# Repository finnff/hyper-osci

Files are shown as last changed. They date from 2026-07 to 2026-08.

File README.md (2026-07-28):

# HYPEROSCI

**4 battery-powered, WiFi-synchronized oscilloscopes drawing vector graphics in X/Y mode — for live performance.**

Each of the 4 slave units drives one analog oscilloscope with a stereo audio signal (L = X, R = Y). A central controller (Arduino UNO-Q running Debian) renders osci-render-style vectors as 48 kHz audio and streams it over its own WiFi access point. When the network is gone, every slave falls back within ~6 s to the proven standalone mode: its own microphone drives the scope as an audio-reactive Lissajous visualizer. No laptop on stage, no venue WiFi needed.

## Architecture

```
                     phone browser (web UI, http://192.168.50.1:8080)
                                      │
                                      ▼
        ┌─────────────────────────────────────────────┐
        │        Arduino UNO-Q  (Debian, QRB2210)     │
        │  renderer ─▶ streamer ─▶ WiFi AP (2.4 GHz)  │
        │        SSID HYPEROSCI_AP · 192.168.50.1     │
        └───────┬─────────┬──────────┬─────────┬──────┘
        UDP :5000 audio (unicast ×4) · :5001 sync/cmd · :5002 status
                │         │          │         │
                ▼         ▼          ▼         ▼
          ┌─────────┐ ┌─────────┐ ┌─────────┐ ┌─────────┐
          │ slave 1 │ │ slave 2 │ │ slave 3 │ │ slave 4 │   ESP32-C3 SuperMini
          │         │ │         │ │         │ │         │   + PCM5102A I2S DAC
          │ mic ────┤ │ mic ────┤ │ mic ────┤ │ mic ────┤   + MAX4466 mic (fallback)
          └────┬────┘ └────┬────┘ └────┬────┘ └────┬────┘   + LiPo/TP4056, custom THT carrier PCB
           X/Y ▼       X/Y ▼       X/Y ▼       X/Y ▼
          ┌─────────┐ ┌─────────┐ ┌─────────┐ ┌─────────┐
          │ scope 1 │ │ scope 2 │ │ scope 3 │ │ scope 4 │   analog scopes in X/Y mode
          └─────────┘ └─────────┘ └─────────┘ └─────────┘
```

Sync target ±5 ms via 500 ms beacons; the stream deliberately runs ~450 ms ahead of playback (512 ms slave jitter buffer) to ride out the UNO-Q radio's periodic ~300 ms stalls — latency is irrelevant for scope art, only slave-to-slave sync matters; stream loss > 1 s → automatic local-mic fallback.

## Documentation

**[docs/DESIGN.md](docs/DESIGN.md) is the single source of truth.** Where any other doc disagrees, DESIGN.md wins.

| Doc | What it is |
|-----|---|
| [docs/DESIGN.md](docs/DESIGN.md) | Canonical decisions: pin map, modules, modes, power, network (LAW) |
| [docs/PLAN.md](docs/PLAN.md) | 5-week execution plan (Jul 17 → Aug 21), critical path, risks, shopping list |
| [docs/protocol.md](docs/protocol.md) | Normative wire protocol (with [src/esp32-slave/include/protocol.h](src/esp32-slave/include/protocol.h)) |
| [docs/hardware/wiring.md](docs/hardware/wiring.md) | Complete hookup guide + bring-up checklist (breadboard now, PCB later) |
| [docs/hardware/pcb.md](docs/hardware/pcb.md) | Carrier PCB: full BOM, power path, layout notes |
| [docs/hardware/power-budget.md](docs/hardware/power-budget.md) | Current draw, battery life, low-battery policy derivation |
| [docs/firmware/esp32-architecture.md](docs/firmware/esp32-architecture.md) | Slave firmware architecture (tasks, drivers, buffers) |
| [docs/osci-render-feature-port-feasibility.md](docs/osci-render-feature-port-feasibility.md) | What else is worth porting from osci-render (fonts, SVG, effects), measured on the board — and the 6 bugs found while looking, all now fixed (§1) |
| [docs/performance-heat-analysis.md](docs/performance-heat-analysis.md) | Why the slave runs hot and why streaming dropped (2026-07-18), with the prioritized fix plan |
| [docs/hardware/pcb-review-findings.md](docs/hardware/pcb-review-findings.md) | 2026-07-26 adversarial design review of the carrier's §4 power path (findings + verdicts) |
| [docs/research/](docs/research/) | Historical planning docs — superseded where they conflict with DESIGN.md |

Research index: [v3.md](docs/research/v3.md) (feasibility) · [v3.1-requirements.md](docs/research/v3.1-requirements.md) (confirmed requirements) · [v3.2-dual-dac.md](docs/research/v3.2-dual-dac.md) (DAC selection) · [UNO-Q_controller.md](docs/research/UNO-Q_controller.md) (controller architecture — note: its whole software stack is illustrative and was NOT built as described: no FastAPI/WebSocket/hostapd, and its 5 GHz AP config is wrong — see DESIGN.md §2 and src/unoq-controller/README.md for what exists) · [esp32-c3-vs-s3.md](docs/research/esp32-c3-vs-s3.md) · [arduino-uno-r4-option.md](docs/research/arduino-uno-r4-option.md) · [README-original.md](docs/research/README-original.md)

## Hardware summary

Per slave (modules socketed on a custom ~70 × 50 mm through-hole carrier PCB — see [docs/hardware/pcb.md](docs/hardware/pcb.md)):

| Module | Role |
|---|---|
| ESP32-C3 SuperMini | MCU, WiFi, I2S master |
| GY-PCM5102A | 24-bit stereo I2S DAC → scope X/Y via 2× RCA pads (X = L, Y = R), ground-centered DC-coupled |
| MAX4466 | electret mic (on a ~10 cm pigtail) for fallback/hybrid mode |
| TP4056 (USB-C, with protection) + EEMB LP103454 LiPo 3.7 V 2000 mAh | power (~13 h NETWORK / ~30 h LOCAL) |

Scope output is 2× RCA flying-lead pads (X = DAC L, Y = DAC R, series R fitted as 0 Ω links — the DAC module already carries ~470 Ω of its own) driving reused ~50 cm RCA cables into each scope's existing BNC→RCA adapter — no BNC/TRS on our board. Enclosure: 3D-printed case (4× M3 mounts), LiPo mounted off-PCB.

Controls per unit: power switch, mode button (NETWORK / LOCAL / HYBRID), filter-cutoff pot, 2 status LEDs. Controller: 1× Arduino UNO-Q (4 GB, Debian). Pin map and all constants: [src/esp32-slave/include/config.h](src/esp32-slave/include/config.h) — **canonical, do not improvise**.

## Status (2026-07-28)

- [x] Research + feasibility (docs/research/)
- [x] Design locked ([docs/DESIGN.md](docs/DESIGN.md))
- [x] Hardware modules owned/ordered (SuperMinis, DACs, mics, chargers, UNO-Q — arrived, Debian 13 trixie aarch64)
- [x] Slave firmware (`src/esp32-slave/`): full audio/network/mode stack — AsyncUDP audio RX, 512 ms jitter buffer + concealment, local mic/pattern renderers, console; unit #1 on breadboard streams end-to-end
- [x] UNO-Q controller app **deployed** (`hyperosci-controller` systemd service): streamer + web UI + patterns/Hershey-font text (accents composed from the face's own strokes)/effects/presets — [src/unoq-controller/README.md](src/unoq-controller/README.md). osci-render was built for aarch64 but deliberately **not** integrated (no headless entry point — [docs/text-rendering-findings.md](docs/text-rendering-findings.md))
- [x] Six controller bugs found by the feature-port study fixed and deployed 2026-07-22, including the one that had the daemon beaconing out of the USB tether instead of the AP — slave 121 now receives audio ([docs/…feasibility.md §1](docs/osci-render-feature-port-feasibility.md))
- [x] Boots unattended 2026-07-22: `hyperosci-ap` now autoconnects (it never did — that, not the controller, was the real "no slaves discovered yet…"), the USB tether holds a fixed `10.42.0.5` alongside DHCP, and the dashboard names the AP-down case instead of showing an empty list. Cold boot to streaming: 18 s ([src/unoq-controller/STATUS.md](src/unoq-controller/STATUS.md))
- [x] Survives a power cut with no laptop 2026-07-22: the live pattern persists to `~/hype_state.json` and is restored before the first audio block, presets keep one generation of undo, and a root `hyperosci-netwatch` timer re-ups the AP (and bounces it on the documented ath10k wedge). Regression checks in [src/unoq-controller/tests/](src/unoq-controller/tests/) — run them **on the board**
- [x] Carrier PCB designed & **ordered 2026-07-28** — JLCPCB, qty 10, DHL Express (DDP), $45.42 landed, arriving **Aug 5–7** (order gate was ~Aug 1; met three days early — see [docs/PLAN.md](docs/PLAN.md)). ⏳ Production is paused until the production file is confirmed by email. **Routed and gate-clean as of 2026-07-28** — the pre-fab DFM pass moved copper and killed router seed 11; a 16-variant re-sweep found exactly one clean result (**seed 33**, now the default) and the board is 1343 segments / 48 GND vias / 0 unconnected / 0 DRC violations, with the width tables regenerated from the routed copper. **Nothing gates the plot any more:** SW1 was the last item and it closed 2026-07-28 off the SS12D00 drawing — 2.5 mm pitch (neither value the footprint was drawn for, and 0.05 mm off the centre of the slot's window), body 8.5 × 3.7 mm on the pin centreline, no layout change. **The fab package is plotted and committed** to [`hw/carrier/fab/`](hw/carrier/fab/); `tools/plot_fab.py` regenerates it and refuses to write the zip unless the board still passes. Detail: [`hw/carrier/layout-notes.md`](hw/carrier/layout-notes.md)
- [ ] 4-slave sync demo (slaves 2–4 not yet on breadboards; 3 built slaves need reflashing for the lost-packets counter)
- [ ] Assembly + venue rehearsal (show 2026-08-21)

## Repository layout

```
docs/                 all documentation (DESIGN.md = canon)
  research/           original v3 planning docs (historical)
  hardware/           wiring, power budget, PCB
  firmware/           firmware architecture
  protocol.md         normative wire protocol
  PLAN.md             5-week execution plan
src/esp32-slave/      PlatformIO project — slave firmware
src/unoq-controller/  UNO-Q controller app (streamer + renderer + web UI, deployed)
hw/carrier/           KiCad carrier PCB — generated end-to-end by tools/*.py
```

The repo root also carries two gitignored third-party binaries: `arduino-flasher-cli` (UNO-Q Debian flasher) and `osci-render-premium-linux.zip` (x86-64 only — does not run on the aarch64 UNO-Q; kept for desktop reference. The controller renders natively instead, see [docs/text-rendering-findings.md](docs/text-rendering-findings.md)).

## Quickstart

Slave firmware build/flash instructions: **[src/esp32-slave/README.md](src/esp32-slave/README.md)** (PlatformIO + pioarduino platform, USB-C CDC console).

One rule worth repeating from DESIGN.md §9: **during breadboard bring-up, never plug in USB-C while the battery power switch is ON** — SuperMini clones tie VBUS to the 5 V pin (meter-confirmed 2026-07-18) and would back-feed the battery. Flash with the switch OFF. The carrier PCB's load-sharing power path is *intended* to remove this rule, but design review (2026-07-26) found the SuperMini-side detection unreliable against a sagging laptop port — so treat the rule as permanent until `docs/hardware/pcb.md` §4.4 passes on an assembled board.

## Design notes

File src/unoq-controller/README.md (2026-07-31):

# unoq-controller — HYPEROSCI controller app

**Status: implemented and running in production on the UNO-Q** as the systemd
service `hyperosci-controller` (deployed at `/home/arduino/hype_controller.py`).
Board access, build notes and the change log live in [STATUS.md](STATUS.md).

## What exists today

One file does everything: [`tools/hype_controller.py`](tools/hype_controller.py)
(pure Python 3 stdlib — no FastAPI, no numpy, no external deps). It is:

1. **Streamer** — implements [docs/protocol.md](../../docs/protocol.md) /
   [protocol.h](../esp32-slave/include/protocol.h): 988-byte `HYPE_AUDIO`
   packets (240 stereo frames, 48 kHz/16-bit, L=X R=Y) every 5 ms, UDP
   **unicast** to every discovered NETWORK/HYBRID slave on port 5000, deadline
   timestamps run `LEAD_US = 450 ms` ahead (rides the UNO-Q ath10k AP's
   ~300 ms radio stalls against the slave's 512 ms jitter buffer);
   `HYPE_SYNC` multicast beacon every 500 ms and `HYPE_CMD` JSON on 5001;
   1 Hz `HYPE_STATUS` listener + slave discovery on 5002 (accepts ≥ 55-byte
   payloads; parses `local_pattern` and `lost_packets` when present).
2. **Renderer** — `PatternGen`: circle / lissajous / rose, plus **text** in
   Hershey single-stroke vector fonts (6 faces from the `hershey-fonts-data`
   package, multi-line with per-line centering, amplitude-pulse and spin LFOs,
   X/Y mirror for scope deflection polarity). A `.jhf` file holds printable
   ASCII and nothing else, so accented letters are **composed**: NFD-decompose,
   draw the base glyph from the face, add the combining mark from `_MARKS` in
   the face's own units (14 marks — acute through ogonek); anything with no
   base at all folds to ASCII (`ß`→`ss`, curly quotes, dashes). `é` is a real
   `e` under a real acute, not a `?`. Text is prebuilt into a
   2000-point equal-arc-length table (constant beam speed — osci-render's
   algorithm, see
   [docs/text-rendering-findings.md](../../docs/text-rendering-findings.md));
   the 5 ms hot loop only walks the table. osci-render itself was evaluated
   and **not** integrated (no headless entry point — same doc).
3. **Web UI** — single embedded page (stdlib `http.server`, port 8080,
   no external assets so it works on the AP without internet):
   <http://192.168.50.1:8080> (on `HYPEROSCI_AP`) or <http://10.42.0.5:8080>
   (USB tether). Pattern/text/effect controls with live canvas preview,
   stream on/off, per-slave draw mode (stream/hybrid/mic/local patterns),
   identify/gain/reboot, per-second health rates (rx/drop/lost/under).
   When no slave is listed the panel distinguishes the two causes: if
   `/api/state`'s `net.egress` is false, nothing holds `192.168.50.1`, so the
   AP is down and no slave *can* appear — it says so in red rather than
   "no slaves discovered yet…". See [STATUS.md](STATUS.md).
4. **Persistence** — the live pattern is saved to `~/hype_state.json` (3 s
   debounced, on its own thread, atomic replace) and restored before the text
   table is built, so a reboot comes back drawing what was on the scopes
   rather than a default circle. It is validated by the same `clean_preset()`
   as a preset, so a corrupt file degrades to defaults instead of stopping
   the daemon. `stream_on` is deliberately not persisted — a rig that boots
   silent is worse than one that boots drawing.
5. **Presets** — up to 20 named snapshots of the whole streamed-pattern panel
   (artist names for stage changeovers), persisted at
   `~/hype_presets.json` across restarts. Every field is optional on load and
   filled from `PRESET_DEFAULTS`, so adding a field to a later build cannot
   drop a preset written by an earlier one; values are clamped and the font
   whitelisted in `clean_preset()`, on both the file and the load path.
   `op=save` overwrites a same-named preset in place, so the page offers both
   **`⟳ update "<name>"`** (rewrite the preset you last applied — the button
   names its target so there is no doubt what gets replaced) and
   **`+ save as…`** (a new name). Which preset is "current" is a client-side
   notion kept in `localStorage`; the controller has no session, and a phone
   that locked its screen still comes back able to update the right one.
6. **Interval timers** — up to 8 rules of the form *"show preset **IDENT** on
   slaves 1+2 for 20 s every 5 minutes"*, persisted at `~/hype_timers.json`.
   A rule fires on its own thread (`timer_loop`, same reasoning as
   `persist_loop`: a font rebuild on the stream thread is an audible gap on
   every scope): the preset goes on air, the targeted slaves are switched to
   STREAM, and when the hold expires both the pattern and each target's
   previous draw setting are put back. Targets are slave **ids**, not ips, so
   a rule survives a DHCP lease.

   Three things worth knowing:
   - **There is one streamed pattern for the whole rig.** Targeting slaves
     1+2 switches *those* to STREAM; a slave already on STREAM/HYBRID sees
     the same figure for the duration. Nothing forces a non-target off the
     stream — that would be a bigger intervention than the rule asked for.
   - **Touching the pattern panel ends a hold early**, keeping what the
     operator just set. Reverting them fifteen seconds later is worse than
     the rule missing a cycle.
   - **A hold is never persisted** as the live pattern, and a fire is
     refused for `HOLD_COOLDOWN_US` after a release — a slave's mode is only
     known from its 1 Hz STATUS beacon, so firing inside that window would
     record the forced mode as the "previous" one and strand it on STREAM.

HTTP API: `GET /api/state`, `GET /api/textpreview`; `POST /api/pattern`,
`POST /api/cmd` (per-slave HYPE_CMD), `POST /api/preset` (op=save|load|delete),
`POST /api/timer` (op=save|delete|toggle|fire).

`deploy/hyperosci-netwatch` (+ `.service`/`.timer`) is a separate root-owned
watchdog that every 30 s re-activates `hyperosci-ap` if nothing holds
192.168.50.1, and bounces it if no slave has *received a packet* for three
consecutive checks. It is not part of this process on purpose — the stream
loop must never fork. See [STATUS.md](STATUS.md) for why "every slave is on
its mic" alone is not a safe trigger.

`tools/hype_sender.py` is the original minimal streamer, kept only as a
protocol reference — never run both (they fight over port 5002).

## Deviations from the original plan (kept deliberately)

- **AP** is a NetworkManager connection `hyperosci-ap` (SSID `HYPEROSCI_AP`,
  2.4 GHz **channel 11**, autoconnect on with unlimited retries, controller at
  **192.168.50.1/24**) — not hostapd+dnsmasq and not 192.168.4.1 (10.42.x and
  .4.x collided with the USB tether; see STATUS.md). Channel was 6 until
  2026-07-22; re-pick it at the venue, STATUS.md has the one-liner.
- **Single-file app**, not the `hyperosci/{streamer,renderer,web}` package
  layout once sketched here — at this size the one file is easier to deploy
  (scp + restart) and to keep in lockstep with the firmware.
- The "laptop streamer stand-in" phase was skipped — the UNO-Q arrived in
  time and bring-up happened directly on it. Any Linux laptop can still run
  `hype_controller.py` unchanged as the show-day fallback controller.

## Design notes (still canonical)

- `protocol.h` is the canonical wire format; the Python side mirrors it with
  `struct` pack strings and must round-trip byte-exact. All fields
  little-endian. Never redefine constants — mirror them.
- Timestamps are the controller's monotonic clock in µs
  (`time.monotonic_ns() // 1000`); `HYPE_AUDIO.timestamp_us` is the playback
  deadline of the packet's first frame.
- Transmission is paced from the audio clock with deadline catch-up bursts,
  not `sleep()` drift; pacing drift > 20 ms re-anchors the epoch once,
  cleanly.
- The embedded web page (`PAGE`) is a **plain** triple-quoted Python string:
  a `\n` typed into its JavaScript becomes a real newline in the served
  source (this broke the dashboard once). Write `\\n` and syntax-check with
  `node --check` on the extracted `<script>` after editing.

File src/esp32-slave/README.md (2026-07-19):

# HYPEROSCI slave firmware (ESP32-C3 SuperMini)

Firmware for one slave unit: receives X/Y audio from the controller over WiFi
and drives a PCM5102A DAC into an oscilloscope in XY mode, with autonomous
mic-based fallback (the old proven Lissajous behavior).

Canonical references: [docs/DESIGN.md](../../docs/DESIGN.md) (decisions),
[docs/protocol.md](../../docs/protocol.md) (wire protocol),
[docs/hardware/wiring.md](../../docs/hardware/wiring.md) (hookup).

## Build & flash

Uses PlatformIO with the [pioarduino](https://github.com/pioarduino/platform-espressif32)
platform (Arduino core 3.x on ESP-IDF 5.x — required for the `i2s_std` and
`adc_continuous` drivers).

```sh
pio run                    # build
pio run -t upload          # flash over USB-C (power switch OFF — see wiring.md!)
pio device monitor         # 115200 baud, USB CDC
```

## Module map

| File | Role |
|---|---|
| `include/config.h` | **canonical** pins/constants (mirrors DESIGN.md §4) |
| `include/protocol.h` | **canonical** wire format (shared with controller) |
| `src/main.cpp` | task setup and glue |
| `src/audio_out.*` | I2S master TX → PCM5102A (48 kHz/16-bit stereo, no MCLK) |
| `src/mic_in.*` | `adc_continuous` DMA: mic 24 kHz + vbat + pot; DC blocker |
| `src/renderer_local.*` | fallback renderer: X=mic, Y=Butterworth LPF (pot 20–300 Hz); circle/Lissajous/ramp/square test patterns (ramp = DC test, square = filter-ringing test) |
| `src/jitter_buffer.h` | SPSC frame ring with master-clock deadline tracking |
| `src/timesync.*` | SYNC-beacon offset tracking (median of 8) |
| `src/net_rx.*` | WiFi STA, UDP audio/ctrl RX, deadline policy, status TX |
| `src/mode_manager.*` | LOCAL/NETWORK/HYBRID state machine + auto-fallback, NVS settings, JSON commands |
| `src/ui.*` | buttons, LED patterns, battery policy, serial console |

## Task layout (single core)

| Task | Prio | Period | Job |
|---|---|---|-----|
| `audio` | 10 | 5 ms (paced by I2S DMA) | pull block from active source → I2S |
| `net_rx` | 5 | 1 ms poll | WiFi mgmt, UDP RX → jitter buffer, 1 Hz status |
| Arduino `loop` | 1 | 10 ms | buttons, LEDs, battery, console |

## Serial console (USB-C, 115200)

`help` · `stat` · `mode <local|net|hybrid>` · `pat` (cycle test pattern) ·
`gain <0-100>` · `wifi <on|off>` · `id <0-255>` · `reboot`

## Status / TODO

- [x] Compiling skeleton with all modules and the full mode state machine
- [x] Packet-loss concealment (deadline-continuity buffer: ≤20 ms holes
      hold-filled; hold → ramp-to-center → 1 s mic fallback ladder)
- [ ] Bench bring-up: I2S output on a real scope (circle, then `pat` → ramp for
      the DC go/no-go test, square for filter ringing)
- [ ] Bench bring-up: mic path + pot filter (compare with old sigma-delta unit)
- [x] Network test against the UNO-Q controller (the laptop stand-in phase was
      skipped — the UNO-Q arrived in time and streams end-to-end since 2026-07-18)
- [ ] Clock-drift compensation (single-frame slip/insert per protocol.md §5.3)
      — v1 corrects in whole 5 ms blocks at the window edge; fine for the ±5 ms
      spec, revisit if scopes drift apart visibly over long sets
- [ ] Offset slewing in timesync (protocol.md §4.2 RECOMMENDED; v1 = direct median)
- [ ] WiFi credentials via console/NVS (currently compile-time defaults)

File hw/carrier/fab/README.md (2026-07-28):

# Fab package — HYPEROSCI carrier v1.1

Generated 2026-07-28 from `carrier.kicad_pcb` at commit `c1c3b11` (router seed 33),
working tree clean. **Upload `hyperosci-carrier-v1.1-gerbers.zip`.**

> **Re-plotted 2026-07-28 for the back-silk artwork.** The first set was plotted at
> `ddcbc13`, one commit before the `48` mark and `ponkiePCBv1` wordmark were added to
> B.Silkscreen, so its `carrier-B_Silkscreen.gbo` had **zero region fills** — the artwork
> was simply not in it. Nothing warned about this: the board was correct, every gate
> passed, and `plot_fab.py`'s own checks are copper/drill geometry, which did not change.
> **Any edit to a plotted layer silently invalidates this directory; re-run `plot_fab.py`.**
>
> Two things that make a diff of this directory confusing, both benign:
>
> - **The copper is unchanged and that was verified, not assumed.** Aperture draws are
>   identical (F.Cu 1952 = 1952, B.Cu 1168 = 1168), and the zone fills in the board file
>   are identical between the two commits to 1e-6 mm² (F.Cu 1720.834491, B.Cu 1943.652053)
>   with the same outline counts.
> - **Gerbers are not byte-reproducible across KiCad builds.** The first set came off
>   `10.0.5-1.fc44`, this one off `10.0.5-10.0.5~ubuntu24.04.1`. The two emit pour region
>   vertices with ~3 nm differences (e.g. `18804538` vs `18804535`) and one outline drops
>   3 collinear points, 382 → 379. That is rounding, not geometry. Do not read a large
>   `git diff` on `carrier-F_Cu.gtl` as copper having moved — compare aperture draws and
>   fill areas, not bytes.

Regenerate with `/usr/bin/python3 tools/plot_fab.py` from `hw/carrier/` — do not hand-edit
the gerbers. That script re-runs DRC, plots, asserts every mechanical item on the
`pcb.md` §8.4 checklist, and writes the zip only if all of them hold.

## Order parameters (from `docs/hardware/pcb.md` §8.3)

| | |
|---|---|
| Layers | 2 |
| Size | 70 × 50 mm |
| Qty | 5 |
| Material | FR-4 TG135+ |
| Thickness | 1.6 mm |
| Outer copper | 1 oz |
| Surface finish | HASL, lead-free |
| Mask / silk | green / white |
| Castellations, impedance control, stencil | none |
| Order number | "specify location" — placed on the **back**, under the TP4056 module (`TP4056` legend on B.Silkscreen marks the spot) |

## Zip contents

| File | Layer |
|---|---|
| `carrier-F_Cu.gtl` | Copper, L1, Top |
| `carrier-B_Cu.gbl` | Copper, L2, Bottom |
| `carrier-F_Mask.gts` | Soldermask, Top |
| `carrier-B_Mask.gbs` | Soldermask, Bottom |
| `carrier-F_Silkscreen.gto` | Legend, Top |
| `carrier-B_Silkscreen.gbo` | Legend, Bottom |
| `carrier-Edge_Cuts.gm1` | Profile (board outline) |
| `carrier.drl` | Excellon drill, PTH+NPTH merged |
| `carrier-job.gbrjob` | Gerber job file (layer stackup hint) |

No paste layers — no stencil is ordered, and the only real SMD part is Q1 (SOT-23 on
hand-solder pads). Protel extensions, RS-274X (X2 off, netlist attributes off) so the
same zip loads identically at JLCPCB and PCBWay.

## Verification run at plot time

| Check | Result |
|---|---|
| `kicad-cli pcb drc` | 0 violations, 0 unconnected |
| Edge.Cuts | 4 lines, single closed rect, exactly 70.000 × 50.000 mm |
| Copper extents | 0.500 … 69.500 / −49.500 … −0.500 (0.5 mm to the profile) |
| F.Cu flashes | 222 = 126 pads + 96 vias |
| B.Cu flashes | 212 = 116 THT pads + 96 vias |
| F/B.Mask openings | 124 / 116 regions vs 126 / 116 pads (2 merged on top) |
| Drill total | 212 plated, 0 unplated; T1 ⌀0.400 × 96 = the via count |
| **SW1 slots** (`pcb.md` §7) | **T4 = 0.900, `G00X47.08→G01X47.98` and `G00X51.98→G01X52.88` — 0.90 mm travel each, aspect 2.0** |

## Back-silk artwork — checked separately, because no gate covers it

The `48` mark plots as **4 filled G36 regions**, and every silk check this project has is
about *stroke* width. A filled polygon has none, so the DFM question — is any ink narrower
than JLC's 0.15 mm floor — was answered by rasterising the plotted gerber at 5 µm and
opening it morphologically:

| Opening disk | ⇒ min feature width | Ink kept | Features left |
|---|---|---|---|
| 0.075 mm | 0.150 mm ← JLC floor | 99.90 % | 4 of 4 |
| 0.125 mm | 0.250 mm | 99.77 % | 4 of 4 |

Nothing drops out well past the floor, and the ~0.1 % shortfall is corner rounding. A raw
skeleton measurement looks much worse — 1.4 % of ridge points under 0.15 mm, bottoming out
at 0.010 mm — and is **the wrong test**: skeletons run into every convex corner, where
width goes to zero by construction. Use the opening result.

The rest of the layer: the wordmark is stroked text at **0.1875 mm**, and the two
pre-existing legends are unchanged at **0.15 mm**. Both clear the floor.

**The `%ADD10C,0.000000*%` aperture is not a zero-width pen.** It appears only on this
layer and only ever selected *inside* G36 regions, where the Gerber spec says the current
aperture is unused; zero draws and zero flashes reference it. It is normal KiCad output for
polygon fills. Do not "fix" it.

**No silk over exposed copper:** none of the 116 B.Mask openings intersect the artwork's
bounding box, nearest 0.48 mm. The placement search that chose the spot looked at pad-clear
area on B.Cu; this confirms the result against the mask, which is the layer that matters.

## Known and accepted

**Via-in-pad on 5 SMD pads:** `Q1.1`, `Q1.2`, `TP2.1`, `TP3.1`, `TP4.1`. ⌀0.8 vias on a
0.4 mm drill, centred in 1.9 × 0.8 mm pads. The three testpoints are intentional (that
via *is* how the pad reaches its net). Q1's two are a router artifact — present in every
routed revision since `4c362ff`, so this is standing behaviour, not a seed-33 regression
(HEAD has one fewer than `e6943b5`, which also had `D2.2`). Consequence is hand-soldering
only: solder will wick to the back through a 0.4 mm hole, so feed a little extra and
expect a bead on B.Cu. Not a fab constraint and not worth risking the seed-33 route.

The §8.4 checklist item as written — "no vias inside RCA/JST pads" — passes: no
through-hole pad on the board has a via inside it.

## SW1 — closed 2026-07-28

The last gate, and it closed off the SS12D00 mechanical drawing rather than the part or
the paper doll. Nothing in the layout moved, so these gerbers are unaffected.

| | Part | Board | Margin |
|---|---|---|---|
| Pin pitch | **2.5 mm** | slot window 2.00–2.90 from the centre pin | lands 0.05 mm off slot centre |
| Pin section | 0.5 × 0.3 mm | slots 1.80 × 0.90, centre hole ⌀0.9 | 0.30 mm a side across the slot |
| Body | 8.5 × 3.7 mm, pins on the centreline | silk 9.0 × 4.0, courtyard 10.0 × 5.0 | 0.25 mm a side in X, 0.15 in Y |
| Clearance | — | TP4056 body 2.51 mm N · J8 courtyard 0.96 mm E · board edge 1.75 mm S | nothing overhangs |
| Actuator | 1.5 mm sq, 2 mm travel | sweeps X 48.23–51.73 | 3.46 mm of nail room to J8 |
| Function | middle terminal = common | pad 2 = VLOAD, pad 1 = VSW, pad 3 netless | correct |

The pitch is the interesting one: 2.5 mm is **neither** of the two values the footprint was
drawn around, and it still lands in the most comfortable part of the window. That is the
slot paying for itself.

The 6 mm handle never entered the fit — nothing sits above the switch, so handle length is
an enclosure question.

## ✅ ORDERED — JLCPCB, 2026-07-28

Three days inside the Aug 1 gate. **Qty 10**, DHL Express **(DDP)**, Confirm Production File
**on**. Landed **$45.42**.

### As ordered, and where it deviates from §8.3

| | §8.3 says | Ordered | Why |
|---|---|---|---|
| Qty | 5 | **10** | €4.39 either way; 5 more spare bare boards for nothing |
| Surface finish | HASL lead-free | **HASL with lead** | every joint on this board is hand-soldered, leaded wets better at a lower iron temperature, and nothing here is sold or RoHS-bound. §8.3 stated lead-free with no rationale anywhere in the doc |
| Mask | green | **black** | aesthetic — the `48` on white silk. Costs nothing; the price is that black hides traces if `B−`/GND ever needs probing |
| Order number | "specify location" | **Remove Mark** | JLC's current UI offers only Remove Mark or a 2D barcode. "Specify location" is no longer orderable, and removing beats letting CAM place it |

Everything else matched: 2 layers, 70 × 50, FR-4 TG135, 1.6 mm, 1 oz, white silk, single PCB,
flying-probe fully tested, tented vias, ±0.2 mm outline, no castellations / impedance control /
stencil, no assembly.

**Every capability option was left at its cheapest tier, and that is correct** — the board is
nowhere near a limit: min trace 0.30 mm and clearance 0.25 mm against JLC's 0.127 mm floor,
smallest drill 0.40 mm (the vias) against 0.30 mm, 0.20 mm annular ring against 0.13, copper
to edge 0.50 mm against 0.20. Do not pay for High Precision PCB on this design.

**Via Covering: Tented** matches the board file (`tenting front yes / back yes`), which is why
the mask gerbers carry 124/116 apertures against 126/116 pads. Epoxy fill was considered and
rejected: it would stop the via-in-pad wicking below, but that is already accepted and the fee
is not.

### PCB Remark submitted (JLC caps this field at 200 characters)

```
SW1 pads 1&3 are 1.80x0.90mm plated slots. Route as slots if possible. If not, substitute plated 0.90mm round holes at slot centres X47.53/X52.43 Y-46.40 - acceptable, do not hold the order.
```

The fallback is deliberate and safe, and the arithmetic is worth keeping. The real SS12D00 is
2.5 mm pitch against a footprint drawn at 2.45, so each outer pin sits **0.05 mm outboard** of
its slot centre. With the pin's 0.5 × 0.3 mm section, the worst corner is **0.335 mm** from the
slot centre, so the minimum round hole that still fits is ⌀0.671. **⌀0.90 clears it by
0.115 mm radially**, leaves a 0.50/0.80 mm annular ring in the 2.5 × 1.9 pad, and is the
*same T4 tool already drilling SW1's centre hole* — so the substitution costs CAM nothing.
It even improves hole-to-hole spacing, 1.10 mm → 1.55 mm.

The position was pinned to the **slot centre (2.45 pitch)**, not the part's true 2.50: asking
CAM to shift a hole 0.05 mm invites a misread, and the margin above already absorbs it.

⚠️ **If they do substitute, SW1 assembly changes** — the pins land in fixed holes instead of a
0.90 mm sliding window. Seat the switch before soldering, not after.

### Shipping — why DDP, and why it cost what it did

The **EU customs reform took effect 2026-07-01**, four weeks before this order. Every EU-bound
shipment is now formally declared regardless of value, and B2C orders under €150 carry a flat
**€3.00 temporary customs duty per line item**. The decisive detail is JLC's own: their IOSS
collects import VAT but *"cannot manage the 'temporary customs duty'"* on **non-DDP** channels
— so any non-DDP option means a doorstep invoice **plus the carrier's disbursement fee**, which
is per-shipment and unrelated to value. On a $6 board that fee alone can exceed the goods.

DHL Express (DDP) carried **no premium** over plain DHL Express, and was the fastest tier.

| | Cost | Arrives | Slack to Aug 14 | Customs |
|---|---|---|---|---|
| **DHL Express (DDP)** ← taken | €18.23 | Aug 5–7 | +7 d | **prepaid** |
| DHL Express | €18.23 | Aug 5–7 | +7 d | €3 + fee at door |
| UPS Express Saver | €21.24 | Aug 6–10 | +4 d | €3 + fee at door |
| FedEx Express | €21.57 | Aug 10–12 | +2 d | €3 + fee at door |
| EuroPacket | €6.59 | Aug 7–13 | +1 d | €3 + fee at door |
| Global Standard Direct | €1.32 | Aug 19–25 | **−11 d** | misses entirely |

EuroPacket was the only genuine saving (~$20) and was declined: one day of worst-case margin,
on a non-DDP postal channel, under a regime four weeks old. **§8.1's old advice to take FedEx
was wrong** — FedEx was the most expensive express option *and* the slowest of the three.

### Landed cost — the numbers reconcile, and the lesson is the ratio

```
goods (10 boards + confirm-production-file fee)   $  6.04
freight                                           $ 28.02
temporary customs duty                            $  3.47
                                                  --------
VAT base                                          $ 37.53  x 21% NL = $7.88  (billed $7.89) ✓
                                                  --------
grand total                                       $ 45.42                                   ✓
```

JLC's checkout displays this as "Shipping Estimate $31.49, Includes: … $7.89", which reads like
a double charge. It is not — the VAT reconciles to the cent only if the estimate is freight +
duty and VAT sits on top. **87 % of the order is shipment overhead.** Marginal boards are
nearly free (10 boards is 0.24 kg against a ~0.5 kg minimum billable), so if a future run wants
spares, buy them on the *same* shipment.

⚠️ **Unresolved, and worth watching on the next order:** the shipping table quoted DHL DDP at
**€18.23**, checkout billed **$28.02** freight. No plausible EUR/USD rate explains a $7.24 gap
(it implies 1.54). Either a DDP surcharge folded into the line, or a table discount that did
not carry into checkout.

## Still open

1. **Confirm the production file** — paid for (€0.91), so **production is paused until it is
   approved**, by email to the registered address. JLC's article states no auto-proceed and no
   expiry: the schedule below assumes a same-day response. The package has three folders —
   `yg` (what we uploaded), `ok` (what they will actually build), `info` — so it is directly
   diffable. Check `ok` for, in order of likelihood:
   1. **the drill** — do X47.53 and X52.43 (Y−46.40) still carry `M15`/`M16` routed slots, or
      did they become plain hits? Both acceptable; you need to know which, per the ⚠️ above.
   2. **no order number anywhere** — we asked for Remove Mark.
   3. **B.Silkscreen** — `48` and `ponkiePCBv1` present and unclipped. CAM sometimes trims silk
      near mask openings; nearest is 0.48 mm so it should survive, and this is the one layer
      with no automated gate.
   4. **Edge.Cuts** — still one closed 70 × 50 rect.

   `tools/plot_fab.py`'s gates can be re-asserted against JLC's `ok` gerbers instead of ours,
   which turns this from eyeballing a render into an actual check.

2. **Second viewer load** (`gerbv` or tracespace). Partly discharged already: JLC's own
   uploader detected the outline as 50 × 70 mm, showed drills present, and rendered `48` /
   `ponkiePCBv1` reading correctly on the back — so **not mirrored**. What a second viewer
   still adds is copper/mask alignment.

3. **On arrival, assembly not ordering:** whether the switch carries a locating lug. The
   drawing has no bottom view and dimensions no post, so paper cannot settle it;
   `SW_Slide_SPDT_DualPitch` has the three signal holes only, so clip any lug.

### Expected schedule

| | |
|---|---|
| Ordered | Tue Jul 28 |
| Production file confirmed | ~Wed Jul 29 ← **gated on you** |
| Build complete (3 days) | ~Mon Aug 3 |
| **Arrives (DHL 2–4 business days)** | **Aug 5–7** |
| Deadline | Fri Aug 14 — **7 days slack** |

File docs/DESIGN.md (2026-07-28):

# HYPEROSCI — Canonical Design Decisions

**Date:** 2026-07-17
**Status:** LOCKED for slave v1 hardware/firmware. Changes to this file require updating every doc/code file that references it.
**Deadline context:** ~5 weeks (target: PCBs ordered, assembled, and firmware running by ~2026-08-21).

This file is the single source of truth. The research history lives in [docs/research/](research/). Where this file contradicts a research doc, **this file wins**.

---

## 1. System snapshot

4 battery-powered slave units, each driving one oscilloscope in X/Y mode. Each slave = **ESP32-C3 SuperMini + PCM5102A I2S DAC module + MAX4466 mic**, on a custom through-hole carrier PCB. A central controller (Arduino UNO-Q) generates osci-render X/Y audio and streams it over its own WiFi AP. Every slave falls back to standalone mic→scope visualization when the network is absent.

The UNO-Q controller has **arrived** (Debian 13 "trixie", aarch64) and doubles as the on-stage 2.4 GHz WiFi AP — **no laptop on stage**. Any "laptop streamer" stand-in language elsewhere refers to a Python test-streamer running on the UNO-Q itself, standing in for full osci-render integration.

```
UNO-Q (WiFi AP, 2.4 GHz) ──UDP──▶ 4× [ESP32-C3 ──I2S──▶ PCM5102A ──▶ scope X/Y]
                                        ▲
                                   MAX4466 mic (fallback + hybrid mix)
```

## 2. Corrections to earlier research docs (important)

1. **The AP must run on 2.4 GHz, not 5 GHz.** ESP32-C3 (and S3) are 2.4 GHz-only. The hostapd config in `research/UNO-Q_controller.md` (`hw_mode=a`, channel 36) will not work with the slaves. Use `hw_mode=g`, channel 1/6/11, and do a channel scan at the venue.
2. **Default transport is 4× UDP unicast, not multicast.** WiFi multicast is transmitted at the lowest basic rate with no retries and is often throttled/dropped by APs; unicast gets MCS rates + link-layer retries. With only 4 slaves at ~1.6 Mbps each, unicast is trivially affordable (~6.5 Mbps total). Slaves are transport-agnostic: they bind the audio port and also join the multicast group, so the controller can use either.
3. **Modem power-save must be OFF on slaves while streaming** (`WiFi.setSleep(false)`), otherwise DTIM buffering adds 100+ ms of jitter. This is the main reason network mode draws ~100 mA.

## 3. Per-slave bill of materials (modules)

| # | Module | Role | ~Price | Notes |
|---|---|---|---|---|
| 1 | ESP32-C3 SuperMini | MCU, WiFi, I2S master | €3 | already owned ×4 |
| 2 | GY-PCM5102A (purple module) | 24-bit stereo DAC → scope X/Y | €2 | already ordered ×4 |
| 3 | MAX4466 electret mic module | fallback/hybrid audio input | €1.50 | already owned ×4 |
| 4 | TP4056 charger module (**USB-C variant**, blue PCB 17×27 mm, **with** DW01+FS8205 protection) | LiPo charging + protection | €0.50 | 1 A default charge kept (RPROG swap to 0.5 A optional); **mandate 5 V / 2 A wall chargers** so 1 A (~0.5C, full ~2.5–3 h) is safe |
| 5 | LiPo 3.7 V, **~2000 mAh** — reference part EEMB LP103454 (34×56×11 mm, ~40 g, pre-fitted JST); **sourced from Amazon as of 2026-07-27** | power | — | mounted off-board (loose in the enclosure, velcro/pocket); 1000 mAh is a smaller-cell reference only. A substituted cell must bring a **JST-PH 2.00 mm** lead, and its **polarity must be metered before first plug-in** — `B−` is not GND (pcb.md §1/§3.1) |
| 6 | Carrier PCB (this project) | ties it all together | ~€1–2/board | v1.1 laid out; THT except Q1 (SOT-23) + D2 (SMA) |

Carrier-board discrete parts (full BOM in [hardware/pcb.md](hardware/pcb.md)): slide power switch (**SS12D00**, 6 mm handle — the 0.3 A make/break rating is accepted at 4 V, §5), mode button (6×6 mm tactile), 10 kΩ potentiometer (filter-cutoff; **RV097NS** 9 mm PCB-mount, B10K, 5-pin **mono with switch**, right-angle, metal shaft turned directly — no knob; the switch is unused, both ends on GND), 2× 3 mm LED + resistors, battery divider (2× 100 kΩ + 100 nF), 10 kΩ pull-up for GPIO2, bulk electrolytic (≥220 µF) on the battery rail, **2× RCA flying-lead output pad-pairs** (signal + ground; X = PCM5102A L, Y = PCM5102A R) driving the reused ~50 cm RCA cables — series R10/R11 feed the pads, **fitted as 0 Ω wire links** (the DAC module carries its own ~470 Ω output filter, so 100 Ω adds nothing measurable; [hardware/pcb.md](hardware/pcb.md) §3.2 / §10 Q2, closed 2026-07-28), female pin-header sockets for the SuperMini/DAC/TP4056 modules, and a **3-pin pigtail header (VCC / GND / OUT)** for the MAX4466 (on a ~10 cm cable, not a flat on-board footprint).

## 4. Canonical pin map (ESP32-C3 SuperMini)

Mirrors `src/esp32-slave/include/config.h`. **This table is law** — do not use different pins anywhere.

| GPIO | Function | Direction | Notes |
|---|---|---|---|
| 0 | `MIC_ADC` — MAX4466 OUT | in (ADC1_CH0) | mic biased at VCC/2 (same pin as the old proven unit) |
| 1 | `VBAT_ADC` — battery divider | in (ADC1_CH1) | 100k/100k ÷2, 100 nF to GND across bottom R |
| 2 | **unused** | — | strapping pin (must be high at reset) — leave NC, fit 10 kΩ pull-up to 3V3 on carrier |
| 3 | `POT_ADC` — 10 kΩ pot wiper | in (ADC1_CH3) | performance knob: local Y-filter cutoff 20–300 Hz (carried over from the old unit, same pin) |
| 4 | `I2S_BCK` → PCM5102A BCK | out | |
| 5 | `I2S_LRCK` → PCM5102A LCK | out | |
| 6 | `I2S_DOUT` → PCM5102A DIN | out | |
| 7 | `BTN_MODE` | in, pull-up | momentary to GND |
| 8 | onboard blue LED | out | **active-low**, strapping pin, heartbeat only |
| 9 | onboard BOOT button | in | strapping; readable after boot as secondary button |
| 10 | `LED_NET` (green) | out | see LED semantics §7 |
| 20 | `LED_MODE` (amber) | out | (UART0 RX repurposed — console is USB-C CDC) |
| 21 | UART0 TX | out | debug header, reserved (log output if USB CDC unavailable) |

Design rules applied: **no signals on strapping pins** (2, 8, 9); all three ADC1 inputs (mic, vbat, pot) on GPIO0/1/3; PCM5102A XSMT is not MCU-controlled in v1 (module bridge 3 soldered high — the DAC idles at 0 V for digital zero, so power-on pop is a non-issue for a scope).

**Continuity with the proven unit** (`~/Arduino/esp32c3SIGMADELTA`): mic stays on GPIO0, pot stays on GPIO3, and the local-mode Y filter reuses its exact 2-pole Butterworth (Q = 0.7071) with pot-mapped cutoff. What changes: output moves from 8-bit sigma-delta on GPIO1 to the PCM5102A (both X and Y now MCU-driven), and sampling moves from 20 kHz blocking `analogRead` to 24 kHz DMA.

## 5. PCM5102A module configuration (GY-PCM5102, purple)

Back-side solder bridges (must be soldered — modules often ship open):

| Bridge | Pin | Set to | Meaning |
|---|-----|---|---|
| 1 | FLT | **L** | normal latency filter (try H = low-latency later; may reduce ringing on sharp vector edges) |
| 2 | DEMP | **L** | de-emphasis off |
| 3 | XSMT | **H** | un-muted. (MCU mute control was considered and rejected for v1 — every candidate pin is taken; the DAC's 0 V idle makes it unnecessary for a scope.) |
| 4 | FMT | **L** | I2S format |

Front: **SCK pin tied to GND** → DAC generates its internal clock via PLL from BCK (no MCLK needed from ESP32).

Key electrical facts (⚠️ VERIFY items covered in verification checklist §12):
- Output is **ground-centered, DC-coupled** (internal charge pump makes a negative rail). Full-scale ≈ 2.1 V RMS ≈ ±3 V peak — ideal for scope X/Y, no offset knobs needed.
- BCK ratio of 32× fs (16-bit stereo) is supported by the PLL.
- Module VIN feeds an onboard XC6206 3.3 V LDO; feeding VIN from the SuperMini's 3V3 rail works (dropout at ~20 mA is small), giving the DAC ~3.25 V at healthy battery. Caveat: below ~3.3–3.4 V battery the double-LDO cascade puts the DAC under its recommended minimums (CPVDD/DVDD 3.1 V, AVDD 3.0 V) — visuals may lose amplitude near end-of-charge; verify during the battery-rundown test.

## 6. Audio & signal parameters

| Parameter | Value | Rationale |
|---|---|---|
| Output sample rate | **48 000 Hz**, 16-bit stereo (L=X, R=Y) | fixed for v1, everywhere |
| Mic ADC | `adc_continuous`, 3 channels (mic + vbat + pot) at **24 kHz each** (72 kHz total, C3 DMA limit is ~83 kHz) | mic upsampled ×2 (linear interp) to 48 kHz; vbat/pot decimated in software |
| Local fallback pattern | X = DC-blocked mic, Y = 2-pole Butterworth LPF of mic, cutoff = pot (20–300 Hz) | exact filter from the proven old unit |
| I2S block size | 240 frames (5 ms) | matches network packet size |
| Jitter buffer | 24576-frame ring (**512 ms** capacity), start gate 60 ms; steady depth = controller lead (450 ms) | sized to ride the UNO-Q ath10k AP's ~300 ms radio stalls; latency is irrelevant for scope art — only slave-to-slave sync matters (updated 2026-07-18 from the original 8192/~170 ms/60 ms once the stalls were measured) |
| Sync accuracy target | ±5 ms (per v3.1 requirement) | beacon-based offset, no RTT compensation needed in v1 |

## 7. Modes, LEDs, buttons (UX spec)

**Modes:** `LOCAL` (mic only), `NETWORK` (stream only, auto-falls-back to local if stream lost >1 s), `HYBRID` (stream + mic mixed 50 %). Boot default: NETWORK with auto-fallback (i.e. power-on with no controller ⇒ behaves like the old mic units within ~6 s: 5 s WiFi timeout + 1 s stream timeout).

> **Open (not blocking anything):** HYBRID mixes each slave's *own* mic (`HYBRID_MIC_GAIN` 50 %,
> saturating add — see [firmware/esp32-architecture.md](firmware/esp32-architecture.md)). The
> alternative — one mic into the UNO-Q, mixed centrally into all four streams — is a possible v2.
> Per-slave local mixing is canon until Finn says otherwise.

**LED semantics:**

| LED | Pattern | Meaning |
|-----|---|---|
| NET (green) | off | WiFi radio off / not configured |
| | 1 Hz blink | connecting / connected but no stream |
| | solid | receiving audio stream |
| | 5 Hz blink | connected, stream lost (fallback active) |
| MODE (amber) | off | NETWORK mode |
| | solid | LOCAL mode |
| | 1 Hz blink | HYBRID mode |
| onboard blue | 1 s heartbeat (50 ms flash) | firmware alive |
| | 3 fast blinks / 2 s | battery low (< 3.45 V) |

**Buttons:**

| Action | Effect |
|---|---|
| MODE short press | cycle NETWORK → LOCAL → HYBRID |
| MODE long press (≥2 s) | toggle WiFi radio (battery save / force standalone) |
| MODE held at power-on | boot straight into LOCAL, WiFi off |
| BOOT short press (after boot) | cycle local test pattern (mic → circle → Lissajous → ramp → square; ramp = §12 DC test, square = §12 ringing test) |

**Pot (10 kΩ, GPIO3):** in LOCAL/HYBRID modes sets the Y-channel low-pass cutoff (20–300 Hz), exactly like the old unit. Ignored in pure NETWORK mode (reserved for a future streamed-effect parameter).

## 8. Network & protocol summary

Normative spec: [docs/protocol.md](protocol.md) + `src/esp32-slave/include/protocol.h`.

| Item | Value |
|---|---|
| AP | SSID `HYPEROSCI_AP` / WPA2 `hyperosci2026`, **2.4 GHz** ch 6, controller at **192.168.50.1/24** (NetworkManager conn `hyperosci-ap`; 10.42.x/192.168.4.x collided with the USB tether) |
| Audio | UDP port **5000** (unicast to each slave; multicast 239.0.0.1 also joined) |
| Control + sync | UDP port **5001** (SYNC beacon every 500 ms from controller; JSON commands unicast) |
| Status | UDP port **5002** (each slave → controller, 1 Hz binary status) |
| Packet | 20-byte `HYPE` header + type-specific payload; audio = 240 stereo frames (988 B) |
| Clock | controller monotonic µs; slaves track offset from SYNC beacons (smoothed), packets carry playback deadline timestamps |
| Slave identity | derived from MAC (last octet), overridable via serial console |

## 9. Power architecture

```
LiPo ──▶ TP4056 module (charge via its own USB; DW01 protection) ──▶ OUT+
     OUT+ ──▶ power slide switch ──▶ SuperMini 5V pin ──▶ onboard LDO ──▶ 3V3 rail
     3V3 rail ──▶ PCM5102A VIN, MAX4466 VCC, LEDs, pull-ups
     LiPo+ ──▶ 100k/100k divider ──▶ GPIO1 (always connected, 21 µA)
```

**Breadboard/bring-up rule:** never have the power switch ON while the SuperMini USB-C is plugged in (most SuperMini clones tie VBUS straight to the 5 V pin — meter-confirmed on ours — so USB would back-feed the battery). Flash/debug on USB with switch OFF.

**On the carrier PCB the rule is *conditionally* retired, not deleted.** The load-sharing path is a P-FET + Schottky, but the two OR terms are not symmetric: the charger's VBUS is a real diode into the gate, while the SuperMini's VBUS **cannot** be — it *is* the load node, so a diode there self-biases the gate. That term is a voltage threshold on the load node instead (pcb.md §4.1). Design review (2026-07-26) found that threshold cannot reliably distinguish a sagging USB port from a charged cell, so **the rule stands unless the block is populated and passes the amended bench test**; a JP1-bridged board keeps it permanently. See [hardware/pcb.md](hardware/pcb.md) §4.

**Budget (estimates, to be measured in week 1):** the **selected cell is 2000 mAh** (EEMB LP103454) — plan around **~13 h NETWORK / ~30 h LOCAL**, comfortably clearing the ~10 h runtime target. The 1000 mAh column is retained as a smaller-cell reference only.

| Mode | Current @3.7 V | 1000 mAh (ref) | **2000 mAh (selected)** |
|---|---|---|---|
| NETWORK (WiFi RX, sleep off) | ~120–135 mA | ~6.5 h | **~13 h** |
| LOCAL (WiFi off) | ~50–60 mA | ~15 h | **~29–30 h** |
| Low-battery policy (firmware) | warn < 3.45 V, WiFi off < 3.30 V, deep sleep < 3.05 V | protects LiPo above DW01's 2.4 V cutoff | |

Details/derivation: [hardware/power-budget.md](hardware/power-budget.md).

## 10. Firmware stack

- **PlatformIO + pioarduino platform (Arduino core 3.x / ESP-IDF 5.x)**, board `esp32-c3-devkitm-1`, USB CDC console.
- **Why not Zephyr / pure ESP-IDF:** Zephyr's ESP32-C3 port lacks mature I2S-TX and continuous-DMA-ADC drivers and its WiFi path (Espressif HAL blobs) is far less field-proven — unacceptable risk on a ~5-week deadline. Pure ESP-IDF would be equally solid but adds boilerplate; since all hot-path code here already calls IDF drivers directly, migrating later is cheap. PlatformIO (not Arduino IDE) for pinned versions and reproducible builds.
- Native IDF drivers used directly where the Arduino wrapper is inadequate: `i2s_std` (TX master, 48 kHz/16-bit/stereo, no MCLK) and `adc_continuous` (mic+vbat DMA). The Arduino `analogContinuous` wrapper *averages* conversions and is unusable for audio — do not use it.
- FreeRTOS layout (single core): high-prio audio task (pulls 240-frame blocks from active source, pushes to I2S DMA — the blocking I2S write paces the loop), network task (UDP RX → jitter buffer, status TX), Arduino `loop()` for UI/console at 100 Hz.
- Source: `src/esp32-slave/` — see [firmware/esp32-architecture.md](firmware/esp32-architecture.md).

## 11. Mechanical / size

Target carrier PCB: **70 × 50 mm**, 2-layer, through-hole **except Q1 (SOT-23) and D2 (SMA)**, both on enlarged hand-solder pads. Modules are socketed on female headers — **except the TP4056**, whose pads are not on a 2.54 grid and take **six** machined single pins: four on the output row, plus two 21.65 mm away at the USB-C-end corner pads, without which the jack sits on a cantilever (pcb.md §2/§5). Module footprints (✅ measured 2026-07-18, pin positions from photogrammetry 2026-07-26):

| Module | Approx. size | Mounting |
|---|---|---|
| ESP32-C3 SuperMini | 22.5 × 18 mm | 2× 1×8 header, 2.54 mm |
| GY-PCM5102A | **32.0 × 17.4 mm** (photogrammetry 2026-07-26; calipers said ~31.8 × 17) | 1×6 I2S header (SCK BCK DIN LCK GND VIN) on a short edge + **1×9 analog/config header** on the long edge (⊥); analog out on **LROUT / ROUT / AGND** (X = LROUT, Y = ROUT) |
| MAX4466 | ~20 × 13 mm | on a ~10 cm 3-pin pigtail (VCC GND OUT), exits the enclosure aimed at the PA so its gain trimpot stays screwdriver-reachable — not flat on the carrier |
| TP4056 (USB-C variant) | blue PCB **26.9 × 17.3 mm** measured, **25.2 mm** once the two depanelization nubs are filed off (USB-C jack overhangs **1.4 mm**) | 4 pads (B+/B−/OUT+/OUT−) at 0 / 3.526 / 10.960 / 14.066 mm, **plus the two `IN+`/`IN−` corner pads 21.65 mm away as a second mount row** — **six machined single pins, not a 2.54 header**; **USB-C** charge-port cutout on the board edge |

**Scope connection (resolved):** no BNC or TRS on the carrier. The board exposes **2× RCA flying-lead solder pad-pairs** (signal + ground): X = PCM5102A L, Y = PCM5102A R, each fed through its series R10/R11 position — **fitted as a 0 Ω link**, not 100 Ω ([hardware/pcb.md](hardware/pcb.md) §3.2 / §10 Q2, closed 2026-07-28). Signal chain: board RCA pad → reused ~50 cm RCA cable (RCA male, salvaged from the old sigma-delta units) → BNC→RCA adapter already fitted on each scope → scope CH. This frees ~25 mm of board edge and ~€2/board vs the old BNC plan.

**Enclosure:** 3D-printed case; the carrier keeps its 4× M3 mounting holes and its JST-PH battery socket. The 2000 mAh LiPo (34 × 56 × 11 mm) rides **off-board**, loose in the enclosure (velcro/pocket), since it is large relative to the 70 × 50 mm carrier.

**Panel controls:** power = **SS12D00 slide switch, 6 mm handle** (ordered 2026-07-27). Its 0.3 A
rating is a make/break figure at 50 VDC and is accepted at the ~4 V this switch interrupts —
the earlier "1 A-rated part required, for the ~0.35 A WiFi TX peak" call compared a peak
current against an arc-energy rating; see [hardware/pcb.md](hardware/pcb.md) §5. Filter-cutoff pot = **RV097NS** 9 mm PCB-mount (B10K, **5-pin mono *with switch*, right-angle**, body 27.3 × 9.5 × 11.3 mm); its **metal shaft is turned directly — no knob**, so the enclosure needs only a shaft hole (resolved 2026-07-18). The pot's **mounting surface sits on the board's south edge** and its M7×0.75 bushing + 15 mm shaft protrude through the enclosure wall — the panel nut is structural, since a bare shaft turned by hand puts torque into a part with no bracket lugs (geometry corrected 2026-07-27, [hardware/pcb.md](hardware/pcb.md) §5).

## 12. Verification checklist

*(Status 2026-07-26: the mechanical items are closed — see `hardware/measurements.md`. What is left is bench-electrical and moves to the assembled carrier; per `hardware/pcb.md` §8.2 none of it gates the fab order, which the board survives either way thanks to JP1.)*

- [ ] PCM5102A output truly passes DC on the actual purple modules (drive a slow ramp, watch scope) — datasheet says ground-centered/DC-capable. *Measured 2026-07-18:* the module carries a ~470 Ω "471" output filter but is ground-centered (no DC-blocking cap) — confirm the ramp passes DC. **R10/R11 is no longer part of this test:** it was settled as 0 Ω links on 2026-07-28 ([hardware/pcb.md](hardware/pcb.md) §10 Q2), and the ramp could not have decided it anyway — 100 Ω against the module's own 470 Ω shifts amplitude by 0.01 % and phase at 10 kHz by ≲0.07°, identically on both channels.
- [ ] PCM5102A PLL locks at 32× fs BCK (16-bit stereo, SCK grounded) — verify tone output.
- [ ] Filter ringing: sharp X/Y steps (square Lissajous) — compare FLT=L vs FLT=H visually on a scope.
- [ ] SuperMini onboard LDO type & dropout (probe 3V3 during WiFi TX burst at VBAT=3.5 V; check brownout).
- [ ] `adc_continuous` stable at 72 kHz total across 3 channels on C3/Arduino core 3.x.
- [ ] Measured currents per mode vs §9 table.
- [ ] DAC output amplitude/offset during battery rundown to 3.05 V (double-LDO undervoltage check, §5 caveat).
- [x] Measure all four module outlines/pin positions before PCB layout — **done 2026-07-18 (calipers) and superseded 2026-07-26 by photogrammetry** (`hw/pin_locs` → `measured.py`); the two numbers calipers guessed at were both wrong and both were wrong in the v1.0 board.
- [ ] WiFi robustness: 4 unicast streams from hostapd AP, RSSI at 10 m, packet-loss stats from slave status packets.

## 13. Repository layout

```
docs/            all documentation (this file = canon)
  research/      original v3 planning docs (historical, superseded where conflicting)
  hardware/      wiring, power, PCB
  firmware/      firmware architecture
  protocol.md    normative wire protocol
  PLAN.md        ~5-week execution plan
src/esp32-slave/     PlatformIO project (slave firmware)
src/unoq-controller/ UNO-Q controller app (deployed — see its README.md)
hw/carrier/          KiCad carrier PCB, generated by tools/*.py (see layout-notes.md)
```

Open questions used to live in a root `FURTHER_CLARIFICATION_NEEDED.md`; every PCB- and
order-blocking one closed by 2026-07-18, so the file was folded into the specs it fed —
hardware questions into [hardware/pcb.md](hardware/pcb.md) §10, and the HYBRID mic-mix
question into §7's mode table above.

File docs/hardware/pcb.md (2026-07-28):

# HYPEROSCI Carrier PCB — v1.1 Specification

> ## ✅ 2026-07-28 — routed and gate-clean on **seed 33**.
>
> The pre-fab DFM pass (silk stroke 0.12 → **0.15 mm**, SW1's plated slots re-cut
> to JLC's 2× aspect, silk legends kept off the module bodies) moved copper, which
> killed router seed 11. A 16-variant re-sweep found **exactly one clean result**
> — `halo-off`, **seed 33** — now `route.py`'s default. The board is
> **1343 segments, 48 GND vias, 0 unconnected, 0 DRC violations at every
> severity**, ground pour whole with zero repair. §6.4's width table and §4.4's
> drop figures have been **regenerated from the routed board** and are as-built.
>
> **✅ No gates remain — the gerbers are plotted, verified and committed** to
> `hw/carrier/fab/` (`tools/plot_fab.py` regenerates them and refuses to write
> the zip unless the board still passes). SW1, the last one, closed 2026-07-28
> from the SS12D00 datasheet without the part in hand and without a layout
> change: 2.5 mm pitch inside the slot's 2.00–2.90 window, 8.5 × 3.7 body on the
> pin centreline inside the 9.0 × 4.0 silk. See §7 and `layout-notes.md` →
> VERIFY item 2.
>
> ## 🚀 2026-07-28 — **ORDERED at JLCPCB**, three days inside the Aug 1 gate.
>
> Qty **10**, DHL Express **(DDP)**, Confirm Production File **on**, landed
> **$45.42**. Arrival **Aug 5–7** against the Aug 14 deadline — 7 days slack.
> Full order record, the four §8.3 deviations, the SW1 slot remark and the
> customs arithmetic: **[`hw/carrier/fab/README.md`](../../hw/carrier/fab/README.md)**.
>
> ⏳ **One thing is now gated on a human, and production is stopped until it
> happens:** the production file must be confirmed by email before JLC starts
> building. There is no auto-proceed and no expiry.

**Status:** layout v1.1 complete, routed and gate-clean (2026-07-28, seed 33) — see
[`hw/carrier/layout-notes.md`](../../hw/carrier/layout-notes.md). This document is the spec
of record for the fab order and the BOM. Pin map / constants mirror
[`docs/DESIGN.md`](../DESIGN.md) §4 and
[`src/esp32-slave/include/config.h`](../../src/esp32-slave/include/config.h) — those are law.
The board is **generated, not drawn**: `hw/carrier/tools/design.py` is the netlist source of
truth and the scripts build the schematic, footprints, board and routing from it (§9).
Anything genuinely undecided is listed in §10 (open questions) or carried as a
DNP (do-not-populate) footprint so the decision moves to assembly time, not layout time.

> **Review status (2026-07-26).** The load-sharing power path (§4) has been through an
> adversarial design review — [`pcb-review-findings.md`](pcb-review-findings.md). Two of its
> conclusions are load-bearing and are folded into the text below: **§4.3 state 4 does not
> work as originally written**, and the **JP1 fallback recipe was unsafe** because it left D2
> fitted. The §4 block is therefore an *experiment*, not the plan of record — see §4.5.

---

## 1. Concept

- **Board:** ~70 × 50 mm, 2-layer FR-4, 1.6 mm, 1 oz copper. ⚠️ **As actually ordered
  2026-07-28 the finish is HASL *with lead* and the mask is *black***, not the lead-free/green
  this line specified — both deliberate, see §8.3.
- **Assembly:** hand-soldered by Finn. All through-hole **except** Q1 (SOT-23) and D2 (SMA) in
  the power path — both are trivially hand-solderable on enlarged hand-solder pads. THT
  alternates for both are specified in the BOM (§5) with shared/dual footprints.
- **Modules are socketed** on female 2.54 mm header sockets, never soldered down:

| Module | Socket | Notes |
|---|---|---|
| ESP32-C3 SuperMini | 2× 1×8 female (J1A/J1B) | antenna end at the west edge. The antenna is **flush** with the module's own board edge (0 mm overhang, measured) — what protects it is the copper keep-out inboard of that edge, §6.1 rule 3 |
| GY-PCM5102A (purple) | 1×6 female (J2) + 1×9 female (J3) | I2S end (short edge) + 9-pin analog/config end on the long edge (⊥ to J2). Module measures **32.0 × 17.4 mm** (photogrammetry) — see §7/measurements.md |
| MAX4466 mic | 1×3 header (J4) | off-board on a ~10 cm pigtail (`VCC/GND/OUT`); aimed at the PA |
| TP4056 USB-C (blue, **26.9 × 17.3 mm** *with* the two west-edge depanelization nubs; **25.2 mm body** once they are filed off — §5) | **6× machined single-pin sockets**: the output row (J5 = `OUT−`/`B−` @ 3.526 mm, J6 = `B+`/`OUT+` @ 3.106 mm) **plus a mount row at the USB-C end** 21.65 mm away (J9 = `IN+`, J10 = `IN−`/NC) — four in one line left the jack on a 21.65 mm cantilever, §5 | USB-C end at board edge; the jack overhangs the module's own east edge by **1.4 mm**, which lands it ~0.5 mm proud of the carrier edge (§6.1 rule 4 — an enclosure constraint). **Not a stock 1×2 socket** — the pads are not on a 2.54 grid, see §2 |

- Passive parts may be placed **under the socketed modules**. The gated figure is
  **8.3 mm**: that is the SuperMini's own bottom-side component height (measured), and it is
  what a 2.54 mm socket pair must clear, so `audit_board.py` refuses any part taller than
  8.3 mm inside a module's measured body outline. As built, nothing is. This is how
  everything fits in 70 × 50 mm.
- **Battery (off-board):** EEMB **LP103454** LiPo 3.7 V **2000 mAh**, 34 × 56 × 11 mm, ~40 g,
  with a pre-fitted JST-PH lead (no crimping). It does **not** sit on the PCB — it is mounted
  loose (velcro/pocket) in the 3D-printed enclosure, since 56 × 34 mm is large next to the
  70 × 50 mm carrier. The carrier only carries the JST-PH socket (J8). The ~10 h runtime target
  is met comfortably (≈13 h NETWORK, ≈30 h LOCAL).
  **Sourcing changed 2026-07-27: cells come from Amazon**, not the EEMB part, to keep the LiPo
  off the slow-freight critical path. Two things the substitution puts on you, because a
  generic cell guarantees neither: **(a)** it must terminate in a **JST-PH 2.00 mm** plug — PH,
  XH and mini-Tamiya all ship on Amazon LiPos; **(b) meter the polarity before the first
  plug-in** (layout-notes VERIFY 5). Cell-lead polarity is not standardised, J8's silk assumes
  the EEMB convention, and on this board `B−` is deliberately **not** GND (§3.1), so a reversed
  cell drives the pack backwards through the FS8205 rather than simply failing to run. Keep the
  capacity near 2000 mAh — every runtime and threshold figure in
  [power-budget.md](power-budget.md) is written against it.
- **Enclosure:** 3D-printed case; the carrier keeps its 4× M3 mounting holes (§6).
- 4 identical boards will be built (a 5th possible later); order **5 PCBs** (§8) — the fab
  minimum quantity is 5 anyway, which yields one spare bare board.

---

## 2. Connectors & sockets — pin-by-pin

Reference designators used throughout this doc and to be used in KiCad:

| Ref | Part | Function |
|---|---|---|
| J1A, J1B | 1×8 female header, 2.54 mm | SuperMini socket rows. **KiCad refs are `JA1`/`JB1`** (a KiCad reference must end in a digit); the silk keeps the doc names. Row spacing ✅ **measured 15.240 mm** (photogrammetry, worst pin 0.100 mm). `JB1` = the GPIO5-side row and it is the **north** one — see §6.1 rule 3. |
| J2 | 1×6 female header | PCM5102A I2S end: `SCK BCK DIN LCK GND VIN` ✅ order confirmed against the module silk 2026-07-18 |
| J3 | 1×9 female header | PCM5102A analog/config end (long edge). Silk (jack→digital): `LROUT AGND ROUT AGND A3V3 FMT XSMT DEMP FLT`. Carrier nets only the analog pins: **LROUT (=X), ROUT (=Y), AGND**; FLT/DEMP/XSMT/FMT are set by the module's own H1L–H4L back-side bridges (DESIGN §5), so they are **NC** on the carrier — the rest of the 1×9 is mechanical support. |
| J4 | 1×3 header (pigtail landing) | MAX4466 on a ~10 cm 3-wire pigtail: `VCC GND OUT` ✅ confirmed on the back silk 2026-07-18. Mic exits the enclosure, aimed at the PA. |
| J5 | 1×2 pad pair, **3.526 mm** pitch | TP4056 north pair: `OUT− B−`. ⚠️ **Not a stock socket and not a 2.54 grid** — the module's four pads measure 0 / 3.526 / 10.960 / 14.066 mm down its short edge (photogrammetry, 2026-07-26), so the grouping is `(OUT−,B−)` + `(B+,OUT+)`, *not* the battery-end/output-end split this table used to claim. Generated footprint `HYPEROSCI:TP4056_Pads_OUTminus_Bminus`. |
| J6 | 1×2 pad pair, **3.106 mm** pitch | TP4056 south pair: `B+ OUT+`, 10.960 mm south of J5.1. Generated footprint `HYPEROSCI:TP4056_Pads_Bplus_OUTplus`. Fit four machined single sockets, or solder wires and give up removability. |
| J6b | 1 machined single-pin socket | TP4056 `IN+` (VBUS_CHG sense — see §4; 1.0 mm drill). **KiCad ref is `J9`.** No longer a wire pad: it is half of the **USB-C-end mount row** (§5), 21.65 mm east of the J5/J6 column, on the module's `+`-marked corner pad. |
| — | 1 machined single-pin socket | **`J10`** — the other USB-C-end corner pad (`IN−`). **On no net, deliberately**: its job is mechanical, and `IN− ≡ OUT−` is asserted in this table but has never been measured on this module. Bonding it to GND on a wrong assumption shorts across the DW01/FS8205. See [measurements.md §The second mount row](measurements.md). |
| J7 | 1×2 male header | Debug: `GPIO21 (UART0 TX)`, `GND` |
| J8 | JST-PH 2-pin, side entry (S2B-PH-K-S) | LiPo battery in (EEMB LP103454 2000 mAh, mounted off-board — cell not on the PCB outline). **Polarity silk mandatory.** |
| X, Y | 2× RCA flying-lead solder pad-pair (signal + AGND) | Scope X (=DAC L), Scope Y (=DAC R). Finn solders the reused ~50 cm RCA cables here — no connector part on the board. Silk `X` / `Y`. |
| SW1 | SPDT slide switch — **SS12D00, 6 mm handle** (ordered 2026-07-27) | Power switch (in VSW→VLOAD path, §4). Its 0.3 A rating is a *make/break* figure at 50 VDC; this switch breaks 4 V, so the ≈0.35 A WiFi peak is accepted — see the §5 row |
| SW2 | 6×6 mm THT tactile | MODE button → GPIO7 |
| RV1 | **RV097NS** 9 mm 10 kΩ linear pot (B10K), **5-pin mono *with switch*, right-angle**, body 27.3 × 9.5 × 11.3 mm. **Metal shaft turned directly — no knob.** Pads 4/5 are the SPST, not bracket lugs (the part has none) — both parked on GND, see §5. The **mounting surface sits on the board's south edge**; the M7×0.75 bushing and 15 mm shaft hang off it. | Filter-cutoff → GPIO3 |

**SuperMini socket pin functions** (net names; physical position per module silk —
✅ confirmed 2026-07-18 against the owned TENSTAR ROBOT modules, `5V G 3.3 4 3 2 1 0` /
`5 6 7 8 9 10 20 21`. Re-check if a future batch is a different clone revision):

| J1A (5V-side row, **south**) | Net | J1B (GPIO5-side row, **north**) | Net |
|---|---|---|---|
| 5V | VLOAD | GPIO5 | I2S_LRCK |
| GND | GND | GPIO6 | I2S_DOUT |
| 3V3 | 3V3 | GPIO7 | BTN_MODE |
| GPIO4 | I2S_BCK | GPIO8 | *NC (onboard LED)* |
| GPIO3 | POT_WIPER | GPIO9 | *NC (onboard BOOT)* |
| GPIO2 | GPIO2_PU (10 k to 3V3 only) | GPIO10 | LED_NET_A |
| GPIO1 | VBAT_SENSE | GPIO20 | LED_MODE_A |
| GPIO0 | MIC_OUT | GPIO21 | DBG_TX |

---

## 3. Complete net list (schematic description)

Every net on the board. Pin numbers match `config.h` exactly.

### 3.1 Power nets

| Net | Connects |
|---|---|
| **BAT+** | J8.1 (JST +) → **J6.1** `B+`. Also top of battery divider R1. On this USB-C TP4056 module, `B+` and `OUT+` are the same copper (protection is low-side) — ✅ measured 0 Ω 2026-07-18. |
| **BAT−** | J8.2 (JST −) → **J5.2** `B−` **only**. ⚠️ **B− must NOT join GND** — the DW01/FS8205 protection switches the low side between B− and OUT−. Shorting them defeats protection (✅ measured open 2026-07-18). Silk warning next to J5. |
| **GND** | **J5.1** `OUT−` = system ground: SuperMini GND, J2 GND, J2 SCK (see below), C1−, C2, C3, C5, R2, R6, R8, U1 anode, SW2 pin B, RV1 CCW end **and both ends of RV1's integrated SPST (pads 4/5 — see §5)**, LED cathodes, mounting-hole pads (fenced, see §6). ⚠️ **`J10` (TP4056 `IN−`) is deliberately NOT on this list** — this row used to end "TP4056 `IN−` (same node module-internally)", which contradicts §2, `design.py` (`J10 = {"1": None}`) and the board itself. `IN− ≡ OUT−` has never been measured on this module, and wiring it to GND on that assumption shorts across the DW01/FS8205. Because the protection FET is in the **cell-negative** leg, every carrier load — including the R1/R2 divider — returns through it and is genuinely cut at the DW01's 2.4 V trip. |
| **VBAT_OUT** | J6.2 `OUT+` → Q1 **drain** + **JP1 pin 1** (the §4.4 escape hatch). |
| **VSW** | Q1 **source** + D2 cathode + sense divider top (R7) + **R12** + **Q2 emitter** + **JP1 pin 2** + SW1 pin 1 + testpoint TP2. Note this node is **upstream of SW1**: it is live off the cell through Q1 whenever a battery is connected, whatever position the switch is in (§4.3 state 6). |
| **VLOAD** | SW1 pin 2 → SuperMini `5V` pin, C1 (220 µF) +, C2 (100 nF), **D3 anode (DNP)**. |
| **3V3** | SuperMini `3V3` pin → J2 `VIN` (PCM5102A), J4 `VCC` (mic, with C4 100 nF at the socket), R3 (GPIO2 pull-up), RV1 CW end, C5 (100 nF near J2). Per DESIGN §5 the DAC's VIN runs from 3V3 (double-LDO cascade is fine). |
| **VBUS_CHG** | J6b (TP4056 `IN+`) → D1 anode, D2 anode, testpoint TP1. |
| **GATE** | Q1 gate + R6 (100 k → GND) + D1 cathode + D3 cathode (DNP) + Q2 collector + TP3. |
| **AGND** | Analog ground island: J3 `AGND` (the two AGND pins of the 1×9), the X and Y RCA ground pads, C4 GND side, J4 `GND` (mic). Joined to GND at **one neck** near the J2 GND pin (§6.3). Electrically the same net as GND — draw as GND in the schematic, enforce the single-neck join in layout. |

### 3.2 Signal nets

| Net | GPIO (config.h) | Connects |
|---|---|---|
| **MIC_OUT** | GPIO0 (`PIN_MIC_ADC`) | J4 `OUT` → GPIO0 directly (mic self-biased ~VCC/2, same as old unit) |
| **VBAT_SENSE** | GPIO1 (`PIN_VBAT_ADC`) | R1 (100 k from BAT+) / R2 (100 k to GND) midpoint; C3 100 nF across R2 |
| **GPIO2_PU** | GPIO2 (strapping) | R3 10 k → 3V3. **Nothing else.** Must be high at reset. |
| **POT_WIPER** | GPIO3 (`PIN_POT_ADC`) | RV1 wiper. RV1 pin 1 (CCW) → GND, pin 3 (CW) → 3V3, so clockwise = higher cutoff |
| **I2S_BCK** | GPIO4 (`PIN_I2S_BCK`) | → J2 `BCK` |
| **I2S_LRCK** | GPIO5 (`PIN_I2S_LRCK`) | → J2 `LCK` |
| **I2S_DOUT** | GPIO6 (`PIN_I2S_DOUT`) | → J2 `DIN` |
| **BTN_MODE** | GPIO7 (`PIN_BTN_MODE`) | SW2 → GND. No external pull-up or cap; internal pull-up + 30 ms firmware debounce per config.h |
| **LED_NET_A** | GPIO10 (`PIN_LED_NET`) | GPIO10 → R4 2.2 k → D4 green 3 mm anode; cathode → GND (active high) |
| **LED_MODE_A** | GPIO20 (`PIN_LED_MODE`) | GPIO20 → R5 2.2 k → D5 amber 3 mm anode; cathode → GND (active high) |
| **DBG_TX** | GPIO21 | → J7.1 (J7.2 = GND). Log-only header, no RX (GPIO20 is repurposed as LED) |
| **DAC_L / SCOPE_X** | — | J3 `LROUT` → R10 **0 Ω link** → X RCA signal pad |
| **DAC_R / SCOPE_Y** | — | J3 `ROUT` → R11 **0 Ω link** → Y RCA signal pad |
| **J2 `SCK`** | — | **Tie to GND on the carrier.** This implements DESIGN §5's "SCK tied to GND" (DAC generates its clock via PLL from BCK) without a solder mod on each module. |

The R10/R11 footprints exist to protect the DAC from shorted/hot-plugged scope cables and to
isolate it from cable capacitance — a job a 100 Ω series part would do, at an attenuation into
a 1 MΩ scope input of 0.01 %, i.e. invisible. **They are fitted as 0 Ω links**, for the reason
below.
**Measured 2026-07-18:** the purple module already carries an output reconstruction filter
(~470 Ω "471" series parts + caps) between the DAC and the `LROUT`/`ROUT` pins, and the
output is **ground-centered** (no DC-blocking cap in the path). With ~470 Ω already in
series, keep the R10/R11 footprints but **fit 0 Ω wire links** — §10 Q2, closed 2026-07-28.
The Phase-4 bench ramp cannot decide this: 100 Ω against the module's 470 Ω moves the phase
at 10 kHz by ≲0.07° and the amplitude by 0.01 %, identically on both channels, so there is
nothing to see. Populate 100 Ω only if a future cable turns out to need the isolation.

GPIO8 and GPIO9 socket positions are **not connected** on the carrier (onboard LED / BOOT
button, both strapping pins — DESIGN §4).

Testpoints (plated pads, 1.5 mm): TP1 = VBUS_CHG, TP2 = VSW, TP3 = GATE, TP4 = 3V3,
TP5 = VBAT_SENSE.

---

## 4. Load-sharing power path

**Purpose (DESIGN §9):** kill the bring-up rule "never have the switch ON while any USB is
plugged". Requirements: (a) battery → load with near-zero drop; (b) when *either* USB is
present, the battery is disconnected from the load so TP4056 charges it cleanly (proper
CC/CV + termination) and USB can never back-feed the cell; (c) load runs from USB meanwhile.

### 4.1 The one hard constraint discovered during design

DESIGN §9 originally sketched "P-FET + Schottky, both VBUS sources diode-ORed into the gate"
(that file now carries the corrected description). The
TP4056's VBUS is directly accessible (`IN+` pad). **The SuperMini's VBUS is not**: on these
clone modules USB VBUS is tied straight to the `5V` pin (**meter-confirmed 2026-07-18**,
measurements.md — VBUS↔5V continuous) — i.e.
the SuperMini's "VBUS" *is the load node*. A plain OR-diode from the load node to the gate
self-biases the gate to (VLOAD − Vf) in battery mode, holding Vgs at ≈ −0.2…−0.5 V forever,
so the FET never fully turns on and you eat the body-diode drop (~0.7 V) — which browns out
the SuperMini below ~3.6 V battery. **So the "SuperMini VBUS" OR term must be implemented as
a voltage threshold on the load node instead of a diode.** Logic: `VLOAD > 4.5 V` can only
mean a USB source is present (battery tops out at 4.2 V; USB min is 4.75 V). The circuit
below keeps the DESIGN §9 architecture (both VBUS sources drive the gate) with the second
term implemented as a TL431 comparator. A DNP diode footprint (D3) is kept for breadboard
experiments.

> **⚠️ That logic does not survive review, and §4.3 state 4 is where it fails.** Two things
> are wrong with "`VLOAD > 4.5 V` can only mean USB":
>
> 1. **The band is far narrower than it looks.** USB 2.0 permits **4.40 V at the device end**,
>    and a laptop port through a thin cable routinely reads 4.4–4.6 V at the SuperMini
>    connector. The usable window is therefore roughly 4.24 V (a full cell at the charger's
>    CV max) to ~4.5 V — about **200–300 mV**, most of which is eaten by the reference
>    tolerance, the divider tolerance and the REF bias current (§4.2).
> 2. **Worse, the threshold is often unreachable.** You enter state 4 *from battery mode*,
>    where Q1 is already on. The cell then clamps VSW to roughly `V_OCV + I·R_path` with
>    `R_path ≈ 0.2–0.3 Ω` (Q1 + FS8205 + JST/leads + cell IR). Lifting that node to the
>    4.46 V low corner from a 3.7–4.0 V cell needs **≈1.5–3.8 A** through the cell branch —
>    beyond a 0.5 A legacy port at any state of charge, and beyond a 1.5 A BC.1.2
>    port below roughly a 4.0 V cell. (A 3 A Type-C port on a nearly-full cell *can* reach
>    it — the failure is worst exactly when the cell is emptiest.) So the "Q1 on" state is
>    largely self-reinforcing: closer to a latch than a trip point, and a stiff 5 V bench
>    supply does not reveal it.
>
> The consequence is that **no choice of divider values fixes state 4** — the defect is in
> sensing an absolute threshold on the load node, not in the numbers. Sensing the *drop
> across Q1* instead (an ideal-diode controller such as the LTC4412) has no threshold to
> mis-set and cannot fail this way; that is the v1.2 answer. See §4.5 for what to actually
> do for the show.

### 4.2 Circuit

The block is drawn, wire by wire, in the generated schematic — see the **"LOAD-SHARING
POWER PATH"** block of
[`hw/carrier/carrier-schematic.svg`](../../hw/carrier/carrier-schematic.svg)
(printable A3: [`carrier-schematic.pdf`](../../hw/carrier/carrier-schematic.pdf)). It
replaced the ASCII art that used to live here after two successive revisions of that art
drew the Q2 corner wrong; the schematic is generated from `design.py` and netlist-gated,
so it cannot make that class of error. The Q2 corner in words, matching `design.py`
exactly:

| Node | Connects to |
|---|---|
| Q2 emitter | VSW |
| Q2 base | R9 (to the TL431 cathode) **and** R12 |
| Q2 collector | GATE |
| R12 | base ↔ emitter, i.e. **across** the base–emitter junction, holding Q2 off until the TL431 sinks current through R9 |

So R12 is a base–emitter hold-off resistor in *parallel* with the junction, **not** in series
with anything. An earlier ASCII revision of this section drew it in series between the R9
node and the emitter, which is a different and nonsensical circuit; a later attempt to fix
it in ASCII instead implied base, emitter and collector were shorted. The table above,
`design.py` and the generated schematic agree; the ASCII attempts are gone.

Netlist form:

| Part | Value | Connections |
|---|---|---|
| Q1 | DMG3415U (P-ch, −20 V, −4 A, Vgs(th) −0.3…−1.0 V, Rds(on) 42 mΩ @ −4.5 V) | D = VBAT_OUT, S = VSW, G = GATE |
| R6 | 100 k | GATE → GND (default: FET on) |
| D1 | **BAT85** Schottky (DO-35) | VBUS_CHG → GATE (charger-USB OR term). D1 carries only R6's ~45 µA, so its Vf (≤ 0.24 V) sits *below* D2's — see §4.3 state 2/3 for why that matters |
| D2 | SS34 (or THT 1N5817/1N5822, dual footprint) | VBUS_CHG → VSW (feeds load while charging). **Not fitted when JP1 is bridged** (§4.4) |
| R7/R8 | **8.2 k / 10 k, 1 %** | VSW divider → U1 REF. Trip = `Vref·(1+R7/R8) + I_ref·R7` = 2.495 × 1.82 + 2 µA × 8.2 k ≈ **4.56 V typ**, window **4.46–4.66 V** at 25 °C with a TL431A. See the divider table below |
| U1 | **TL431A** (±1 %, TO-92) | REF = divider, A = GND, K = via R9 to Q2 base. ⚠️ **check the TO-92 lead order of the part you buy** — see §5 |
| R9 | **1 k** | Q2 base → U1 cathode (~2 mA cathode current when tripped, clear of onsemi's 1 mA `I_KA(min)` maximum — TI specs its A grade at 0.6–0.7 mA, so the old 2.2 k's ~0.93 mA was marginal rather than universally out of spec. The consequence of going under is a soft, ill-defined trip, not a dead circuit.) |
| R12 | 100 k | Q2 base–emitter (holds Q2 off) |
| Q2 | BC557 (PNP, TO-92) | E = VSW, C = GATE. When on, pulls GATE to VSW ⇒ Vgs ≈ 0 ⇒ Q1 off |
| D3 | BAT85 — **DNP** | VLOAD → GATE. Experimental "naive OR" term; see §4.1 why it's not fitted |
| SW1 | slide switch | VSW → VLOAD. Downstream of FET/Schottky on purpose (see states) |
| C1/C2 | 220 µF electro + 100 nF | on VLOAD (bulk for WiFi TX bursts, per DESIGN §3) |

**The divider is a populate-time choice, not a fab-time one.** R7/R8/U1 are through-hole
parts fitted at assembly, so the board does not commit you to any row of this table. What the
original 82 k/100 k gets wrong is that `V_trip = Vref·(1+R7/R8)` **omits the TL431's REF input
bias current** flowing in R7, which at 82 k adds 164 mV typ / 328 mV max. Every trip number
published before 2026-07-26 was low by that much.

| Option | U1 | R7 / R8 | Trip typ | 25 °C window | Standby (VSW divider) | Shelf life¹ |
|---|---|---|---|---|---|---|
| as built v1.0 | TL431 (±2.2 %) | 82 k / 100 k | 4.70 V | 4.40–5.01 V | 23 µA | ~4.2 yr |
| **fitted default** | **TL431A (±1 %)** | **8.2 k / 10 k** | **4.56 V** | **4.46–4.66 V** | **231 µA** | **~10 months** |
| middle | TL431A | 18 k / 22 k | 4.57 V | 4.45–4.70 V | 105 µA | ~1.7 yr |
| best electrically | TLV431A (Vref 1.24 V) | 100 k / 38.3 k | 4.49 V | 4.37–4.64 V | 30 µA | ~3.7 yr |

¹ Drain-only, 2000 mAh, everything else in §4.3 state 6 included. The cell's own
self-discharge (order 1.5–3 %/month, ≈40–80 µA equivalent) is comparable to or larger than the
board in every row except the 8.2 k/10 k one, so treat these as "the board stops being the
limiting factor below ~50 µA", not as literal shelf life.

The **TLV431A** row is the electrically correct answer — its REF bias current is ≤0.5 µA
instead of 4 µA, so it buys the accuracy at *no* standby cost, and its TO-92 (LP) pinout is
pin-for-pin identical to the TL431's. It is not the default only because TI's A-grade TO-92
parts are NRND/obsolete (onsemi `TLV431ALPRAG` is the live source) and this is a 6-day order
window. If you can source it, fit it — R7/R8 change with it, and note Vref is 1.24 V, so the
divider ratio is completely different.

None of these fix §4.3 state 4 (see the box in §4.1). They fix the *accuracy* of a threshold
that is looking at the wrong node.

### 4.3 Operation state-by-state

| # | State | What happens |
|---|---|---|
| 1 | **Battery only, SW1 ON** | VBUS_CHG = 0 ⇒ D1 inert. VSW bootstraps through Q1's body diode, TL431 sees < 4.2 V ⇒ off ⇒ GATE = 0 V via R6 ⇒ Vgs = −VBAT (−3.0…−4.2 V) ⇒ Q1 fully on. Drop at 125 mA ≈ **5 mV**. Load runs from battery. |
| 2 | **Charging (TP4056 USB in), SW1 ON** | **D1 is what holds Q1 off here** — VSW ≈ 4.68 V (5.0 − D2's drop at ~150 mA) sits right on the trip, so the TL431 may or may not fire; do not rely on it. With D1 a **Schottky**, Vgs = Vf(D2) − Vf(D1) ≈ 0.32 − 0.24 = **+0.08 V** ⇒ hard off. Battery then sees only the charger: clean CC/CV, correct termination. Load runs from VBUS_CHG through D2 → SuperMini LDO; unit fully operational while charging. Use a **5 V / 2 A** wall charger (mandatory): charge current (1 A default Rprog) + load (~150 mA) share one port; 2000 mAh at 1 A ≈ 0.5C ⇒ full charge ~2.5–3 h. Reprogramming Rprog to 2.4 k (500 mA) is **optional** (fiddly 0402/0603 rework) — the 2 A charger makes the 1 A default safe. |
| 3 | **Charging, SW1 OFF** | Same as #2 but load disconnected — unit off, battery charges clean. This is the **worst case for the D1 term**: with the load gone, D2 carries only the sense divider (~230 µA at 8.2 k/10 k, plus ~2 mA once the TL431 fires), so its Vf falls to ~0.15–0.25 V. With a silicon D1 that leaves Vgs ≈ −0.15…−0.25 V — *below* the DMG3415U's −0.3 V minimum threshold, so Q1 is nominally off, but only by 50–150 mV of a parameter that drifts ~2 mV/°C in the TP4056's 1–1.4 W heat plume. That is sub-threshold, not hard-off, and it leaks. The Schottky D1 is what turns this into ≈ 0 V with margin. TL431 burns ~2 mA from the charger (irrelevant). |
| 4 | **Flashing (SuperMini USB in), SW1 ON, battery in** | ⚠️ **This state does not work as designed — see the box in §4.1.** The intent was: VBUS drives VLOAD → SW1 → VSW ⇒ TL431 trips ⇒ Q1 off. In reality you arrive here from battery mode with Q1 *already on*, and the cell clamps VSW; reaching the trip would need 2–4 A. A laptop port loaded to 4.4–4.6 V leaves **Vgs ≈ −4.5 V, Q1 fully enhanced at 42 mΩ**, and the port back-feeds the cell at whatever its limiter allows (0.5 A legacy / 1.5 A BC1.2 / up to 3 A Type-C) with **no CC/CV and no termination**. D1 cannot help — its anode (VBUS_CHG) is at 0 V with the charger unplugged. The only backstop is the DW01's ~4.3 V overcharge cut, tens of minutes away at mid SoC. There is no visible symptom. **Until §4.4 says otherwise, keep the manual rule: switch OFF before plugging the SuperMini's USB.** |
| 5 | **Flashing, SW1 OFF** | SuperMini + 3V3 loads (DAC, mic) powered from its USB; VLOAD isolated from VSW by the open switch; battery idles behind Q1. **This one genuinely is safe** — it is the state the manual rule tells you to flash in. |
| 6 | **SW1 OFF, no USB (storage)** | **SW1 does not disconnect the sense divider.** SW1 cuts VLOAD only; R7/R8 hang on VSW, which the cell reaches through Q1 (on, and through its body diode even if it were off). What the switch *does* remove is C1/C2 and the whole 3V3 rail including RV1's 330 µA — which is why it is worth having. Standby at 4.2 V = R7+R8 (**231 µA** at 8.2 k/10 k, was 23 µA) + R1/R2 divider (21 µA) + DW01 (~3 µA) + TP4056 standby (~2.5 µA) + D2 reverse leakage (a *typical*, not a datasheet limit: ~5 µA at 25 °C, climbing steeply to tens of µA by 50–60 °C; the SS34's specified maximum is far higher) ≈ **262 µA at 4.2 V ⇒ roughly 10.5 months** on the 2000 mAh cell (the §4.2 table's standby column uses the same 4.2 V basis throughout). **Note this is the standby of a fully-populated block** — on the §4.5 plan-A board, with R7/R8 omitted, it drops back to ~30 µA. The old "~5 years" figure was wrong twice over: it omitted the REF bias current *and* it is unreachable at **any** divider value, because the cell's own self-discharge alone is 40–80 µA equivalent. Recharge on a calendar; do not rely on the DW01 cutoff, which is a fire fuse, not a storage strategy. |
| 7 | **Race: plugging charger while SW1 OFF** | For the µs–ms before TL431 trips, Q1 is still on and D2 could push a current blip into the cell. D1 yanks the gate high in nanoseconds, closing the race. This is why D1 stays fitted — and per states 2/3 it is the *primary* isolation while charging, not merely a race-closer. |

Margins (with DMG3415U Vgs(th) min −0.3 V per [Diodes datasheet](https://www.diodes.com/datasheet/download/DMG3415U.pdf)).
**Both margin claims printed here before 2026-07-26 were void** — they used the
bias-free trip of 4.54 V. Corrected, for the fitted 8.2 k/10 k + TL431A:

- **Battery side (the one that must hold):** trip window low corner **4.46 V at 25 °C** vs a
  full cell at the charger's CV max **4.242 V** ⇒ **≈0.22 V**. Over temperature the low
  corner falls to ~4.41 V ⇒ ~0.17 V — still safe, but note that means the fitted values only
  satisfy the "never below ~4.45 V" rule in §4.4 item 5 *at 25 °C*. Safe: no false trip in battery mode, and
  WiFi-burst ripple on VSW is downward, i.e. away from the threshold. On the old 82 k/100 k
  the low corner was 4.40 V — still safe, so this was never the failing end.
- **Load side (the one that does not hold):** the window's high corner is 4.66 V at 25 °C
  (4.73 V over temperature) against a *connector* voltage that is legally as low as 4.40 V.
  There is **no guaranteed margin**, and per §4.1 the threshold is usually unreachable in
  state 4 anyway. Do not quote a load-side margin figure.
- **States 2/3 rest on D1, not on the comparator** — VSW sits within tens of mV of the trip
  while charging. That is why D1 is a Schottky: it makes Vgs ≈ 0…+0.1 V in both charging
  states instead of −0.10…−0.22 V against a −0.3 V minimum threshold. The two mechanisms were
  described as "deliberately overlapping"; in practice, in states 2 and 3, there is only one.

**Hot-enclosure note (found 2026-07-26, not yet bench-checked).** D2's reverse leakage in
storage returns through `D2 → VBUS_CHG → D1 → GATE → R6`, so it develops `I·R6` on the gate:
harmless 0.5 V at 5 µA, but at the tens of µA a 50–60 °C enclosure produces, GATE climbs
toward 2–3 V and Vgs enters the −0.3…−1.0 V threshold band. Q1 then un-enhances and the load
falls onto its body diode (~0.4–0.6 V at 125 mA), eating LDO headroom. It is self-limiting
and recovers when it cools, but it means the gate node's leakage headroom is only ~30 µA
(30 µA × R6 = 3 V on GATE ⇒ Vgs ≈ −1 V, the worst-case threshold limit). If
this shows up on the bench, the fixes are a lower-leakage D2 (SS14 in the same SMA footprint)
and/or a smaller R6 — both value-only.

### 4.4 ⚠️ VERIFY — bench-test the block on the assembled carrier

**This moved.** It was written as a breadboard evening gating the PCB order. It cannot run
there: the current bench rig has no battery and no TP4056 in circuit, and Q1 is SOT-23 —
unbreadboardable without an adapter. It is also not an order gate, because the board carries
both topologies (JP1). So: **order on schedule, run this on an assembled carrier** in the
Aug 11–16 window, where TP1 (VBUS_CHG) / TP2 (VSW) / TP3 (GATE) exist for exactly this and
every module lifts out of its socket. Until it passes unambiguously, ship on §4.5's plan A.

1. State 1: measure the drop **across Q1 alone** (TP2 vs the cell +) at 150 mA — expect
   < 20 mV. Do *not* measure cell→5V-pin and apply that number: the copper from Q1's source to
   the 5V pin adds a measured **≈50 mΩ** (30.7 mΩ VSW + 19.5 mΩ VLOAD, §6.4), i.e. **~7.5 mV
   at 150 mA** on top. If you see ~0.7 V across Q1, the FET is not turning on — check the gate.
   *(This adder read "152 mΩ / ~23 mV" until 2026-07-28. That figure was two re-routes stale
   and would have had you hunting a 23 mV drop that is not there — which, on a 20 mV
   acceptance threshold, is larger than the thing being measured. Re-run
   `tools/measure_copper.py` and update this number after **every** re-route.)*
2. State 2: scope the cell current while charging with load running — must show clean CC/CV,
   LED on TP4056 must reach "charged" (termination works only if load is truly disconnected).
3. **State 4 — the one that matters, and the one the old procedure would have passed.**
   Cell current with the SuperMini USB plugged and SW1 ON. Three amendments, all load-bearing:
   - **Source:** not a stiff 5.0 V bench supply. Feed it from a supply deliberately sagged to
     **4.4 / 4.5 / 4.6 V** (bench supply + ~0.5 Ω series), *and* at 4.75 and 5.0 V. The
     failure is specific to a real laptop port through a thin cable.
   - **Instrument:** a **milliohm-class shunt**, not a DMM in current mode. A DMM's 0.1–0.25 Ω
     burden roughly doubles the path resistance, which lets the circuit trip and read µA —
     the meter makes it pass. Remove the meter and the fault returns.
   - **Criterion:** **≤ 1 mA**, not "≤ µA" — a sub-threshold trickle through Q1 is normal and
     the old criterion would send you chasing a phantom. Repeat across cell SoC 3.6–4.0 V.
4. State 7: plug/unplug charger 20× with SW1 in both positions; watch cell current for blips.
5. Sweep a bench supply 4.2→5.0 V on VLOAD and log the trip point. **Expect ≈4.56 V** with the
   fitted 8.2 k/10 k + TL431A (≈4.7 V if you built the old 82 k/100 k) — a correct measurement
   at 4.7 V is not a build error. *Do not retune R7 downward:* the old advice here (75 k →
   "4.37 V", 77 k → "4.42 V") was doubly wrong — those values actually trip at ~4.52 / 4.57 V,
   and a low corner near 4.24 V collides with a full cell, giving battery-mode relaxation
   oscillation. Never set the low corner below ~4.45 V.
6. Optionally fit D3 (BAT85) and confirm the §4.1 failure yourself (battery-mode drop jumps
   to ~0.7 V) — then remove it.
7. Record the trip point and the state-4 current in `measurements.md`. There is currently no
   power-path row in that file at all, which is why every number in §4.3 is paper.

**Escape hatch (already on the board):** bridge the 2.54 mm solder-jumper **JP1
(VBAT_OUT → VSW)** and leave **Q1, U1, Q2, D1 and D2** unfitted — *and take R7/R8 off too*.
Those five are the safety-critical ones (they carry current or can inject into the cell), but
R7/R8 sit across VSW, which JP1 ties straight to the battery: leaving them fitted burns
**231 µA** off the cell for a divider whose comparator is not even populated, which is the
entire shelf-life budget §4.2 argues about. R6/R9/R12 do nothing with Q1/Q2/U1 absent — fit
them or not. You are then back to the
proven plain-switch topology plus the old "switch OFF while USB plugged" rule.

> **⚠️ D2 must come off — this is not optional hygiene.** With JP1 bridged and D2 still
> fitted, plugging the charger gives `VBUS_CHG → D2 → VSW → JP1 → VBAT_OUT = OUT+ = B+`, i.e.
> the raw USB input lands on the cell at ~4.6 V with the TP4056's CC/CV loop bypassed
> entirely — an initial demand of several amps, limited only by the adapter. The TP4056 sees
> an IR-inflated B+ and lights "charged" while D2 keeps feeding. The only stop is the DW01
> hiccupping between 4.10 and 4.30 V for as long as the charger is plugged in. And because
> the injection point is **upstream of SW1**, switching the unit off does not protect it. D2
> is a default-fit BOM part, so this is the state you get unless you act.

**Access cost, so it is not a surprise:** JP1 and Q1 sit under the socketed TP4056, while
**D1 and D2 sit under the PCM5102A**. Executing the fallback means lifting *both* modules.
Decide fit-or-DNP for the power path **before** the TP4056 is wired down — if J5/J6 end up
soldered rather than socketed, JP1 becomes a desoldering job.

### 4.5 What to actually build for the show

The review's conclusion, and the default this document now takes:

- **Plan A — JP1 + the manual rule.** Bridge JP1 and omit the power-path parts. **The
  load-bearing five are Q1, Q2, U1, D1 and D2** — those carry current or can inject into the
  cell. **R7/R8 must come off too**, not for safety but because JP1 ties them across the
  battery: 231 µA for a divider with no comparator behind it, which is the whole shelf-life
  budget §4.2 argues about. R6, R9 and R12 do nothing with Q1/Q2/U1 absent — fit them or
  don't. Just never leave **D2** in. Keep "switch OFF before plugging any USB" as permanent
  operating procedure. This is the topology that has been running on the breadboard for
  weeks. The hazard needs a human to plug USB with the switch ON; charging is a
  between-shows activity and flashing is bench-only, so show-time exposure is near zero.
  Add a silk-legend habit: *switch off, then plug in.*
- **Plan B — populate the block** only if the amended §4.4 passes unambiguously on an
  assembled carrier. Its headline benefit (run while charging) is not show-critical:
  ~13 h of NETWORK runtime against a ≤5 h show means mid-show charging never happens.
- **v1.2 — do it properly.** Replace the whole block with an ideal-diode controller that
  senses the drop across Q1 rather than an absolute voltage on the load node
  (**LTC4412**, SOT-23-6, hand-solderable), or move to a charger with a real power path
  (BQ24074 / MCP73871 breakout). Either deletes §4.1's hard constraint instead of working
  around it.

The PCB is identical under all three — that is what JP1 buys.

---

## 5. On-board BOM (per board, modules excluded)

Quantities are per board; build 4 (a 5th possible later), order parts for ~6 (spares). Example parts are LCSC-searchable MPNs;
⚠️ VERIFY exact LCSC stock codes at order time (codes drift) — search by the MPN given.

> **📦 ORDERED 2026-07-27 — this BOM is closed for a §4.5 plan-A build.**
>
> **Bought:** SW1 slide switches (**SS12D00, 6 mm handle** — see the SW1 row for the accepted
> 0.3 A deviation) · 2.54 mm female header assortment · **DMG3415U-7 ×10** (Q1) · TO-92
> PNP/NPN assortment (Q2 substitutes) · **JST-PH 2.00 mm** connector kit · **RV097NS-B10K ×5**
> (5-pin mono *with switch*, right-angle) · M3 heat-set inserts + screws.
>
> **From stock (drawer-checked 2026-07-27):** machined round-pin sockets (J5/J6/J9/J10 — **6**
> per board since 2026-07-28, not 4) · 6×6 mm
> tactile (SW2) · 3 mm LEDs (D4/D5) · 220 µF 10 V ×10 (C1) · 100 nF "104" (C2–C5) · all
> resistor values · male header strip + pigtail wire (J7, mic pigtails). 5 V/2 A wall charger
> confirmed on hand (mandatory per §4.3 state 2).
>
> **Deliberately not bought — the plan-B power-path parts: U1, D1, D2, D3, R7, R8, R9.**
> Per §4.5 the board ships with JP1 bridged, so these have no function; **D2 in particular must
> never be fitted on a JP1 board** (§4.4). Q1 and a PNP for Q2 *were* bought anyway, as cheap
> insurance if §4.4 later passes on an assembled carrier — populating the block then needs
> only the TL431A, two BAT85, an SS34 and three resistors.
>
> **Two near-misses worth remembering.** A **JST XH-2.54** kit was ordered first and swapped:
> XH is 2.5 mm and mates neither J8 (`S2B-PH-K`, 2.00 mm) nor the cell's pre-fitted lead. And
> the header assortment carries no 1×9 or 1×3 — **cut J3 from a 10-pin and J4 from a 4-pin**,
> accepting the destroyed position.

| Ref | Qty | Part | Example MPN / LCSC search | Package | Notes |
|---|---|---|---|---|---|
| Q1 | 1 | P-FET −20 V | **DMG3415U-7** (Diodes) | SOT-23 (SMD) | hand-solder pads; THT fallback: none good at low Vgs — keep SOT-23 |
| Q2 | 1 | PNP BJT | **BC557B** | TO-92 | any small PNP works |
| U1 | 1 | Shunt ref | **TL431A** (±1 %, TO-92) — the **grade** sets the trip window, the **brand** sets the TO-92 lead order (see the boxed note below; check both). Better if you can source it: **TLV431A** (onsemi `TLV431ALPRAG`) with R7/R8 → 100 k/38.3 k | TO-92 | comparator duty only |
| D1 | 1 | **Schottky** | **BAT85S** (DO-35) — or BAT54 if you prefer SOT-23 | DO-35 | gate OR. **Not** a 1N4148: the silicon drop is on the wrong side of D2's and leaves Q1 only partly off while charging (§4.3 states 2/3) |
| D2 | 1 | Schottky 3 A | **SS34** (LCSC C8678 ⚠️ VERIFY) or THT **1N5817**/**1N5822** | SMA / DO-41 | dual THT+SMA footprint. ⚠️ **Omit entirely if JP1 is bridged** (§4.4) |
| D3 | (1) | Schottky small | **BAT85** | DO-35 | **DNP** — experiment only (§4.1) |
| D4 | 1 | LED 3 mm green | e.g. Hongli 3 mm green | THT | NET status |
| D5 | 1 | LED 3 mm amber/yellow | e.g. Hongli 3 mm yellow | THT | MODE status |
| R1, R2 | 2 | 100 k 1 % | generic 1/4 W metal film | axial | battery divider (`VBAT_DIVIDER 2.0`) |
| R3 | 1 | 10 k | generic 1/4 W | axial | GPIO2 strap pull-up |
| R4, R5 | 2 | 2.2 k | generic 1/4 W | axial | LED series (per config.h "~2.2k") |
| R6, R12 | 2 | 100 k | generic 1/4 W | axial | gate pull-down / PNP B-E |
| R7 | 1 | **8.2 k 1 %** | metal film | axial | sense divider top — see the §4.2 divider table before committing |
| R8 | 1 | **10 k 1 %** | metal film | axial | sense divider bottom |
| R9 | 1 | **1 k** | generic | axial | TL431 cathode drive (2.2 k left the part below its 1 mA `I_KA(min)`) |
| R10, R11 | 2 | **0 Ω wire link** (100 Ω optional) | offcut of component lead, or a 0 Ω axial | axial | DAC → RCA-pad series. §10 Q2, closed 2026-07-28: the module already has ~470 Ω of its own, so 100 Ω more is 0.01 % of amplitude and ≲0.07° of phase — *equally on both channels*. Fit the link: it lies flat, and R10 stands at the DAC's corner where the standing-axial height is itself unverified |
| C1 | 1 | 220 µF ≥ 10 V electrolytic, **low ESR (≤ 0.5 Ω @ 100 kHz)** | e.g. Rubycon ZLH / Panasonic FR 220 µF 16 V — a 105 °C low-impedance part, not a general-purpose can | radial 6.3 mm | VLOAD bulk. **ESR is the spec that matters here, not the value** — at a 50 µs burst it sets the dip almost entirely, and 1000 µF of high-ESR is worse than 220 µF of low. See power-budget §4.3. |
| C2, C4, C5 | 3 | 100 nF X7R | generic | 2.54 mm radial | decoupling |
| C3 | 1 | 100 nF X7R | generic | 2.54 mm radial | across R2 (ADC filter) |
| SW1 | 1 | SPDT slide | **SS12D00, 6 mm handle — ✅ ordered 2026-07-27** (alternative: SK12D07-class, 1 A) | THT | power. ⚠️ **Accepted deviation** — this doc previously said the 1 A part was *required* because the SS12D00's 0.3 A is below the ≈0.35 A WiFi TX peak. That compares a peak current against a **make/break rating specified at 50 VDC**, and arc energy scales with the voltage being interrupted: at the ~4 V this switch actually breaks there is no arc to speak of, and 0.35 A through the contacts is a thermal non-event. Revisit only if contact resistance climbs in service. **6 mm handle** chosen so the actuator clears the enclosure wall — no length had ever been specified |
| SW2 | 1 | Tactile 6×6 mm | **TS-1102** / Omron B3F-1000 style | THT 6×6, 4-pin | MODE |
| RV1 | 1 | 10 k linear pot, 9 mm (B10K) | **RV097NS-B10K, "5-pin mono *with switch*", right-angle** (metal shaft, body 27.3 × 9.5 × 11.3 mm) | RV097NS THT (5-pin, ⌀1.0 holes) | shaft turned directly — **no knob** (enclosure needs only a shaft hole). ⚠️ **Do not substitute the 3-pin or the vertical variant** — see the box below |
| X, Y | — | RCA output landings (signal + AGND solder pads) | no connector part — reuse the ~50 cm RCA cables from the old sigma-delta units | 2× pad-pair | Finn solders the RCA cable leads directly; scope side uses a BNC→RCA adapter |
| J8 | 1 | JST-PH 2-pin side entry | **S2B-PH-K-S** (JST) | THT | battery socket; cell = EEMB LP103454 2000 mAh (off-board, pre-fitted JST-PH lead) |
| J1A/J1B | 2 | Female header 1×8 | generic 2.54 female | THT | SuperMini |
| J2 | 1 | Female header 1×6 | generic | THT | DAC I2S |
| J3 | 1 | Female header 1×9 | generic | THT | DAC analog/config end (only LROUT/ROUT/AGND netted; rest mechanical/NC) |
| J4 | 1 | Female header 1×3 | generic | THT | mic pigtail (`VCC GND OUT`) |
| J5, J6, **J9, J10** | **6** | **Machined single-pin socket** (turned-pin, e.g. a Mill-Max 0305 series single, or singles broken off a machined DIP socket) | — | THT | TP4056, **and it is six now, not four**. **A stock 1×2 female header cannot mate** — the module's pads are at 3.526 / 3.106 mm, not 2.54 (§2). J9/J10 are the USB-C-end mount row 21.65 mm away — see the assembly box below for why four in one line is not enough. Alternative: solder wires and give up removability |
| J7 | 1 | Male header 1×2 | generic | THT | debug TX |
| JP1 | 1 | 0 Ω / solder jumper | — | 2.54 mm | power-path escape hatch (open by default). ⚠️ **If bridged, D2 must be omitted** — and Q1/U1/Q2/D1 with it (§4.4) |
| TP1–TP5 | 5 | testpoint pad | — | 1.5 mm pad | no part |
| — | 4 | M3 screw + standoff | — | — | mounting (§6) |

Order **fixed-size** female headers (1×8, 1×6, 1×9, 1×3) — female strips do not snap cleanly;
each cut destroys one position. **The TP4056 is the exception:** its four pads are at
0 / 3.526 / 10.960 / 14.066 mm (photogrammetry 2026-07-26 — the old "close to 2.54 grid"
guess is answered, and the answer is no), so fit **individual machined pins**, not a
2.54 mm strip, which cannot span them.

> **⚠️ TO-92 orientation — check before you solder U1 and Q2.** `design.py` assigns
> **pad 1 = REF, pad 2 = ANODE, pad 3 = CATHODE** for U1, which is the *onsemi* numbering.
> **TI numbers the same TO-92 package the other way round** (pin 1 = K, pin 2 = A,
> pin 3 = REF), and since the **anode is the centre lead in both**, a TI-branded TL431 drops
> into the footprint perfectly while sitting backwards. The footprint is an inline 3-pad
> strip, so the silk outline will not save you. Q2 (BC557) carries the same class of trap —
> C-B-E and E-B-C both exist in TO-92 across vendors. Read the lead order off the datasheet
> of the part you actually bought and confirm **REF lands on the pad wired to VSW_SENSE**
> (ohm it out against R7/R8 before powering up). This applies equally to the TLV431A option.

> **⚠️ RV1 — buy the right one of the three RV097NS variants.** Sellers list "RV097NS"
> against at least three different parts, and only one fits this board:
>
> | variant | pins | row 2 | fits? |
> |---|---|---|---|
> | **5-pin mono *with switch*, right-angle** | 5 | SPST, ⌀1.0 holes **5.0 mm apart, 6.25 mm behind** the pot row | ✅ **this one** |
> | 5-pin vertical, with bracket lugs | 3 + 2 lugs | oval lug slots ~9.5 mm apart, ~7 mm behind | ❌ shaft points up; lug slots miss |
> | 3-pin (no switch, no lugs) | 3 | — | ⚠️ pot works, two holes stay empty, and the part loses its only rear anchoring |
>
> The board expects the first. Its **mounting surface is 5.0 mm in front of the pot row and
> lands exactly on the board's south edge**, so the M7×0.75 bushing and the 15 mm ⌀6 shaft
> hang off the edge and through the enclosure wall. Identify it by the cross-section:
> **9.5 mm wide × ~11.35 mm tall** (calipers 2026-07-18 read 9.5 × 11.3).
>
> **Pads 4/5 are the switch and both go to GND.** That is deliberate, not a leftover: there
> is no safe spare GPIO to give it (GPIO0 is `MIC_OUT`; GPIO8/9 are strapping pins that must
> be high at reset, and a switch that makes at full-CCW would hold one low and block boot;
> GPIO21 is the console UART TX, an output). Parking both ends in the GND pour also gives
> the part its only rear mechanical anchoring — these two 0.8 mm pins plus the panel nut are
> all that resist the torque of a bare shaft turned by hand, because **this variant has no
> bracket lugs**. Closing the switch shorts GND to GND and nothing happens.
>
> *Corrected 2026-07-27. Before that the footprint drew row 2 as two oval bracket-lug slots
> 9.5 mm apart and 7.0 mm back — every row-2 pad 2.25 mm out in X and 0.75 mm in Y, and the
> mounting surface 3.8 mm out. The part would not have gone into the board.*

`IN+` no longer connects via a wire — **J6b (`J9`) is a socketed pin** through the module's
`+` corner pad (2026-07-28; it had to move 0.65 mm west to land on it, see below). That
matters for current, not tidiness: in §4.3 state 2 the **entire board load** runs
charger → D2 → VSW through this connection — ~150 mA average, ~350 mA on WiFi TX bursts, plus
a ~4 A/<100 µs inrush blip into C1 at plug-in. A 0.64 mm pin in a turned-pin socket carries
that with room to spare, and it removes the one hand-soldered wire from the power path. (On a
**§4.5 plan-A board** the net is idle anyway: with D1/D2 omitted, `VBUS_CHG` reaches only TP1.
Note that TP1 is then **live at 5 V whenever the charger is plugged in** — it always was going
to be, via the wire; it is just no longer optional.)

> **📐 TP4056 assembly — two steps that are not obvious, both out of the caliper sessions
> ([measurements.md §Nubs](measurements.md) 2026-07-27, §The second mount row 2026-07-28).**
>
> **1. File the two nubs off first.** The module's west edge is not straight: two
> depanelization tabs protrude ~1.6 mm at the OUT− and OUT+ corners. They are bare
> soldermask — no copper, no silk, no trace — so filing them flush to the main west edge is
> safe, and it is what makes the body match the modelled outline (west edge x ≈ 43.9, within
> 0.15 mm). Left on, the SW nub reaches x ≈ 42.2 and the gap to **RV1's body**
> (`x 32.05…41.55, y 37.0…50.0`) drops from 2.4 mm to ~0.7 mm — between a PCB corner ~4 mm up
> and an 11.3 mm-tall pot. Not a collision; just not worth living with for 30 s of work.
>
> **2. Pins into the module first, then onto the carrier.** Push the machined pins into the
> TP4056's holes, *then* lower that assembly into J5/J6/J9/J10 and solder the carrier side.
> The module's holes are **~1.5 mm, not the 2.0 mm** assumed (calipers 1.43; the
> photogrammetry's "2.0 nominal" was pulled up by one bad pick), and calipers read the pad
> span ~0.25 mm shorter than the 14.066 mm the copper is built to — well inside the ~0.45 mm
> radial slack per hole, but only if the *module* sets the pin positions. Solder the pins to
> the board first and you are fighting rigid pins into holes at a span you did not choose.
>
> Step 1 changes nothing on the board. Step 2 covers **six** pins, not four — see the next
> box for where the other two came from.

> **🔩 SIX pins, not four — the USB-C end is mounted too (2026-07-28, and this one moved
> copper).** J5/J6 are all in **one column at one end** of the module, and the USB-C jack is
> **21.65 mm** away at the other. A row of pins resists rotation about its own axis only by
> bending — order of magnitude, a **5 N off-axis nudge on the plug tilts the module ~25°** —
> and that is the one connector on this build that gets handled every charge cycle, at 10–20 N
> of insertion force each time.
>
> The module already had the fix on it: **two ~2.8 mm bare-copper pads on 1.68 mm plated
> holes** at the USB-C-end corners, in line with OUT+ (`+` silk, next to `R8`) and OUT−. The
> carrier already had a pad on one of them — J6b/`J9`, drawn as a wire pad for the IN+ sense
> tap. So: **J9 became a socket and moved 0.65 mm west** onto the real hole position, and
> **`J10` was added** on the other corner. Four-in-a-line becomes a four-corner mount.
>
> - **`J10` is on no net.** Its job is mechanical. §2 asserts `IN− ≡ OUT−` and that is the
>   usual protected-TP4056 topology, but it has **never been ohmed on this module** — and if
>   it is wrong, bonding it to carrier GND shorts across the DW01/FS8205 and the cell loses
>   its protection. A floating pin anchors just as well. Ohm it later if you want it bonded.
> - **If a mount pin will not enter,** drill those two module holes to **2.0 mm** — the pads
>   are 2.8 mm of copper carrying no current here, and it takes the slack from 0.39 to
>   0.55 mm. Three independent routes put the 21.65 mm figure inside ±0.2 mm, against 0.39 mm
>   of slack — so this should not be needed.
> - The offset is **caliper, not photogrammetry** — the picks say 22.30 mm, which is 0.65 mm
>   of a 0.39 mm slack budget. [measurements.md §The second mount row](measurements.md)
>   has the reduction and the cross-check that settles it.
>
> The **outline** in `TP4056.json` is still deliberately not edited — see measurements.md.
> What changed is a pad position and a pad count, not the module model.

---

## 6. Layout guidance
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

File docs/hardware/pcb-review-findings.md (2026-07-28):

# Carrier PCB v1.1 — Critical Design Review Findings

**Date:** 2026-07-26 · **Method:** multi-agent adversarial review (4 independent analysts:
firmware cross-check, power-path electrical critique, minimalist/simplification advocate,
cross-document consistency audit; all major/moderate power-path findings independently
adversarially verified). **Scope:** `hw/carrier/` vs `docs/hardware/wiring.md` (breadboard
design), firmware `src/esp32-slave/`, and the current USB-only bench rig (SuperMini + PCM5102A
+ MAX4466 + pot).

**Headline verdict:** the design is *not* broadly overcomplicated — of ~27 fitted non-connector
parts, 12 are the existing breadboard design the USB-only rig simply hasn't built yet, ~10 are
the one genuinely new block (the §4 load-sharing power path), and ~5 are pennies of decoupling.
But the load-share block's paper analysis fails adversarial review in two confirmed places, and
the documented JP1 fallback recipe contains a confirmed battery-abuse bug. All fixes are
BOM-value or doc-only — nothing touches the routed layout. Recommended default: order on
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

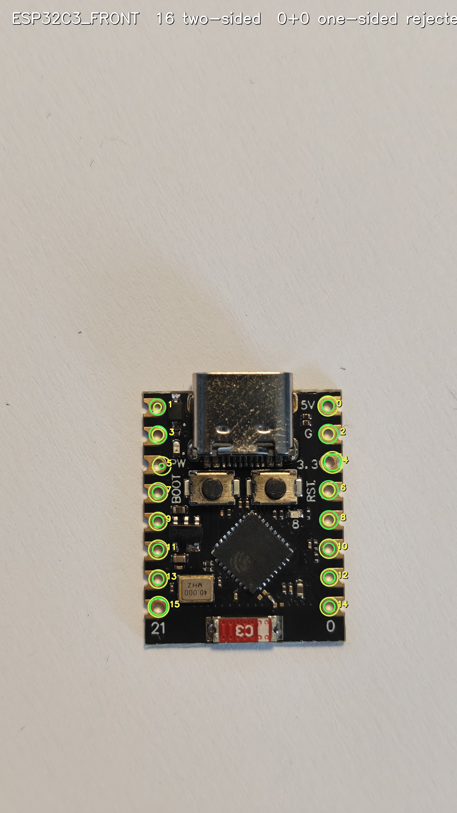
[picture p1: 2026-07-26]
hw/pin_locs/ESP32C3_confirmed.jpg

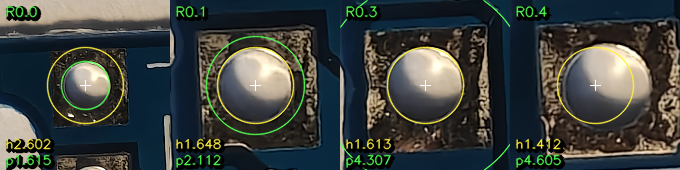
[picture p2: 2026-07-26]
hw/pin_locs/TP4056_pads.png

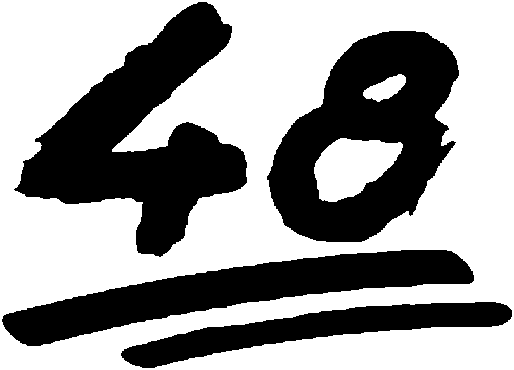
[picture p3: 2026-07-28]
hw/carrier/art/484848-mono.png

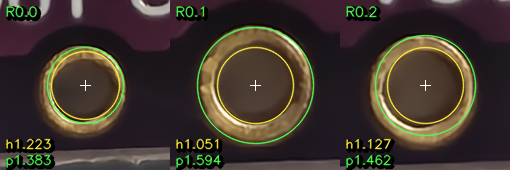
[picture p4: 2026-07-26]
hw/pin_locs/MAX4466_pads.png

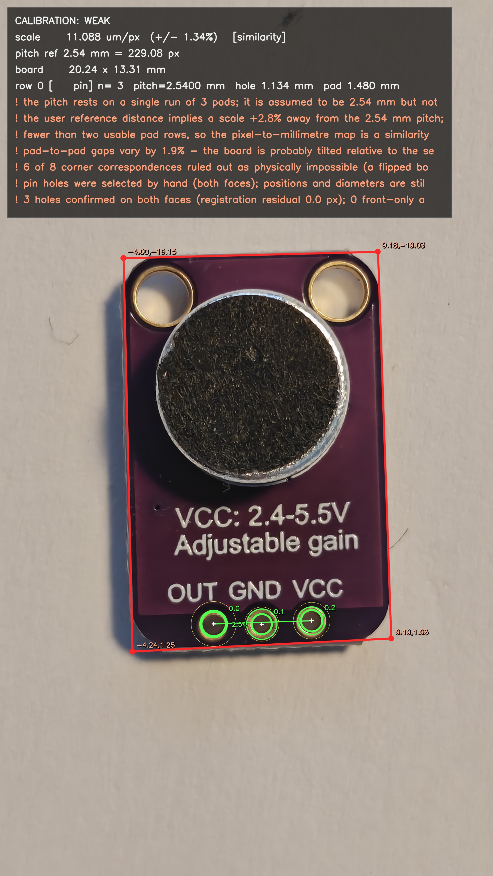
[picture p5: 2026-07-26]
hw/pin_locs/MAX4466_overlay.jpg

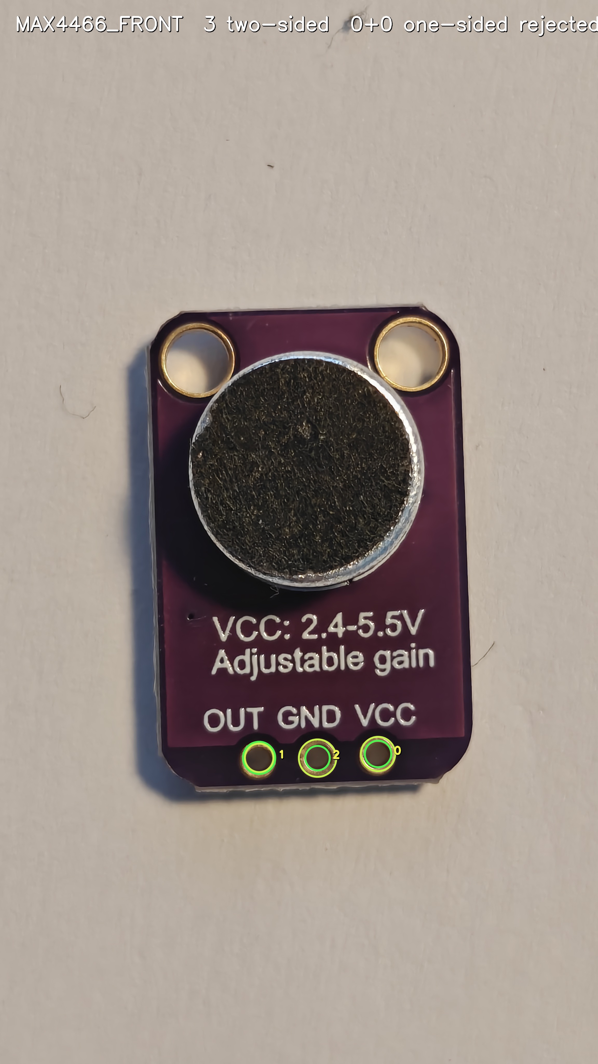
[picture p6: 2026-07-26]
hw/pin_locs/MAX4466_confirmed.jpg

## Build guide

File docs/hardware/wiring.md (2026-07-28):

# HYPEROSCI — Slave Unit Wiring Guide

**Scope:** one slave unit, breadboard bring-up. Every **signal** net here matches the carrier
PCB one-to-one, so the breadboard build *is* the schematic rehearsal for everything the
firmware touches. The **power chain is not** one-to-one — the carrier adds the load-sharing
path, which splits and renames things:

| Breadboard | Carrier | Note |
|---|---|---|
| `VBAT_RAW` | `BAT_PLUS` | same node: cell + / TP4056 `B+`, always live, R1 taps it here |
| `VBAT_SW` | `VSW` → SW1 → `VLOAD` | the switch now sits *downstream* of Q1; `VSW` is live off the cell whatever the switch position |
| — | `VBAT_OUT` | TP4056 `OUT+` → Q1 drain (+ JP1) |
| — | `GATE`, `VBUS_CHG`, `VSW_SENSE`, `TL431_K`, `Q2_B` | exist only on the carrier |

The breadboard has none of Q1/Q2/U1/D1/D2/D3/JP1, so §6's rules below are the *breadboard*
rules — see [pcb.md](pcb.md) §4.5 for which of them the carrier actually retires.
**Canon:** pins and constants come from [`src/esp32-slave/include/config.h`](../../src/esp32-slave/include/config.h)
and [DESIGN.md §4/§5/§9](../DESIGN.md). If anything below disagrees with those files, those files win.

Related docs: [power-budget.md](power-budget.md) (current/runtime derivation), [pcb.md](pcb.md)
(carrier board, load-sharing power path, full BOM).

---

## 1. Nets overview

| Net | Description | Voltage |
|-----|---|---|
| `VBAT_RAW` | LiPo+ / TP4056 `B+` — always live | 3.0–4.2 V |
| `VBAT_SW` | after power switch, feeds SuperMini `5V` pin | 3.0–4.2 V (or 5 V from USB-C when plugged, switch OFF) |
| `3V3` | SuperMini onboard LDO output — powers *everything else* | 3.30 V |
| `GND` | single common ground (battery, logic, analog, scope) | 0 V |
| `VBAT_SENSE` | 100k/100k divider midpoint → GPIO1 | VBAT/2 = 1.5–2.1 V |

Everything except the SuperMini itself runs from `3V3`. Nothing else touches `VBAT_SW`.

## 2. Full connection table

Wire-by-wire. "SM" = ESP32-C3 SuperMini (go by **silkscreen labels**, not physical position —
silk layouts vary between clone batches; some boards print `RX`/`TX` instead of `20`/`21`.
On the ESP32-C3, silk `RX` **is** GPIO20 and silk `TX` **is** GPIO21).

### 2.1 Power chain

| # | From | To | Notes |
|---|---|----|---|
| P1 | LiPo `+` (JST red) | TP4056 `B+` | battery pads, silk-labeled on module |
| P2 | LiPo `−` (JST black) | TP4056 `B−` | |
| P3 | TP4056 `OUT+` | power switch, terminal A | slide switch, either outer terminal + center |
| P4 | Power switch, terminal B | SM `5V` pin | this is net `VBAT_SW` |
| P5 | TP4056 `OUT−` | `GND` rail | |
| P6 | SM `GND` pin | `GND` rail | |
| P7 | SM `3V3` pin | `3V3` rail | source for all peripherals |
| P8 | Bulk cap ≥220 µF `+` | SM `5V` pin (`VBAT_SW`) | electrolytic, **observe polarity**, `−` to `GND`; buffers WiFi TX bursts |

TP4056 module pad positions differ between clone batches — always go by the silk
(`B+ B− OUT+ OUT−`, USB input on the connector end). Confirm yours is the **protected** variant: two extra ICs (DW01 6-pin + FS8205 8-pin) near
the output pads. The owned modules are the **USB-C blue** boards — `CSM4056T` + `8205LA`
(FS8205) + DW01-type, confirmed 2026-07-18. (`03962A` is the older micro-USB part number.)

### 2.2 Battery sense (GPIO1)

| # | From | To | Notes |
|---|---|----|---|
| S1 | TP4056 `B+` (`VBAT_RAW`) | R_top 100 kΩ → node `VBAT_SENSE` | tap the **battery** side, *before* the switch — always connected, ~21 µA drain |
| S2 | Node `VBAT_SENSE` | R_bot 100 kΩ → `GND` | |
| S3 | Node `VBAT_SENSE` | C 100 nF → `GND` | across the bottom resistor, ADC sampling reservoir |
| S4 | Node `VBAT_SENSE` | SM `GPIO1` | ADC1_CH1, `PIN_VBAT_ADC` |

The 100 kΩ source impedance limits back-injection into the unpowered chip (switch OFF) to
~15 µA — harmless, this is the standard always-on divider arrangement.

### 2.3 I2S DAC (GY-PCM5102A)

| # | From | To | Notes |
|---|---|----|---|
| D1 | SM `GPIO4` | PCM5102A `BCK` | `PIN_I2S_BCK`, 1.536 MHz at 48 kHz/16-bit stereo |
| D2 | SM `GPIO5` | PCM5102A `LCK` | `PIN_I2S_LRCK`, 48.0 kHz |
| D3 | SM `GPIO6` | PCM5102A `DIN` | `PIN_I2S_DOUT` |
| D4 | `3V3` rail | PCM5102A `VIN` | feeds the module's onboard XC6206 LDO (fine, see DESIGN §5) |
| D5 | `GND` rail | PCM5102A `GND` | |
| D6 | PCM5102A `SCK` | `GND` | **required** — internal PLL clock from BCK; see §4 |
| D7 | PCM5102A `LROUT` (1×9 hdr) — or jack **tip** | Scope CH1 (X) | see §5 |
| D8 | PCM5102A `ROUT` (1×9 hdr) — or jack **ring** | Scope CH2 (Y) | see §5 |
| D9 | PCM5102A `AGND` (1×9 hdr) — or jack **sleeve** | Scope GND clips | common with system `GND` |

Keep the three I2S wires short (<10 cm) and away from the mic — BCK is a 1.5 MHz square wave.

### 2.4 Microphone (MAX4466)

| # | From | To | Notes |
|---|---|----|---|
| M1 | `3V3` rail | MAX4466 `VCC` | |
| M2 | `GND` rail | MAX4466 `GND` | |
| M3 | MAX4466 `OUT` | SM `GPIO0` | `PIN_MIC_ADC`, ADC1_CH0, idles at ~VCC/2 ≈ 1.65 V |

Set the back-side gain trimmer to mid-travel to start; fine-tune later while watching the
scope. ⚠️ VERIFY: trimmer rotation direction vs. gain varies between module clones — find it
empirically. Point the electret capsule outward/away from the boards.

**Mounting:** the MAX4466 rides on a short ~10 cm pigtail — three jumper wires (`VCC` / `GND` /
`OUT`, nets M1–M3) — that exits the enclosure; it is **not** soldered flat to the carrier. This
lets you aim the capsule at the PA and reach the gain trimpot with a screwdriver after assembly.
The carrier provides a matching 3-pin pigtail landing/header (`VCC` / `GND` / `OUT`), not a flat
on-board footprint.

### 2.5 UI: pot, button, LEDs, GPIO2 pull-up

| # | From | To | Notes |
|---|---|----|---|
| U1 | Pot pin 3 (CW end) | `3V3` rail | 10 kΩ pot = **RV097NS-B10K** (5-pin **mono with switch**, right-angle; metal shaft turned by hand — no knob). Pins 4/5 are the SPST, not lugs: both to GND, unused |
| U2 | Pot pin 1 (CCW end) | `GND` rail | this orientation ⇒ clockwise = higher voltage = higher Y-filter cutoff |
| U3 | Pot pin 2 (wiper) | SM `GPIO3` | `PIN_POT_ADC`, ADC1_CH3 |
| U4 | Mode button, leg A | SM `GPIO7` | `PIN_BTN_MODE`; internal pull-up in firmware — **no external resistor** |
| U5 | Mode button, leg B | `GND` rail | 6×6 mm tactile: use two legs on the *same* switch side, or diagonal legs |
| U6 | SM `GPIO10` | 2.2 kΩ → green LED anode | `PIN_LED_NET`, active high |
| U7 | Green LED cathode | `GND` rail | flat side / short leg to GND |
| U8 | SM `GPIO20` (silk may say `RX`) | 2.2 kΩ → amber LED anode | `PIN_LED_MODE`, active high |
| U9 | Amber LED cathode | `GND` rail | |
| U10 | SM `GPIO2` | 10 kΩ → `3V3` rail | strapping pin, must be high at reset; **nothing else** on this pin |

2.2 kΩ gives ~0.5 mA per LED — deliberately dim for battery life; modern high-efficiency
3 mm LEDs are clearly visible. If yours are too dim, 1 kΩ is fine (config.h says "~2.2k").

### 2.6 Not wired (reserved / onboard)

| Pin | Status |
|-----|---|
| SM `GPIO8` | onboard blue LED (active-low heartbeat) — leave the pin unconnected |
| SM `GPIO9` | onboard BOOT button (test-pattern cycling after boot) — leave unconnected |
| SM `GPIO21` (silk may say `TX`) | reserved UART0 TX debug header — leave unconnected for now |
| TP4056 USB connector | charge input only, own cable; see rules in §6 |
| SM USB-C | flash/debug/console only; see rules in §6 |

**Wire count sanity check:** 8 power + 4 sense + 6 DAC digital + 3 DAC analog + 3 mic +
3 pot + 2 button + 4 LED + 1 pull-up ≈ **34 connections**.

## 3. Overall wiring diagram

The wiring diagram is a real KiCad schematic, generated from the same netlist source of
truth as the carrier PCB (`hw/carrier/tools/design.py`) and gated by the same checks
(`check_netlist.py` against `config.h`, ERC, DRC schematic parity) — unlike the ASCII art
that used to live here, it cannot silently drift from the board or the firmware pin map:

HYPEROSCI slave unit wiring diagram

Printable A3: [`hw/carrier/carrier-schematic.pdf`](../../hw/carrier/carrier-schematic.pdf).
Regenerate after any `design.py` change: `python3 tools/gen_schematic.py`, then re-export
the SVG/PDF per [`hw/carrier/layout-notes.md`](../../hw/carrier/layout-notes.md).

Reading it as a *breadboard* guide: everything **except** the dashed "LOAD-SHARING POWER
PATH" block is wired 1:1 on the breadboard (the §2 tables above stay the wire-by-wire
authority). The breadboard power chain is `OUT+ → switch → SuperMini 5V pin` direct — see
the "BREADBOARD DELTA" note on the sheet and the net-name mapping table at the top of this
file (`VBAT_RAW` = `BAT_PLUS`, `VBAT_SW` ≈ `VLOAD`).

## 4. GY-PCM5102A module prep (do this FIRST, before any wiring)

The purple GY-PCM5102 modules **often ship with all four back-side solder bridges open**.
With bridge 3 (XSMT) open/low the DAC is *hard-muted* — the #1 cause of "no output".
Solder all four before first power-up:

| Bridge | Function | Set to | Meaning |
|---|---|---|---|
| 1 | FLT | **L** | normal-latency FIR filter (revisit H = low-latency during §12 ringing test) |
| 2 | DEMP | **L** | de-emphasis off |
| 3 | XSMT | **H** | soft-mute released — DAC actually outputs |
| 4 | FMT | **L** | standard I2S format |

Each bridge is three pads in a row: center pad plus `H` and `L` pads. Blob solder from
**center to L** on bridges 1, 2, 4 and **center to H** on bridge 3. Inspect with
magnification — a bridge accidentally spanning all three pads shorts 3V3 to GND on that pin.

**SCK to GND (front side):** the DAC then generates its clock internally via PLL from BCK —
no MCLK from the ESP32 needed. Two options:

1. Breadboard: simply jumper the `SCK` header pin to `GND` (wire D6). Always works.
2. Many purple boards have a small two-pad solder jumper on the front near the SCK pin that
   ties SCK to GND through the board. ⚠️ VERIFY with continuity (SCK↔GND = 0 Ω after
   soldering) before trusting it — pad presence varies between batches.

On the carrier PCB the SCK socket pin is tied straight to the ground plane.

**After prep, before install:** continuity check SCK↔GND (short), and no short VIN↔GND.

## 5. PCM5102A → oscilloscope

| PCM5102A | Scope | Signal |
|---|---|---|
| `LROUT` — 1×9 header pin, or 3.5 mm jack **tip** | CH1 | X |
| `ROUT` — 1×9 header pin, or jack **ring** | CH2 | Y |
| `AGND` — 1×9 header pin, or jack **sleeve** | probe GND clips | common ground |

- **Analog header (measured 2026-07-18):** the purple module's analog end is a **1×9** header
  on the long edge (⊥ to the 6-pin I2S row), silk (jack→digital):
  `LROUT AGND ROUT AGND A3V3 FMT XSMT DEMP FLT`. Tap **X = LROUT, Y = ROUT, gnd = AGND**. It is
  **not** a 3-pin `L G R` header — the old docs assumed wrong.
- **Deliverable output path (carrier board):** the carrier has *no* BNC or TRS jack. It
  exposes two RCA flying-lead solder pad-pairs (signal + ground), fed through the series
  R10/R11 positions — **fitted as 0 Ω links** (pcb.md §3.2 / §10 Q2, closed 2026-07-28):
  **X = PCM5102A LROUT**, **Y = PCM5102A ROUT**. Signal chain is
  board RCA pad → reused ~50 cm RCA cable (RCA male, salvaged from the old sigma-delta units)
  → BNC→RCA adapter already fitted on the scope → scope CH, in XY mode.
- **Bench bring-up shortcut (recommended for W1–W2):** you can skip the carrier RCA pads
  entirely and drive the scopes straight from the module's on-board **3.5 mm LINE OUT jack** —
  tip = X (LROUT), ring = Y (ROUT), sleeve = GND — via a 3.5 mm→2×RCA (or →2×BNC) cable. This
  needs no carrier at all, so early testing isn't gated on the PCB. Final units use the RCA pads.
- Note: the module carries a ~470 Ω "471" output filter before these pins/jack (measured) —
  the output is still ground-centered. **R10/R11 is settled: fit 0 Ω links** (pcb.md §10 Q2,
  closed 2026-07-28). Do not spend bench time deciding it on the ramp — the module's own
  470 Ω swamps a 100 Ω part, which moves amplitude by 0.01 % and phase at 10 kHz by ≲0.07°,
  and does so identically on both channels, so the test has nothing to show.
- Scope setup: **XY mode**, CH1 = X, CH2 = Y, both **DC coupled**, both **1 MΩ** input
  (never 50 Ω termination — the line-out stage can't drive it); on the bench use ×1 probes,
  on the finished unit the reused RCA cable into the scope's BNC→RCA adapter. 1 V/div, traces
  centered.
- Expected full-scale output: **≈2.1 V RMS ≈ ±3 V peak (~6 Vpp) per channel**, ground-centered
  and DC-coupled (the chip's internal charge pump makes a negative rail — no DC offset to
  fight, a full-scale circle sits centered on the graticule).
- Don't hang headphones/speakers on the outputs while scoping; the scope's 1 MΩ is the
  intended load.

## 6. Power chain and safety rules (DESIGN §9)

Breadboard power chain, in order:

1. LiPo → TP4056 `B+`/`B−` (charge via its own USB; DW01 protection) → `OUT+`
2. `OUT+` → slide switch → SuperMini `5V` pin → onboard LDO → `3V3` rail
3. `3V3` → PCM5102A `VIN`, MAX4466 `VCC`, LEDs, pot, pull-ups
4. LiPo+ → 100k/100k divider → GPIO1 (always connected, ~21 µA)

**RULE 1 — the breadboard rule: NEVER have the power switch ON while the SuperMini USB-C is
plugged in.** Most SuperMini clones tie VBUS straight to the `5V` pin, so USB 5 V would
back-feed through the switch into TP4056 `OUT+` and push uncontrolled current into the LiPo,
bypassing the charger's CC/CV control. Flash and debug on USB **with the switch OFF** (the
whole circuit runs happily from USB: VBUS → 5V pin → LDO → 3V3).

**This rule does not automatically retire on the carrier.** The load-sharing path is meant to
remove it, but design review (2026-07-26) found that the SuperMini-side term — a voltage
threshold on the load node — cannot reliably distinguish a sagging laptop port from a charged
cell, and that this is exactly the situation the rule exists for. So: **keep RULE 1 until
pcb.md §4.4 passes on an assembled carrier**, and keep it permanently on a JP1-bridged board.
(Separately, and about the *charger's* USB rather than this one: in a JP1 build with D2 still
fitted, plugging the charger injects into the cell upstream of the switch, so RULE 2 below
does not protect you either — D2 must be omitted. See [pcb.md](pcb.md) §4.4/§4.5.)

**RULE 2 — charge with the switch OFF.** With a load on `OUT+`, the TP4056 can't tell load
current from charge current and may never terminate; the cell also sits at 4.2 V under load.
Charging via the TP4056's own USB with the switch OFF is the clean state.

**RULE 3 — one USB at a time is the safe habit.** TP4056-USB (switch OFF) = charging.
SuperMini-USB (switch OFF) = development. Switch ON with no USB = normal battery operation.

Practical bench habits:

- Put the switch where you can see it; flip it OFF before reaching for either USB cable.
- The GPIO1 divider is wired to `VBAT_RAW`, so battery voltage telemetry works even while
  running from USB with the switch OFF — handy for watching a charge cycle.
- All GNDs are one net, including scope probe grounds. When the scope (earthed) and a
  desktop PC (earthed) are both attached you've made a ground loop; at these signal levels
  it's harmless, but pure battery + scope is the clean measurement setup.

## 7. Breadboard layout tips

- Give the SuperMini the end of the breadboard with its **antenna overhanging the edge**;
  keep all wiring, the pot, and your fingers away from the antenna end.
- Power rails: top rail = `3V3`, bottom rail = `GND`. `VBAT_SW` only exists on the short
  jumper switch → `5V` pin, plus the bulk cap.
- Mic far from the DAC's I2S wires and from the switch-mode charge pump area of the
  PCM5102A module; mic wiring short.
- TP4056 modules have no breadboard pins — solder a 4-wire pigtail (`B+ B− OUT+ OUT−`) or
  a right-angle header. Same for the LiPo JST: use a JST-PH pigtail, never bare-wire the cell.
- The pot's 3 pins rarely fit a breadboard cleanly — pigtail it too.

## 8. Bring-up checklist

Order is deliberate: **rails → DAC → mic → WiFi**. Don't skip ahead; each phase assumes the
previous one measured clean. DMM required; scope required from Phase 4.

### Phase 0 — module prep (nothing powered)

1. PCM5102A: solder the 4 back bridges + SCK↔GND per §4.
   - **Measure:** continuity SCK↔GND = 0 Ω; VIN↔GND = open (no short); visual: no bridge
     spans all three pads.
2. TP4056: confirm protected variant (DW01 + FS8205 present near output pads).
   - Note: stock PROG resistor (1.2 kΩ) ⇒ ~1 A charge = ~0.5C on the selected 2000 mAh cell
     (EEMB LP103454) — comfortable, full charge ~2.5–3 h. Mandate 5 V/2 A wall chargers;
     the R_PROG swap is optional (fiddly to solder). On legacy 1000 mAh cells 1 A = 1C (warm)
     — swap R_PROG (2 kΩ ≈ 580 mA, 3 kΩ ≈ 400 mA).
3. MAX4466: gain trimmer to mid-travel.
4. LEDs: identify anode (long leg) before wiring; a DMM diode-test lights them.

### Phase 1 — battery + charger (no ESP32 yet)

1. LiPo → `B+`/`B−`. **Measure `OUT+`↔`OUT−`: 3.0–4.2 V**, equal to the cell voltage
   (protection FETs drop only millivolts).
2. Plug USB into the **TP4056**: red/CHRG LED on. Leave until blue/green (STDBY) if the
   cell is low. **Measure:** cell climbs toward 4.20 V ± 0.05 and terminates there.
3. Unplug TP4056 USB before continuing.

### Phase 2 — bare power rails

1. Wire P3–P8 (switch, SuperMini, bulk cap). No peripherals yet. USB-C **unplugged**.
2. Switch **ON**. **Measure:** SM `5V` pin = battery voltage; SM `3V3` pin = 3.30 V ± 0.1;
   nothing warm to the touch.
3. Optional: DMM (mA range) in series with the switch — a factory-fresh SuperMini draws a
   few tens of mA. Record the number; it's your baseline.
4. Switch **OFF**.

### Phase 3 — full wiring, quiescent checks

1. Wire everything else in §2 (DAC, sense divider, mic, pot, button, LEDs, GPIO2 pull-up).
2. Power from **USB-C, switch OFF**. Measure with the DMM (DC volts, black lead on GND):

   | Node | Expect | Meaning if wrong |
   |------|--------|------------------|
   | `3V3` rail | 3.30 V ± 0.1 | short/overload on a peripheral if it sags |
   | PCM5102A `VIN` | = `3V3` | wiring |
   | MAX4466 `OUT` (GPIO0) | ≈ 1.65 V DC (VCC/2) | dead mic module or missing VCC |
   | `VBAT_SENSE` (GPIO1) | = cell voltage ÷ 2 (≈1.9 V at 3.8 V) | divider values / tap point |
   | GPIO2 | 3.3 V | pull-up missing (boot will be unreliable) |
   | Pot wiper (GPIO3) | 0 → 3.3 V smoothly over full rotation | dirty/miswired pot |
   | GPIO7 | 3.3 V idle, 0 V pressed (after firmware enables pull-up) | button wiring |
   | PCM5102A `LROUT`/`ROUT` | ≈ 0 V DC | (no I2S clocks yet — anything near 0 V is fine here) |

### Phase 4 — flash + DAC test (circle pattern)

1. **Switch OFF**, USB-C plugged. Flash the slave firmware (PlatformIO, `esp32-c3-devkitm-1`).
   USB-CDC console shows the boot banner; onboard blue LED starts its 0.5 s heartbeat.
2. Probe the I2S bus (normal Y-T mode first):
   - **`GPIO5`/LCK: 48.0 kHz square, ~50 %** duty.
   - **`GPIO4`/BCK: 1.536 MHz** (48 kHz × 32, 16-bit stereo — the PLL ratio DESIGN §5
     requires).
   - `GPIO6`/DIN: data activity.
3. Short-press **BOOT** (onboard) to cycle the local test pattern to **circle** (DESIGN §7:
   mic → circle → Lissajous).
4. Scope in **XY mode** per §5. **Expect: a stable, centered circle.** At digital full scale
   the diameter is ~6 V (±3 V peak per axis); if the firmware's test amplitude is e.g. 0.8 FS,
   expect ±2.4 V. Verify:
   - Circle centered on (0,0) with both channels DC-coupled ⇒ confirms ground-centered,
     DC-coupled output (closes part of DESIGN §12 item 1 — also run the slow-ramp DC test
     when the firmware exposes it).
   - Clean, no gaps/jumps ⇒ PLL locked at 32× fs (closes §12 item 2).
   - In Y-T mode: CH1 and CH2 are equal-amplitude sines, 90° apart.
5. Cycle BOOT again for Lissajous; sharp-cornered patterns are the vehicle for the
   FLT=L vs FLT=H ringing comparison (§12 item 3) later.
6. No output? Checklist: XSMT bridge 3 actually soldered to **H** → SCK actually grounded →
   BCK/LCK swapped (most common wiring error) → bridge 4 FMT on L.

### Phase 5 — mic + pot (LOCAL mode)

1. Hold **MODE** (GPIO7 button) while resetting/power-cycling ⇒ boots straight into LOCAL,
   WiFi off (amber LED solid; DESIGN §7). Or just wait ~6 s for auto-fallback.
2. Scope XY: clap / whistle / play music at the mic. **Expect:** X deflection following the
   raw audio, Y showing only low-frequency content — the old proven unit's behavior, now
   at ±3 V instead of sigma-delta.
3. Sweep the pot lock-to-lock. **Expect:** Y-channel bandwidth audibly/visibly changes
   (cutoff 20 Hz fully CCW → 300 Hz fully CW). If the sense is reversed, swap pot ends
   (U1/U2).
4. Adjust MAX4466 gain trimmer so normal program material deflects most of the screen
   without clipping (clipping = flat-topped X extremes).
5. Battery telemetry: console/status should report `vbat_mv` ≈ 2 × the GPIO1 voltage you
   measured in Phase 3, within a few tens of mV.

### Phase 6 — WiFi / NETWORK mode

1. Bring up the AP (`HYPEROSCI_AP` / `hyperosci2026`, **2.4 GHz** — the UNO-Q's
   NetworkManager connection `hyperosci-ap` at 192.168.50.1/24, or any temporary
   2.4 GHz AP for a first test).
2. Reboot the slave in default mode. **Expect LED sequence (DESIGN §7):** green NET LED
   1 Hz blink (connecting/no stream) → **solid** once audio packets flow on UDP 5000 →
   5 Hz blink if you kill the stream (fallback active within ~1 s).
3. Stream a test signal from the controller; verify the scope pattern follows it and that
   killing the AP drops the unit back to the mic pattern in ~1 s (STREAM_TIMEOUT_MS).
4. **Measure current** (DMM in series with the switch, battery power, USB unplugged —
   switch ON only after unplugging!):
   - LOCAL, WiFi off: **~40–50 mA** @ 3.7 V
   - NETWORK, streaming (`WiFi.setSleep(false)`): **~110–125 mA**
   Record actuals in [power-budget.md](power-budget.md) (DESIGN §12 item 6).
5. While streaming, probe the `3V3` pin on the scope (AC-coupled, ~50 mV/div): WiFi TX
   bursts should not dip the rail more than ~100 mV. Repeat near VBAT = 3.5 V for the
   brownout check (DESIGN §12 item 4).

### Phase 7 — full battery soak

1. Everything off USB. Switch ON. Run NETWORK mode from the battery for ≥30 min.
2. **Expect:** stable circle/stream, no LED low-battery pattern above 3.45 V cell voltage,
   `vbat_mv` in status packets tracking the DMM within ~50 mV.
3. Done — this unit is the reference for cloning the other three, and its module outline
   caliper measurements (DESIGN §12 item 7) feed the PCB layout.

---

*Anything marked ⚠️ VERIFY must be checked on the physical modules before the PCB order
(~Aug 1). Deviations found go into DESIGN.md first, then back-propagate here.*

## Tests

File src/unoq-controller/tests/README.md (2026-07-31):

# controller regression checks

Run **on the board** — the dev box has no Hershey fonts and a different Python,
so it is not a valid reference for either behaviour or timing.

```bash
adb push tests/*.py /tmp/ && adb shell "mkdir -p /tmp/hcstage && \
  cp /home/arduino/hype_controller.py /tmp/hcstage/ && \
  cp /tmp/test_fixes.py /tmp/test_timers.py /tmp/hcstage/"
adb shell "cd /tmp/hcstage && python3 test_fixes.py"   # 6 bugs + the 8 show names
adb shell "cd /tmp && python3 test_persist.py"          # ~/hype_state.json round-trip + garbage
adb shell "cd /tmp/hcstage && python3 test_timers.py"   # interval-timer rules
adb shell "cp /usr/local/sbin/hyperosci-netwatch /tmp/nw_mod.py && \
           cd /tmp && python3 test_netwatch.py"         # watchdog trigger logic
adb shell "cd /tmp && python3 live_test.py"             # against the running daemon
```

`test_fixes.py`, `test_persist.py` and `test_timers.py` point
`HYPE_STATE`/`HYPE_PRESETS`/`HYPE_TIMERS` at a temp dir **before importing**
the controller. Keep it that way: `State()` restores the saved live pattern,
so without the override a test inherits whatever is currently on the scopes
(an assertion on a default field then fails for the wrong reason) and any
test that saves would write the show's real preset file.

`test_timers.py` drives `fire_timer`/`end_hold` directly with a stub
`CmdSender` and fabricated slaves — no sockets, no HTTP, nothing bound on
:5001/:5002 — so unlike `live_test.py` it is safe to run while the daemon is
serving a show.

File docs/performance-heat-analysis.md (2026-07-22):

# HYPEROSCI — Firmware Performance & Heat Analysis

**Date:** 2026-07-18 · **Scope:** ESP32-C3 slave firmware (`src/esp32-slave`) + controller
(`src/unoq-controller/tools/hype_controller.py`) · **Trigger:** "ESP runs hot even with a
heatsink; streaming performance drops a lot and seems inefficient."

Grounded in the firmware source, `docs/protocol.md`, `docs/DESIGN.md`,
`docs/hardware/power-budget.md`, and the **installed** `framework-arduinoespressif32-libs`
sdkconfig. Quantitative claims were adversarially cross-checked; where the first-pass numbers
were wrong they are corrected inline and flagged **[corrected]**.

---

## 1. Bottom line

Two independent problems, neither with the cause it first appears to have:

1. **"Runs hot"** is ~80% the **WiFi radio** (a locked design decision) and, *on the bench*,
   largely the **SuperMini's LDO burning USB volts as heat** — **not** the CPU. Firmware can
   trim a few °C and real battery-mA, but cannot make this chip "cool" while it streams.
   **The cheapest first action is to re-measure thermals on battery, not USB.**

2. **"Drops a lot"** is **not a bandwidth problem** (audio is only ~17–25 % airtime at 4 slaves).
   It is the **slave receive path silently discarding post-stall bursts** plus **controller-side
   pacing jitter** — and both are currently **invisible** on the dashboard because the lost
   packets are never counted.

---

## 2. What we send on the wire

| | Value | Source |
|---|---|---|
| Audio packet | **988 B** = 20 B `HypeHeader` + 8 B `HypeAudioPayload` + 960 B PCM (240 stereo int16 frames) | `protocol.h:36-43`, `config.h:28` |
| Rate per slave | **200 pkt/s** (5 ms blocks) → **1.58 Mbit/s** app layer | `hype_controller.py:42-49` |
| Fan-out | **Unicast, one identical copy to each of 4 slaves** (single shared `PatternGen`) | `hype_controller.py:587,638,642-644` |
| System total | ~6.8 Mbit/s on-air, ~812 pps | `protocol.md §8` |
| Airtime | **~16–18 % @ MCS7**, ~33 % @ MCS3 (collapse only at 6 Mbps basic rate) | `protocol.md §8` |
| SYNC | multicast `239.0.0.1:5001`, 20 B, 2/s | `hype_controller.py:600-604` |
| STATUS | unicast → controller, 55 B, 1/s per slave | `net_rx.cpp:144-180` |

**Key observation:** all four scopes receive the **identical** packet stream
(`protocol.md §4.3`, `§5.2`). The content today is **100 % parametric** — circle/lissajous/rose
synthesized from ~5 numbers in Python, streamed as PCM. `osci-render` (the arbitrary vector-audio
case that *genuinely* needs PCM streaming) is not yet integrated. So today we stream 1.58 Mbit/s
of audio to draw shapes the slaves could largely render themselves — see §6.

---

## 3. Why it runs hot

The felt heat is dominated by two things, only one of which is the C3, and neither is the CPU
optimizations one would reach for first.

| Contributor | Dissipation | Actionable? |
|---|---|---|
| **WiFi RX chain, `WIFI_PS_NONE`** (`net_rx.cpp:194`) | **~84 mA ≈ 80 % of chip heat** (`power-budget.md:32`); ~330 mW on-die, but spread over the 5×5 QFN you *have* heatsinked (~13–20 °C rise) | **Locked.** PS_NONE is what defeats the ath10k DTIM unicast-buffering stall (~110 ms). Do **not** touch before the show. |
| **SuperMini LDO on bench USB** (5.0→3.3 V across ~130 mA rail) | **~220 mW** in an un-heatsinked SOT-23-5 (θJA ~200–250 °C/W → **~45–55 °C junction rise**). A C3 heatsink does nothing for it. | **2–4× less on battery** (4.2→3.3 V ≈ 117 mW fresh, 3.7→3.3 V ≈ 52 mW mid-discharge). |
| CPU @ 160 MHz (no `setCpuFrequencyMhz`) | 80 MHz saves **~5 mA [corrected]** — *not* 8–15 mA. C3 datasheet: modem-sleep is 20 mA@160 vs 15 mA@80 (most core current is frequency-independent), and `setCpuFrequencyMhz` does **no** voltage scaling, so compute *energy* is unchanged — the busy window just stretches. | Yes, safe, small |
| Discarded-mic soft-float, every block (§5.1) | ~8–10 % of one core ≈ ~2–4 mA | Yes, safe |
| Continuous 73.5 kHz ADC (`config.h:29`) | analog + DMA overhead even when the mic is unused | Medium (see §5) |

### Honest framing

- The C3 is a single-core RV32IMC with **no FPU** — every `float` op is libgcc soft-float. That
  makes the CPU findings below real *inefficiency*, but the total firmware-side thermal win is
  only **~10–15 mA and a few °C**. That helps **battery life and CPU headroom**, not "cool."
- **On the bench you are USB-powered, so the LDO drop is likely what your finger feels.**
  Re-measure at ~3.9 V on battery before spending effort chasing die temperature.
- A top-of-package heatsink couples poorly to the C3 die anyway (the thermal pad is on the
  package **bottom**; heat leaves through PCB copper). PCB copper / airflow beats a stick-on sink.
- The *only* lever that touches the 84 mA radio floor is **not streaming continuously** so the
  radio can power-save — i.e. the param-synth architecture in §6. High-risk, long-term.

---

## 4. Why streaming drops (ranked — the real causes)

Airtime is fine, so this is a **receive-path and timing** problem. In order of likely impact:

### 4.1 Silent lwIP mailbox overflow — *the invisible drop*
`CONFIG_LWIP_UDP_RECVMBOX_SIZE = 6` (confirmed in the installed SDK sdkconfig). After a
~300 ms AP "deaf" stall, the AP flushes ~60 queued frames as a microburst. The consumer
`net_task` runs at **priority 5** (`net_rx.cpp:288`), below the CPU-bound audio task at
priority 10 (`main.cpp:55`), polling with `vTaskDelay(1ms)` (`net_rx.cpp:278`). When more than
6 packets pile up between drains, **lwIP drops the excess in the tcpip thread, below the socket
layer**. Those drops are **never counted**: `st_rx_dropped` only increments for packets that
*arrive* (`net_rx.cpp` `handle_audio_packet`), and `CONFIG_LWIP_STATS` is off so `udp.drop`
doesn't even exist. Result: the dashboard shows **`rx/s` sagging with `drop/s ≈ 0`** — exactly
"drops a lot but nothing looks wrong."
**Fix:** move audio RX to **AsyncUDP** — its raw `udp_recv` callback captures the pbuf in the
tcpip thread into a 32-deep queue, **bypassing the 6-slot socket mailbox** and draining the
instant a packet lands. It also removes the WiFiUDP `malloc(1460)` + ~3 memcpys per packet
(§4.5). *(Confidence: medium — the mechanism and the =6 value are confirmed; that it is the
dominant drop source should be verified by instrumenting the burst.)*

### 4.2 Controller pacing jitter → all-scope reset
Any >20 ms drift re-anchors the epoch (`hype_controller.py:634`) with `flags=0`. The slave then
sees a >20 ms deadline jump and does a **full `jb.reset()`** (`net_rx.cpp:100-103`) → ~1 s
rebuffer **on all four scopes simultaneously**. The single-threaded `stream_loop` shares the
interpreter (GIL) with the `ThreadingHTTPServer` (`hype_controller.py:711-713`, polled at 1 Hz
per open browser) and runs pure-Python trig for 240 frames every 5 ms. On a Linux SBC, >20 ms
stalls under poll load are routine — a drop source **independent of the AP quirk**.
**Fix (controller):** run the HTTP server in a separate process, or pin the pacing loop.
**Fix (slave):** on a 20–200 ms *forward* delta, bounded `push_hold` to bridge the gap instead
of a full `jb.reset()` — turns a controller hiccup into a sub-frame hold, not a 1 s collapse.
*(Note: the slave detects this itself via the deadline-continuity check; the controller does
not send `HYPE_FLAG_SYNC_PULSE` on re-anchor.)*

### 4.3 Blocking audio socket on the controller
The audio socket is created plain-blocking (`hype_controller.py:580`) while the status socket is
explicitly non-blocking (`:585`). During an AP stall the kernel TX queue backs up and a blocking
`sendto` to slave 1 **stalls the whole 4-slave fan-out loop** (`:642-646`), pushing pacing past
the 20 ms re-anchor threshold → §4.2 on every scope at once. `protocol.md:503` already mandates a
non-blocking socket.
**Fix:** `audio.setblocking(False)` — the existing `except OSError: pass` already swallows the
resulting `BlockingIOError`. One line.

### 4.4 Thin stall margin
`LEAD_US = 350 ms` (`hype_controller.py:50`) is the steady-state buffer depth, but the measured
stall is up to **300 ms** — only ~50 ms of slack before the buffer drains to empty (dot collapse).
The jitter buffer is actually **512 ms** (`JB_CAPACITY_FRAMES = 24576`, `config.h:47`), far larger,
so the lead can be raised for free. *(Latency is irrelevant for scope art — only slave-to-slave
sync matters, and a shared absolute deadline preserves that regardless of lead.)*
**Fix:** raise `LEAD_US` to **~450 ms** (drains to ~150 ms worst-case, refills toward 450, ~60 ms
ring headroom under the 512 ms cap). Also **update `docs/protocol.md §5.2` and its §11 constants
table** — they still say 8192 frames / 170 ms, stale vs the 24576 / 512 ms code.

### 4.5 WiFiUDP copy/alloc churn
Each audio packet through `WiFiUDP.parsePacket()`+`read()` does `malloc(1460)` + a `recvfrom`
copy + `new cbuf` + a second copy + `free` + a third copy on `read()` — **~3 memcpys and 2
heap alloc/free per packet, 200×/s** on a core with no FPU competing with the audio task.
Fixed for free by the AsyncUDP migration in §4.1 (its callback hands you a pointer straight into
the pbuf → one copy into the jitter buffer).

---

## 5. CPU / DSP inefficiency (the "seems inefficient" part)

Real wasted cycles on the FPU-less core. None of these is the drop cause, but they are the
concrete inefficiency and they free the headroom that de-risks the 80 MHz downclock.

### 5.1 Discarded-mic soft-float, every block — *confirmed, the biggest CPU win*
In NETWORK mode `fill_block` calls `mic_in::drain()` → `pump()` every 5 ms block, running the
per-sample soft-float DC-blocker on ~122 mic samples **plus** float IIRs on ~122 vbat + ~122 pot
samples — then `drain()` discards the whole mic ring (`mic_in.cpp:183`). The mic output is thrown
away and vbat/pot only need ~1 Hz freshness (they are oversampled ~120×).
**Cost:** ~8.3 % of one core @160 MHz (~16.7 % @80). **Fix:** in NETWORK/synth modes, drain the
ADC DMA into a scratch buffer *without* the mic float math (still drain — that's the documented
anti-wedge, `renderer_local.cpp:143-146`) and decimate vbat/pot to ~1-in-256. `mode_manager.cpp:131,136`,
`mic_in.cpp:75-110,181-184`.
*Aside: `power-budget.md:161` claims this channel is "decimated ≥1 s"; the code does no such thing
(`SLOW_ALPHA=0.01` at 24.5 kHz ≈ 4 ms). Fixing the decimation makes code and doc agree.*

### 5.2 Per-sample float gain in the audio path — *operator-conditional [corrected]*
`audio_out::write` takes a memcpy fast-path only when `gain ≥ 0.999`, else does a soft-float
multiply on all 480 samples/block (`audio_out.cpp:80-88`).
**[corrected]** This is **not** "always-on": every default lands on the memcpy path (`g_gain`
defaults 1.0, NVS default 1.0, dashboard slider defaults to 100 and only sends `set_gain` on
drag). It activates only on units an operator trims below 100 % to match scope deflection —
common on a multi-scope bench, but opt-in.
**Fix (still worth it, trivial, safe):** store gain as Q15 and use
`scaled[i] = (int16_t)(((int32_t)frames[i] * g_q15) >> 15)`. Removes float from the prio-10
output path; <1 LSB difference. (For `g<0.999`, worst product stays inside int16 — no saturation.)

### 5.3 Oscillators call soft-float `sinf`/`cosf` per sample — *LOCAL/HYBRID only, but heavier than it looks*
`render_circle`/`render_lissajous`/`render_square` each evaluate 2 transcendentals per sample =
**480 `sinf`/`cosf` per block** (`renderer_local.cpp:79-80,111-113,126-127`).
**[corrected]** Soft-float `sinf`/`cosf` on the C3 is **~2000–2400 cyc/call** (Espressif's own
benchmark: `cosf` = 2377 cyc), *not* the ~300 first assumed. So `render_circle` ≈ 480 × ~2000 ≈
**~960k cyc/block vs the 800k budget @160 MHz** — these renderers are **brushing the real-time
budget at 160 MHz and would underrun at 80 MHz.** They apparently run today, so the true per-call
cost is likely lower than 2377 with `-O2`, but this is a **latent correctness flag**, not just
efficiency. `render_square` is the worst offender: it computes a full `sinf` **only to take its
sign** (`renderer_local.cpp:111,113`) — a `phase < PI ? +A : -A` compare gives a bit-identical
square wave for free.
**Important scope note:** these run in **LOCAL / HYBRID / ≥1 s-fallback only** — the steady
NETWORK streaming path never calls them (`mode_manager.cpp:124-136`). So a sine LUT is **~0
thermal benefit during the network show**; its value is (a) making LOCAL/HYBRID safe at 80 MHz,
and (b) enabling the param-synth mode in §6.
**Fix:** shared int16 sine LUT + uint32 phase accumulator (cos = quarter-table offset).

### 5.4 Minor
`update_lpf_coeffs` computes `cosf(w0)` four times where once suffices (`renderer_local.cpp:27-30`;
`b2==b0`, `b1==2*b0`). `render_mic`'s Butterworth is a per-sample soft-float biquad at 48 kHz —
Q15 would cut it, but it is MIC-mode only. No live double-`pump()` bug exists (verified), but it
is guarded only by the `if (pattern != MIC) drain()` check — fragile; a single-owner pump would
be more robust.

---

## 6. The strategic fork: stream parameters, not PCM

The whole hot, drop-prone pipeline exists to deliver **parametric** content the slaves could
synthesize locally. A `HYPE_PARAM` packet `{kind, freq, amp, ratio, phase_epoch}` sent on-change
+ a low-rate keepalive, with the slave computing phase from the **shared master clock** each
block, would:

- cut steady-state parametric traffic ~1000× (order-of-magnitude), **delete the 96 KiB jitter
  buffer and the 350 ms lead**, and make the ath10k stall **invisible** (a lost param packet is
  idempotent; the slave keeps drawing, phase-locked);
- let the radio run **power-save** → move NETWORK draw from ~120–135 mA toward LOCAL's ~50–60 mA
  → the real heat fix;
- make **per-scope-different art free** (each slave its own params at ~zero bandwidth).

**But this is a parallel prototype, not a pre-show change**, because:
- The slave does **not** have a drop-in synth today: there is **no `rose` renderer** in the enum
  (`renderer_local.h:14` = MIC/CIRCLE/LISSAJOUS/RAMP/SQUARE), and the local oscillators
  **free-run their phase** (`renderer_local.cpp:50-51,81`) — they are *not* mutually clock-locked,
  so synth mode needs new clock-anchored phase code.
- `osci-render` (arbitrary vector audio) **cannot** be parameterized and still needs the PCM path.
  The right end-state is a **hybrid**: param-synth for figures, PCM only for osci-render.
- For the PCM path, **keep 48 kHz / 16-bit stereo** — it is the *floor* for smooth scope vectors,
  not a knob to turn down (lower rate = visible polygon chords + flicker). 12-bit wire packing
  saves ~24 % but only on a path that should carry osci-render; solve bandwidth with synth instead.

---

## 7. Prioritized action plan (5 weeks to 2026-08-21: robust + cool + low-risk)

**Tier 1 — one-liners, do now (kills the visible drops):**
1. `LEAD_US` 350 → **450 ms** (controller). 3× stall margin, JB has room, zero cost. §4.4
2. `audio.setblocking(False)` on the controller audio socket. §4.3
3. Move the HTTP server off the pacing thread/process (or pin the pacing loop). §4.2

**Tier 2 — cheap & safe (the real inefficiency + headroom):**
4. NETWORK-mode ADC drain **without** the soft-float DC-blocker; decimate vbat/pot ~1/256 (keep
   draining the DMA). Frees ~8–10 % core. §5.1
5. **Q15 integer gain** in `audio_out`. §5.2
6. `setCpuFrequencyMhz(80)` **after** 4–5 land; DMM-measure 160 vs 80, watch `astk`/underruns.
   Expect **~5 mA**. §3

**Tier 3 — measure-gated:**
7. If underruns persist: **AsyncUDP** for audio RX (bypasses the 6-slot mailbox; the invisible-drop
   fix; also removes the 3 copies + malloc/packet). §4.1, §4.5
8. Slave: soften >20 ms *forward* delta from `jb.reset()` → bounded `push_hold`. §4.2

**Tier 4 — prototype in parallel, NOT before the show:**
9. Sine LUT + phase accumulator (fixes `render_square`'s over-budget soft-float; makes LOCAL/HYBRID
   safe at 80 MHz). §5.3
10. Clock-anchored param-synth mode + add `rose` to the slave — true fix for both symptoms, real
    new code, osci-render still needs PCM. §6

**Also:** add an **uncounted-loss / `seq_gaps` line to the dashboard** so silent mailbox drops
(§4.1) stop being invisible — you cannot tune what you cannot see.

### Guardrails — do NOT do before the show
- Re-enable WiFi power save → reintroduces the ~110 ms ath10k DTIM stall.
- Switch audio to multicast → basic-rate = *worse* airtime + no ACK/retry (`protocol.md §8` is right).
- Shrink the 512 ms jitter buffer → sized for the ath10k quirk; latency is irrelevant here.
- Enable `esp_pm` / auto light-sleep → fights `PS_NONE` and I2S DMA timing.

---

## 8. Method note

Derived from a direct read of the firmware + docs + the installed SDK, then expanded and
**adversarially verified** by an independent multi-agent pass (4 analysis lenses, 25 skeptic
verdicts, 1 completeness critic). 22 of 25 verdicts were "partial" — the *mechanisms* held but
several first-pass **numbers were over-claimed and are corrected here**: the 80 MHz saving
(~5 mA, not 8–15), the soft-float trig cost (~2000 cyc/call, not ~300 → renderers near the RT
budget), and the gain float path (operator-conditional, not always-on). Nothing was refuted;
the load-bearing facts — radio-dominated heat, bench-USB LDO, `recvmbox=6` silent drops,
controller pacing jitter, thin lead margin — all stood.

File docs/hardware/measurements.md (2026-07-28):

# Hardware measurements — fills pcb.md §7

Caliper + bench session with the four real modules on the bench. **No footprint is
drawn from internet dimensions** — every KiCad footprint comes from a number in the
tables below. **This file must be complete before KiCad layout** (pcb.md §9,
DESIGN §12 mechanical item).

Fill `Measured` and `Date` as you go. `Nominal` values are the datasheet/expected
figures from [pcb.md](pcb.md) §2/§7 — flag any measured value that disagrees.

**Bench meter:** ANENG A9002 handheld DMM. Good for steady-state microamp reads
(e.g. deep-sleep current); it **cannot** capture sub-millisecond WiFi-TX current
bursts, so TX-burst current figures stay modeled/estimated, not bench-measured.

**Bench session:** 2026-07-18 (Finn), calipers + ANENG A9002 + loupe. Reference
photos live in [`images/`](images/) and are embedded per module below.

**Photogrammetry session:** 2026-07-26. Every socket position the carrier draws now
comes from a calibrated two-sided photo of the real module, not from calipers and not
from a datasheet — see [§ Photogrammetry](#photogrammetry-hwpin_locs--the-numbers-the-carrier-actually-uses)
below. Where the two disagree, the photogrammetry wins and the caliper row is marked
_superseded_.

---

## ⚠️ Findings that disagree with nominal — READ BEFORE KiCad layout

These change footprints / floorplan and must be reconciled into `pcb.md` (and DESIGN
where noted) **before** layout starts:

1. **PCM5102A is ~31.8 mm long, not ~27 mm** (+~5 mm). The `~70 × 50 mm` floorplan
   (pcb.md §1/§6) must be re-checked against a 32 mm module.
2. **PCM5102A analog end is a 1×9 header, not a 1×3 `L G R`.** Real silk (jack→digital):
   `LROUT AGND ROUT AGND A3V3 FMT XSMT DEMP FLT`. Our analog taps become
   **X = LROUT, Y = ROUT, ground = AGND**. pcb.md §1/§2 socket **J3 = 1×3 female `L G R`
   is wrong** → it must become a 1×9 socket (or a partial socket over the LROUT/AGND/ROUT
   pins). This is the biggest change.
3. **PCM5102A has an on-board output reconstruction filter** (`471` ≈ 470 Ω series parts +
   caps near the outputs), not bare DAC pins. This is a filter, **not** DC-blocking — the
   output stays ground-centered (DESIGN §5 assumption holds). Consequence is only for R10/R11:
   with ~470 Ω already in series, **fit 0 Ω links** — settled 2026-07-28 (pcb.md §10 Q2), and
   *not* on the Phase-4 bench ramp, which cannot resolve it: 100 Ω against 470 Ω is 0.01 % of
   amplitude and ≲0.07° of phase at 10 kHz, equally on both channels.
4. **SuperMini LDO marking reads `S2LC`, not the expected `S2QB`.** Decode/confirm the
   current rating (need ≥ ~0.35 A for WiFi TX peaks) before trusting it. Not the feared
   250 mA `LLVB`, but not the verified 500 mA `S2QB` either.
5. **Q10 RESOLVED:** SuperMini USB-C `VBUS` **is** directly tied to the `5V` pin
   (meter-confirmed). ⇒ the "never plug USB-C while the battery switch is ON" rule is
   **mandatory** (USB would back-feed the cell). Close Q10.

6. **TP4056 output pads are NOT on a 2.54 grid** (2026-07-26 photogrammetry). They are
   two pairs — `OUT−`/`B−` at 3.526 mm and `B+`/`OUT+` at 3.106 mm — with a 7.43 mm
   gutter between them, spanning nearly the whole 17.3 mm edge. No stock 1×2 socket
   mates with that, so J5/J6 became generated footprints at the measured pitches.
7. **PCM5102A row-to-row offset was 4.06 mm out** (2026-07-26 photogrammetry). The 1×6
   I2S column is not collinear with the 1×9 row and sits past its FLT end; see the
   PCM5102A table below. This is the socket the v1.0 board got wrong.

Non-blocking notes: SuperMini PCB width measures 17.8 mm (nominal 18 — fine). TP4056
charger IC is marked `CSM4056T` (a TP4056 equivalent) with `8205LA` (FS8205) + DW01-type
protection — behaves per spec (continuity checks pass).

---

## ESP32-C3 SuperMini

<p>
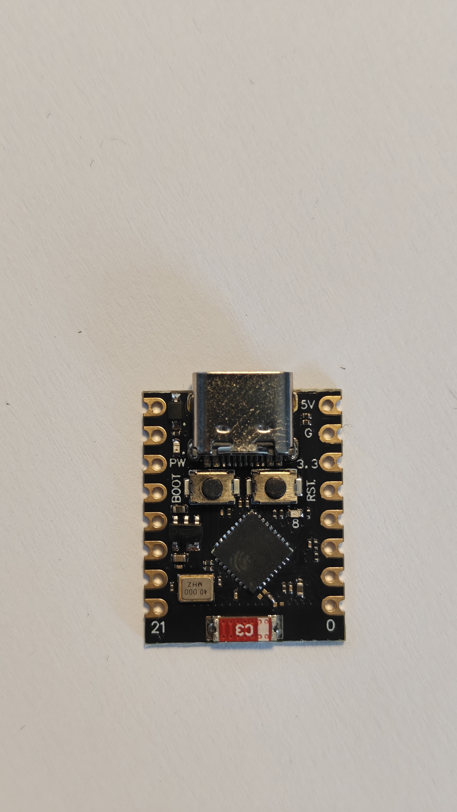
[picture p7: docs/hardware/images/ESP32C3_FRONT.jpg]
ESP32-C3 SuperMini — front (component/USB-C side)

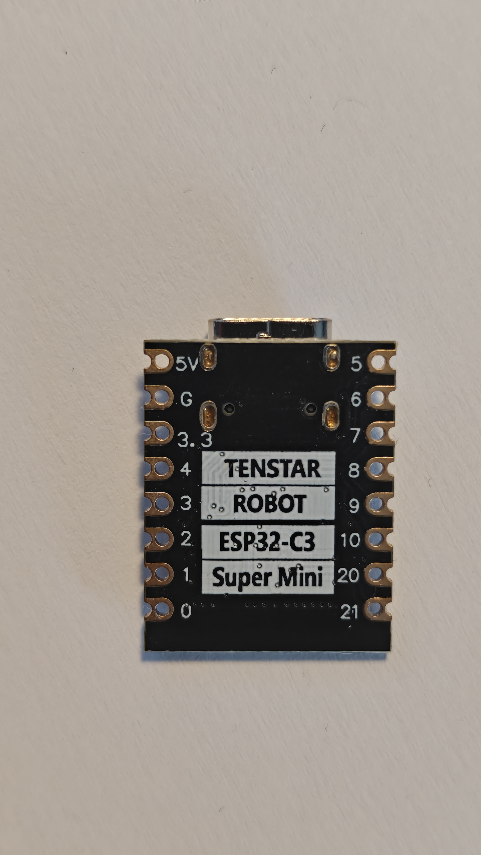
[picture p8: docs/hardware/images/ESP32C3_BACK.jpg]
ESP32-C3 SuperMini — back (silk pinout, TENSTAR ROBOT)

</p>

Photos: [front](images/ESP32C3_FRONT.jpg) · [back](images/ESP32C3_BACK.jpg)

| Measurement | Nominal | Measured | Date |
|---|---|---|---|
| Board outline L × W | 22.5 × 18 mm | **22.5 × 17.8 mm** (PCB); **24 mm** L incl. USB-C overhang. Width 17.8 vs 18 — OK | 2026-07-18 |
| Pin-row pitch | 2.54 mm | 2.54 (0.1″ header) ✓ | 2026-07-18 |
| Pins per row | 8 | 8 ✓ | 2026-07-18 |
| Row-to-row spacing | 15.24 mm | ~15.2 (reads 15.24) ✓ | 2026-07-18 |
| First-pin offset from each board edge | — | **1.3 mm** on USB-C end, **2.8 mm** on antenna end (edge → inside of pin hole) | 2026-07-18 |
| Antenna end (which end) + overhang of antenna region from last pin row | — | **Non-USB-C end.** Integrated PCB antenna (silk `C3`), **flush with board edge — 0 mm overhang** (copper keep-out, not a mechanical overhang) | 2026-07-18 |
| USB-C end (which end) + connector overhang past board edge | — | **Opposite the antenna.** Connector overhangs **~1.5 mm** past the board edge | 2026-07-18 |
| Pin silk order of both rows vs pcb.md §2 table | matches §2 | ✓ **matches §2.** Back silk: L col `5V G 3.3 4 3 2 1 0`, R col `5 6 7 8 9 10 20 21`. Board marked "TENSTAR ROBOT ESP32-C3 Super Mini" | 2026-07-18 |
| Bottom-side component height (socket clearance) | ≤ ~8.5 mm | **~8.3 mm** ✓ (within 8.5; socket clearance OK but tight) | 2026-07-18 |
| LDO marking (SOT-23-5, loupe) | ME6211C33 ("S2QB"); beware "LLVB" = 250 mA | ⚠️ **reads `S2LC`** — not `S2QB`, not `LLVB`. Decode + confirm ≥0.35 A rating before trusting | 2026-07-18 |
| USB-C VBUS ↔ 5 V pin beep test (direct tie?) — Q10 | expected tied | ✅ **CONFIRMED tied** (meter continuity). ⇒ USB back-feeds the cell — the "no USB while batt switch ON" rule is mandatory. **Closes Q10.** | 2026-07-18 |

## GY-PCM5102A (purple)

<p>
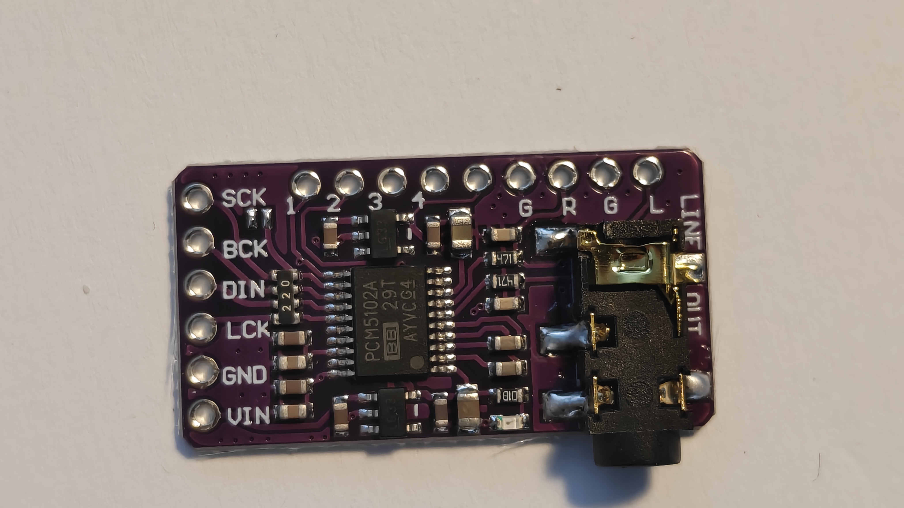
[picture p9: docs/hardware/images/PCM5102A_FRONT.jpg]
GY-PCM5102A — front (PCM5102A IC, 6-pin I2S header, 9-pin analog/control header, LINE OUT jack)

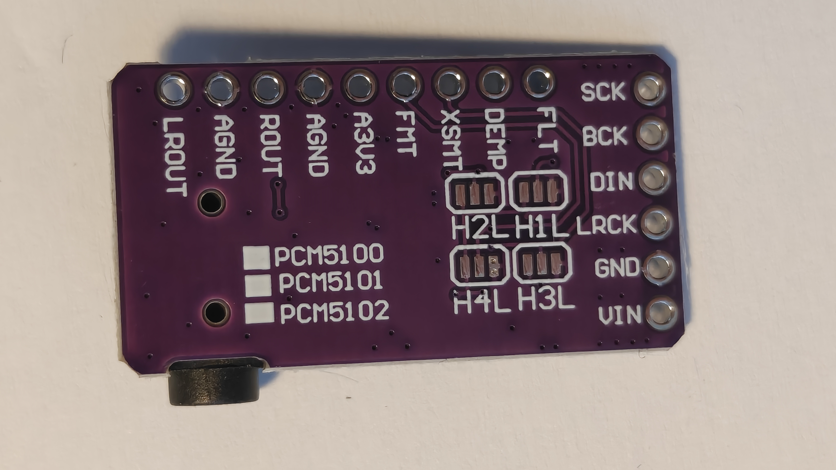
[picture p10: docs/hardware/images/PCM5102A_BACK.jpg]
GY-PCM5102A — back (silk: LROUT AGND ROUT AGND A3V3 FMT XSMT DEMP FLT; H1L–H4L config jumpers)

</p>

Photos: [front](images/PCM5102A_FRONT.jpg) · [back](images/PCM5102A_BACK.jpg)

| Measurement | Nominal | Measured | Date |
|---|---|---|---|
| Board outline L × W | ~27 × 17 mm | ⚠️ **~31.8 × 17 mm** — module is ~5 mm LONGER than nominal. Re-check the 70×50 floorplan | 2026-07-18 |
| 6-pin header pitch | 2.54 mm | 2.54 (0.1″ header) ✓ | 2026-07-18 |
| 6-pin header offset | — | on the short (digital) edge; single 1×6 row | 2026-07-18 |
| 6-pin header order silk | SCK BCK DIN LCK GND VIN | ✅ **`SCK BCK DIN LCK GND VIN`** (top→bottom on the short edge) — matches | 2026-07-18 |
| ~~3-pin analog header position~~ → **actual: 1×9 analog/control header** | (assumed 1×3 `L G R`) | ⚠️ **NOT a 3-pin header.** It is a **1×9 header along the long edge.** Analog out lives here: use **X=LROUT, Y=ROUT, gnd=AGND.** → pcb.md **J3 must be 1×9, not 1×3** | 2026-07-18 |
| 9-pin header order silk | (n/a) | Back silk, jack-end → digital-end: **`LROUT AGND ROUT AGND A3V3 FMT XSMT DEMP FLT`** (front abbreviates the analog end `… G R G L`) | 2026-07-18 |
| 9-pin header distance from 6-pin row | — | ~~PROVISIONAL (phone-measured): 1×6 row axis +2.54 mm from FLT, SCK collinear with the 1×9 row~~ **SUPERSEDED — the guess was 4.06 mm out.** Photogrammetry: SCK (J2 pin 1) sits **26.917 mm west and 0.583 mm south** of LROUT (J3 pin 1), i.e. the 1×6 column is *past* the FLT end of the 1×9 row and **not** collinear with it. Worst pin 0.180 mm off an ideal 2.54 mm socket. See §Photogrammetry | 2026-07-26 |
| 3.5 mm jack overhang | may hang off carrier edge | **~1.6 mm** (jack makes total 18.6 vs 17 mm board) — hangs off edge, fine | 2026-07-18 |
| Solder-bridge state (DESIGN §5) | 1=L, 2=L, 3=H, 4=L | Pads present on back: **`H1L H2L H3L H4L`** (+ `PCM5100/5101/5102` selector). State not readable from photo — **verify by continuity** against 1=L,2=L,3=H,4=L | _verify_ |
| Series R/filter on L/R outputs? (trace or measure) | expect none (fit 0 Ω if present) | ⚠️ **Filter PRESENT** — `471` (≈470 Ω) series parts + caps sit between the DAC and the output pins/jack. Confirm whether LROUT/ROUT are pre- or post-filter. **R10/R11 resolved 2026-07-28: fit 0 Ω links** (pcb.md §10 Q2) — the module's 470 Ω already does the isolating | 2026-07-18 |

## MAX4466

<p>
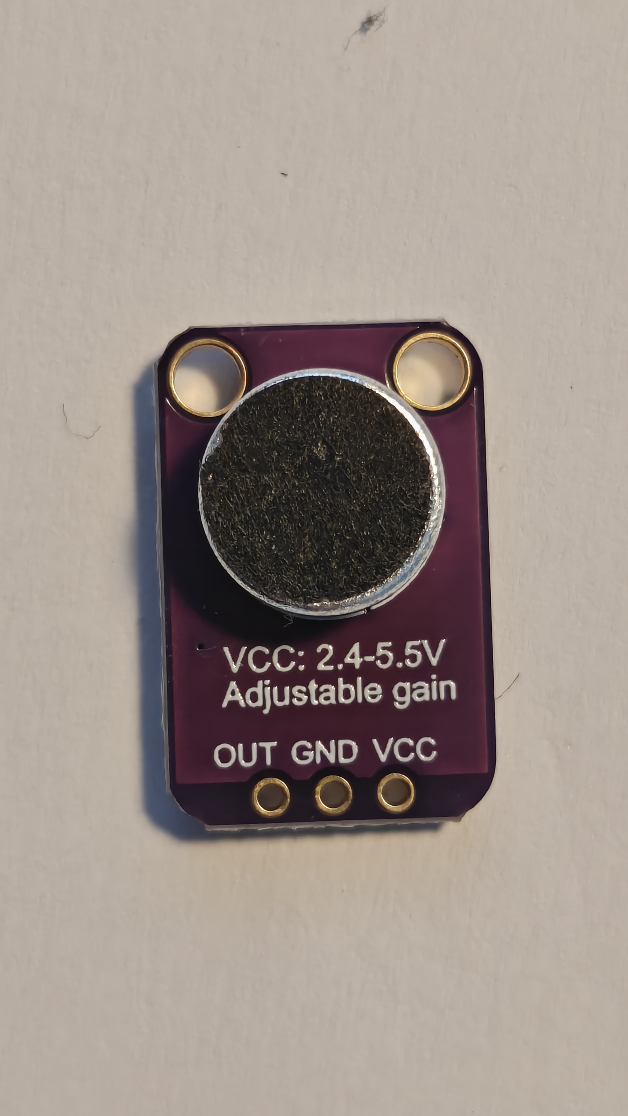
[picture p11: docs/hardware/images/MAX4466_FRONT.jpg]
MAX4466 — front (electret capsule, 'VCC 2.4-5.5V Adjustable gain', silk OUT GND VCC)

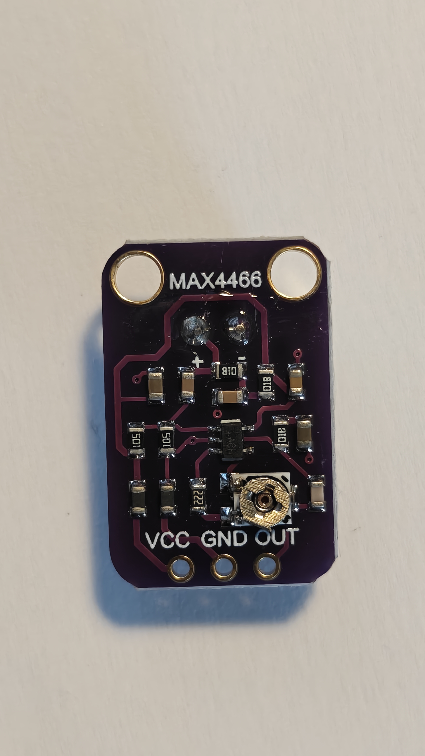
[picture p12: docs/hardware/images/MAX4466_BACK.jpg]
MAX4466 — back (op-amp, gain trimmer, silk VCC GND OUT)

</p>

Photos: [front](images/MAX4466_FRONT.jpg) · [back](images/MAX4466_BACK.jpg)

| Measurement | Nominal | Measured | Date |
|---|---|---|---|
| Board outline L × W | ~20 × 13 mm | **20.8 × 13.5 mm** ✓ | 2026-07-18 |
| Header pitch | 2.54 mm | 2.54 (3-pin 0.1″) ✓ | 2026-07-18 |
| Header offset | — | 3-pin row centered on one short edge | 2026-07-18 |
| Pin order silk (clones differ) | VCC GND OUT | ✅ **`VCC GND OUT`** reading from the back (op-amp) side; front (capsule side) silk mirrors it as `OUT GND VCC`. Matches §2 J4 — wire the pigtail by **back** silk | 2026-07-18 |
| Capsule diameter + position (silk aperture circle) | — | electret capsule **~9.7 mm** dia, top-center on the capsule (front) side; 2× mounting holes at top corners | 2026-07-18 |
| Gain trimmer position (reachable when socketed?) | — | multiturn trimpot on the **back** (component) side, bottom-center → **screwdriver-reachable on the ~10 cm pigtail** ✓ | 2026-07-18 |

## TP4056 (USB-C, blue — CSM4056T + DW01-type + FS8205)

<p>
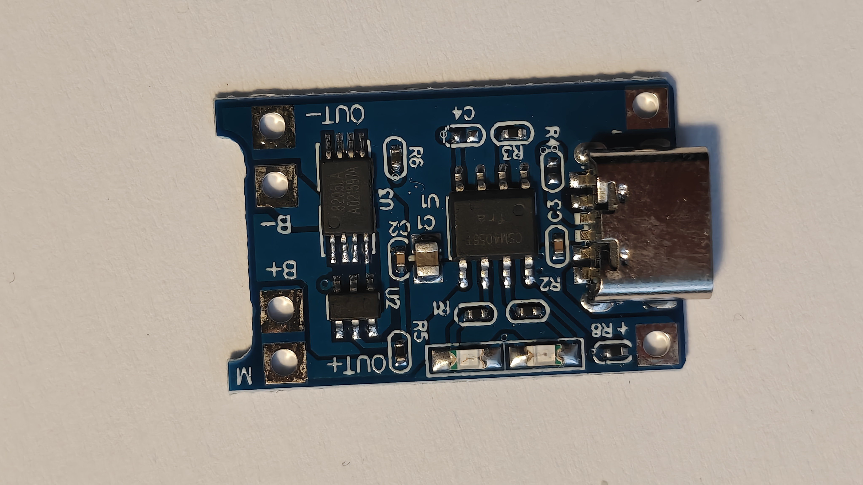
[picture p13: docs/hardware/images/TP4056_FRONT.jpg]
TP4056 — front (USB-C, CSM4056T charger, 8205LA FET, B+ B- OUT+ OUT- pads)

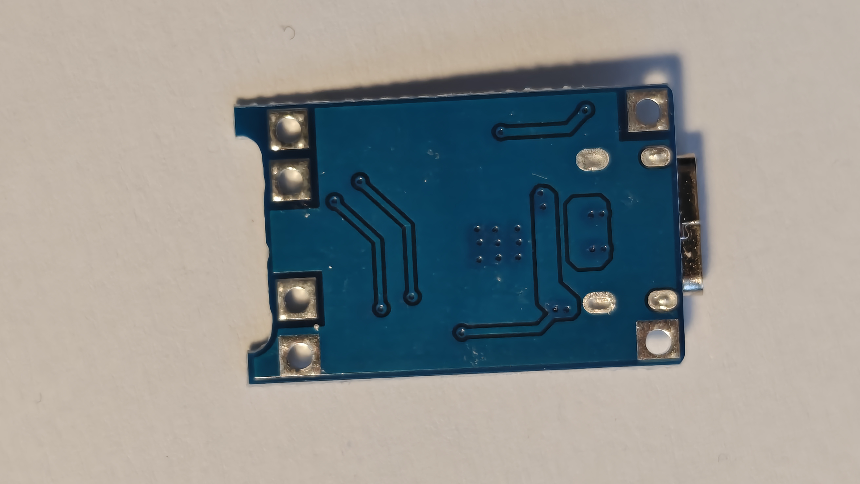
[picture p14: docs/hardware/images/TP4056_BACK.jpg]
TP4056 — back (traces, mounting pads)

</p>

Photos: [front](images/TP4056_FRONT.jpg) · [back](images/TP4056_BACK.jpg)

| Measurement | Nominal | Measured | Date |
|---|---|---|---|
| Board outline L × W | ~26 × 17 mm | **26.9 × 17.3 mm** — but see §Nubs: 26.9 is the **nub-inclusive** length. The main body is **25.2 mm**; two depanelization tabs at the OUT−/OUT+ corners add 1.6 mm | 2026-07-18, refined 2026-07-27 |
| B+, B−, OUT+, OUT− pad positions + drill | ~2.54 grid (usually *almost*) | Order confirmed: THT pads on the left short edge, top→bottom **`OUT− · B− · B+ · OUT+`** (+ `M` mounting mark). ⚠️ **"~2.54 grid" is WRONG** — photogrammetry gives **0 / 3.526 / 10.960 / 14.066 mm**: two pairs (3.53 and 3.11 pitch) with a 7.43 mm gutter, spanning nearly the whole 17.3 mm edge. Nothing on a 2.54 grid mates with it. See §Photogrammetry. ⚠️ **Hole ⌀ revised 2026-07-27: ~1.5 mm, not 2.0** (calipers give 1.43; the photogrammetry's 2.0 "nominal" was pulled up by a single bad pick reading 2.60 against 1.65 / 1.61 / 1.41 for the other three). Slack per pin is therefore **~0.45 mm with 0.5 mm machined round pins**, not ±0.55 — still clear of the 0.25 mm gate | 2026-07-26 |
| IN+ / IN− pads: drilled or SMD-only? position | — | **drilled** — ~2.8 mm bare-copper squares on **1.68 mm** plated holes, one at each USB-C-end corner, in line with OUT+ (`+` silk, beside `R8`) and OUT−. **21.65 mm** from the output row. These are now the carrier's **second mount row** (J9/J10), not just a sense tap — see §The second mount row | 2026-07-18, positioned 2026-07-28 |
| USB connector type (micro-B vs USB-C) + overhang | — | **USB-C**; overhang **1.4 mm** (28.3 − 26.9) | 2026-07-18 |
| RPROG value (read resistor / marking) | 1.2 kΩ → 1 A default | **measured 1.19 kΩ** (no legible marking) ⇒ ~1 A default ✓ | 2026-07-18 |
| B+ ↔ OUT+ continuity | 0 Ω (same copper) | ✅ **continuous** (0 Ω) | 2026-07-18 |
| B− ↔ OUT− non-continuity | open (protection FET) | ✅ **open** (protection FET present) | 2026-07-18 |

_ICs: main charger marked `CSM4056T` (TP4056-equivalent), `8205LA` = FS8205 dual FET,
`U2` = DW01-type protection. Behaves per the nominal TP4056+DW01+FS8205 spec._

### Nubs, and the pad-row → edge offset — ✅ CLOSED 2026-07-27

**This was the last item gating the gerber plot.** It is closed, the module seats as drawn,
and **nothing in the layout moves.**

The module's west edge (the one behind the output pads) **is not straight**: two
depanelization tabs protrude at the OUT− and OUT+ corners. In
[`images/TP4056_FRONT.jpg`](images/TP4056_FRONT.jpg) they are bare soldermask — no copper,
no silk, no component, no trace running out to them. **They get filed flush at assembly**
(see the reduction below for why that is not cosmetic).

Calipers, module in hand, all distances to the **near rim** of the hole (rim, not centre —
that is what a caliper jaw can actually reach):

| # | From → to | Measured |
|---|---|---|
| A | north long edge → OUT− near rim | **1.2 mm** |
| B | OUT+ near rim → south long edge | **1.1 mm** |
| C1 | **nub** west edge → OUT−/OUT+ near rim | **2.64 mm** |
| C2 | **main** west edge → B−/B+ near rim | **1.0 mm** |
| D1 | overall length, **with** nubs | **26.8 mm** |
| D2 | overall length, **without** nubs | **25.2 mm** |
| E | OUT− ↔ OUT+, nearest rims | **12.4 mm** |
| F | OUT− ↔ OUT+, farthest rims | **15.25 mm** |
| — | board width, edge to edge | **17.3 mm** |

**Reduction 1 — the N/S seat, which is what the gate asked for.** The hole radius is
unknown, but it *cancels*, because A and B are both measured to the near rim:

```
column centre from north edge = ( (A + r) + (17.3 − B − r) ) / 2
                              = (1.2 + 16.2) / 2 = 8.70 mm       <- r cancels
half width                    = 17.3 / 2         = 8.65 mm
                                        => column sits 0.05 mm SOUTH of body centre
```

The board model puts it **0.12 mm south of centre** (1.81 / 14.066 / 1.57). **Δ = 0.07 mm
against a 0.25 mm gate.** No shift toward D1 (0.31 mm north), none toward the control row.

**Reduction 2 — the nubs are the 26.9-vs-25.75 contradiction.** D1 = 26.8 ≈ the 2026-07-18
caliper 26.9 (which included the tabs); D2 = 25.2 is the body. The photogrammetry's 25.75
was hand-clicked corners **averaging across a stepped edge**, which is why it agreed with
neither — exactly the failure `hw/pin_locs/TP4056.txt` warns about. Filed vs not:

| | west edge lands at | clearance to RV1 body (`x 32.05…41.55, y 37.0…50.0`) |
|---|---|---|
| **filed flush** | x ≈ 43.9 — within **0.15 mm** of the modelled 43.91, on any assumed hole ⌀ | **2.4 mm** |
| unfiled | x ≈ 42.2 | **~0.7 mm** |

The SW nub and the pot overlap in Y, so unfiled leaves 0.7 mm between a PCB corner ~4 mm up
and an 11.3 mm-tall pot body. Not a collision — but filing costs 30 s per module and makes
the as-built match the model.

**Reduction 3 — the east end moved ~0.8 mm west.** `east edge = column + D2 − (1.0 + r)
≈ column + 23.3` against the modelled `+24.07`, so the body ends at **x ≈ 69.0–69.2** with
~1 mm of board left, not 0.2 mm. The USB-C jack overhangs the body by 1.4 mm, so its face
sits only **~0.5 mm proud of the carrier's east edge** instead of ~1.2 mm. More clearance,
not less — but it is an **enclosure input**: the charge-port opening must clear a USB-C
**plug overmold** reaching a nearly-flush jack, so that wall wants a local relief or a
recessed cutout.

**Reduction 4 — the span disagrees by ~0.3 mm, and it does not matter.** E/F give a pad span
of **13.83 mm** and hole ⌀ **1.43 mm**; A/B/width independently give span ≈ 13.6; the
photogrammetry says 14.066. Both caliper routes land short in the same direction, which is
predictable: the photogrammetry's **scale came from a caliper reading of this same 17.30 mm
width**, so a ~1.7 % scale error is precisely what its warning block says it cannot separate
from the result. Consequence at assembly: with ~1.5 mm holes and ~0.5 mm machined round pins
there is ~0.45 mm of radial slack per hole, and a 0.27 mm span error puts the two end pins
0.13 mm off centre. It drops on. **Assembly order matters though — see [pcb.md](pcb.md) §5:
pins into the module first, then onto the carrier.**

**Why the model is not being edited.** Every delta is either inside the gate (N/S, 0.07 mm)
or in the direction of *more* clearance (east, 0.8 mm). `TP4056_OUTLINE` feeds
`audit_board.py`'s under-module checks and `gen_board.py`'s silk/keep-out placement, so
editing `hw/pin_locs/TP4056.json` would force a full `gen_board.py` + `route.py` re-run and a
`ROUTE_SEED` re-sweep (pcb.md §9 — a stale seed fails silently as a severed ground pour) to
buy nothing. The measured deltas are recorded here instead.
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

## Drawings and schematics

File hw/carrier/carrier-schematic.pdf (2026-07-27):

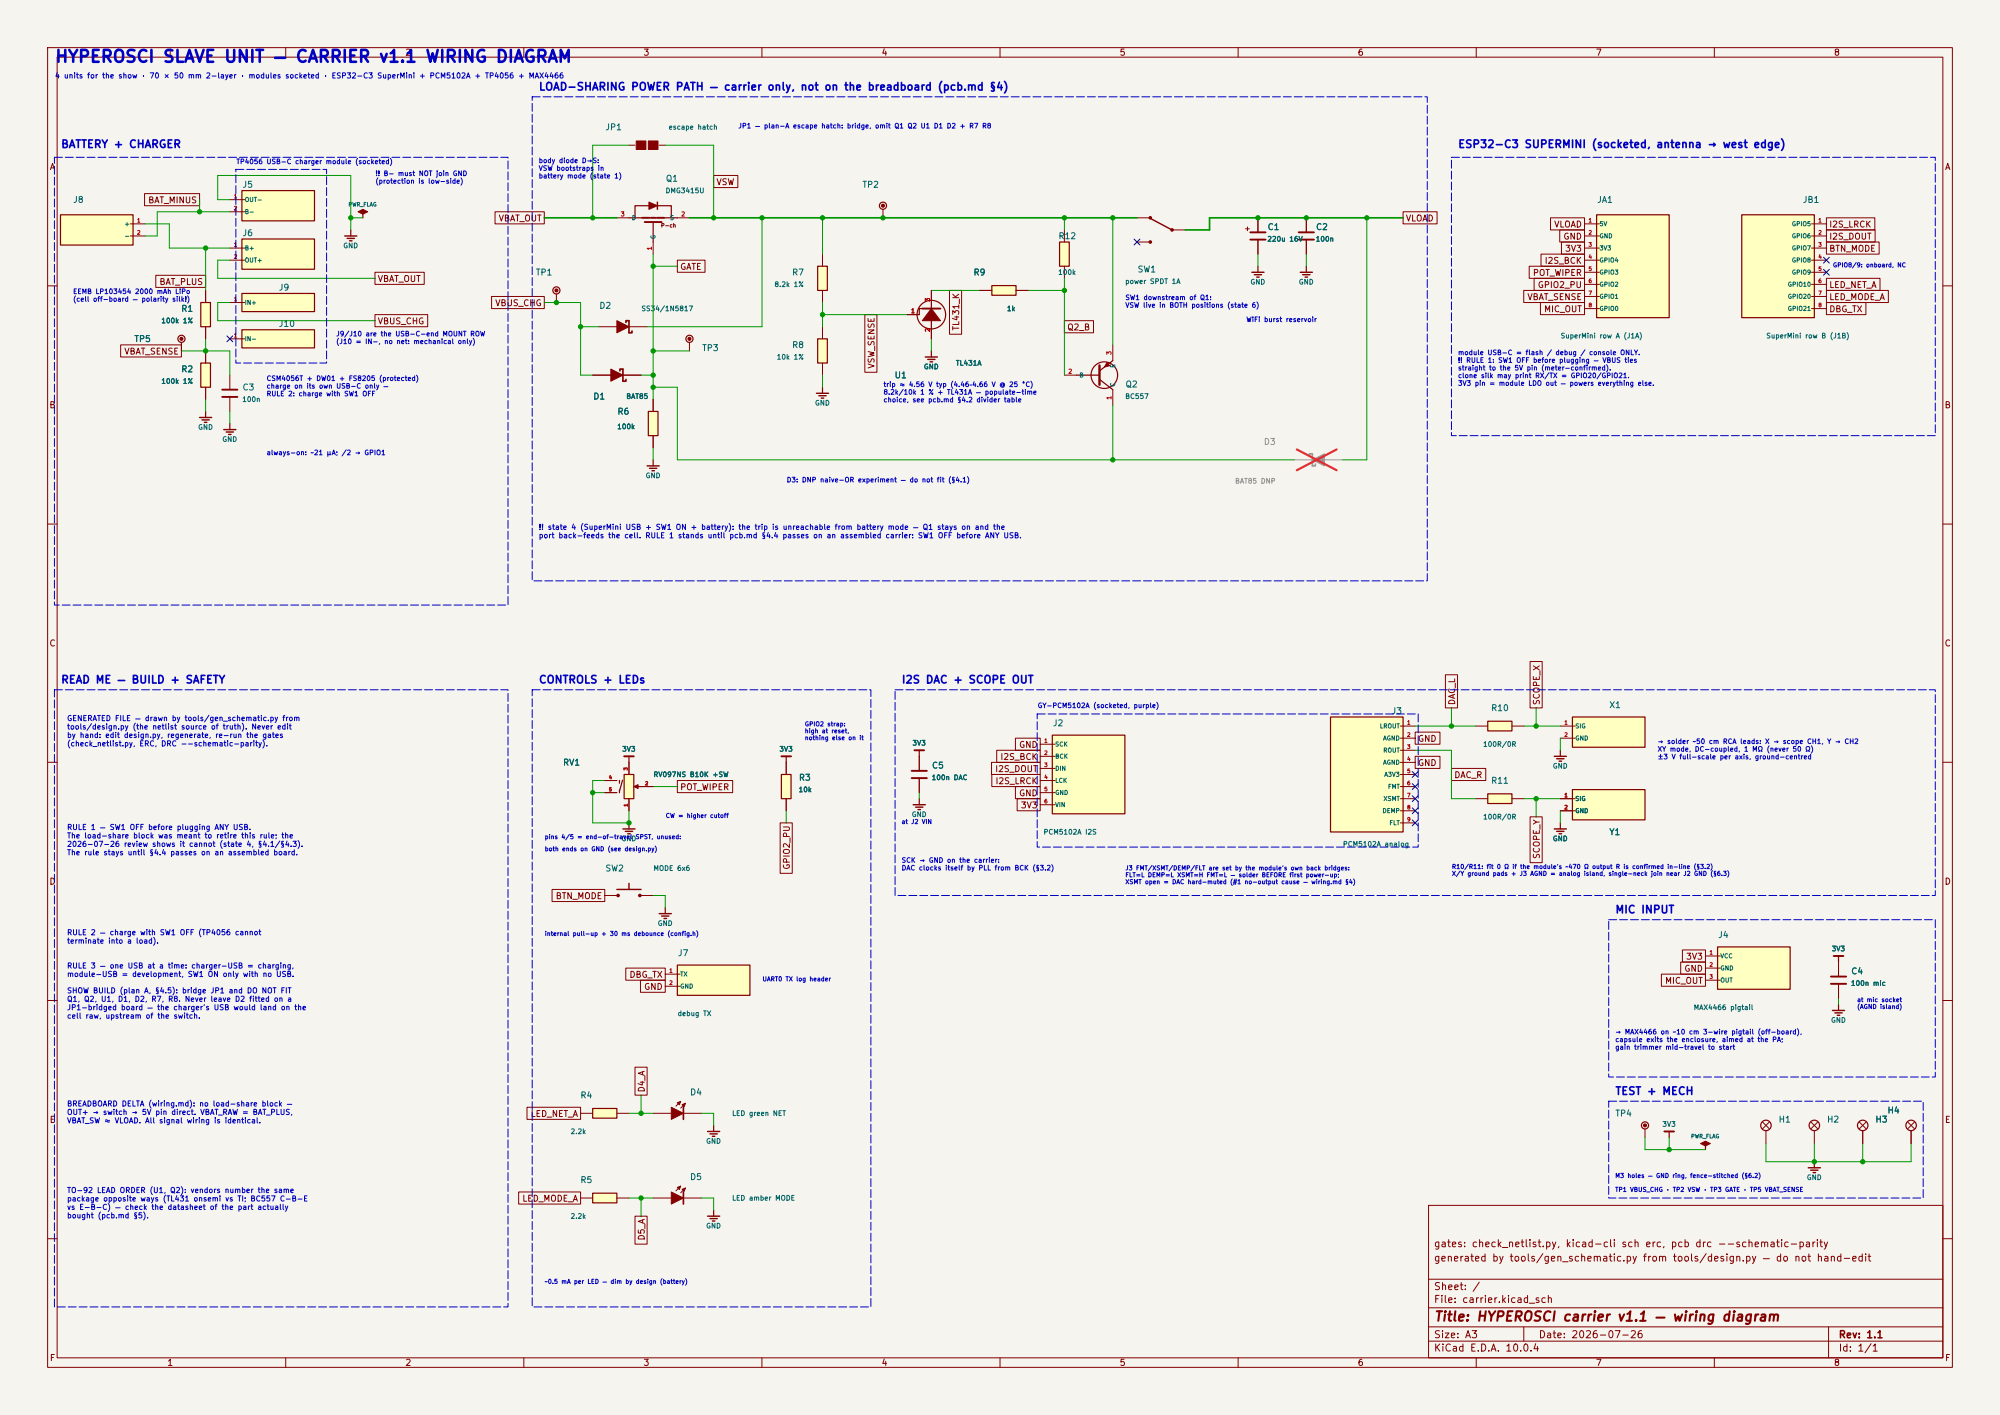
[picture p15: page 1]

HYPEROSCI SLAVE UNIT — CARRIER v1.1 WIRING DIAGRAM

4 units for the show · 70 × 50 mm 2-layer · modules socketed · ESP32-C3 SuperMini + PCM5102A + TP4056 + MAX4466

JP1 — plan-A escape hatch: bridge, omit Q1 Q2 U1 D1 D2 + R7 R8

GPIO8/9: onboard, NC BATTERY + CHARGER

TP4056 USB-C charger module (socketed)

!! B− must NOT join GND
(protection is low-side)

EEMB LP103454 2000 mAh LiPo
(cell off-board — polarity silk!)

J9/J10 are the USB-C-end MOUNT ROW
(J10 = IN-, no net: mechanical only)

module USB-C = flash / debug / console ONLY.
!! RULE 1: SW1 OFF before plugging — VBUS ties
straight to the 5V pin (meter-confirmed). clone silk may print RX/TX = GPIO20/GPIO21. 3V3 pin = module LDO out — powers everything else.

CSM4056T + DW01 + FS8205 (protected) charge on its own USB-C only —

trip ≈ 4.56 V typ (4.46–4.66 V @ 25 °C) 8.2k/10k 1 % + TL431A — populate-time

RULE 2: charge with SW1 OFF

choice, see pcb.md §4.2 divider table D3: DNP naive-OR experiment — do not fit (§4.1)

!! state 4 (SuperMini USB + SW1 ON + battery): the trip is unreachable from battery mode — Q1 stays on and the port back-feeds the cell. RULE 1 stands until pcb.md §4.4 passes on an assembled carrier: SW1 OFF before ANY USB. I2S DAC + SCOPE OUT

3V3 READ ME — BUILD + SAFETY

GPIO2 strap: high at reset, nothing else on it CW = higher cutoff CONTROLS + LEDs

GY-PCM5102A (socketed, purple) J3 FMT/XSMT/DEMP/FLT are set by the module's own back bridges: FLT=L DEMP=L XSMT=H FMT=L — solder BEFORE first power-up; XSMT open = DAC hard-muted (#1 no-output cause — wiring.md §4)

GENERATED FILE — drawn by tools/gen_schematic.py from
tools/design.py (the netlist source of truth). Never edit by hand: edit design.py, regenerate, re-run the gates

(check_netlist.py, ERC, DRC --schematic-parity). RULE 1 — SW1 OFF before plugging ANY USB. The load-share block was meant to retire this rule; the 2026-07-26 review shows it cannot (state 4, §4.1/§4.3). The rule stays until §4.4 passes on an assembled board. SHOW BUILD (plan A, §4.5): bridge JP1 and DO NOT FIT Q1, Q2, U1, D1, D2, R7, R8. Never leave D2 fitted on a

→ solder ~50 cm RCA leads: X → scope CH1, Y → CH2
XY mode, DC-coupled, 1 MΩ (never 50 Ω) ±3 V full-scale per axis, ground-centred

internal pull-up + 30 ms debounce (config.h) both ends on GND (see design.py)

R10/R11: fit 0 Ω if the module's ~470 Ω output R is confirmed in-line (§3.2) X/Y ground pads + J3 AGND = analog island, single-neck join near J2 GND (§6.3)

RULE 2 — charge with SW1 OFF (TP4056 cannot

RULE 3 — one USB at a time: charger-USB = charging, module-USB = development, SW1 ON only with no USB.

at mic socket (AGND island)

JP1-bridged board — the charger's USB would land on the
cell raw, upstream of the switch. TO-92 LEAD ORDER (U1, Q2): vendors number the same package opposite ways (TL431 onsemi vs TI; BC557 C-B-E

BREADBOARD DELTA (wiring.md): no load-share block —
OUT+ → switch → 5V pin direct. VBAT_RAW = BAT_PLUS, VBAT_SW ≈ VLOAD. All signal wiring is identical.

LED green NET GND D5

LED amber MODE GND

TP1 VBUS_CHG · TP2 VSW · TP3 GATE · TP5 VBAT_SENSE M3 holes — GND ring, fence-stitched (§6.2)

vs E-B-C) — check the datasheet of the part actually

generated by tools/gen_schematic.py from tools/design.py — do not hand-edit

Sheet: /
File: carrier.kicad_sch
Title: HYPEROSCI carrier v1.1 — wiring diagram

Size: A3 | Rev: 1.1
KiCad E.D.A. 10.0.4 | Id: 1/1 | F Date: 2026-07-26

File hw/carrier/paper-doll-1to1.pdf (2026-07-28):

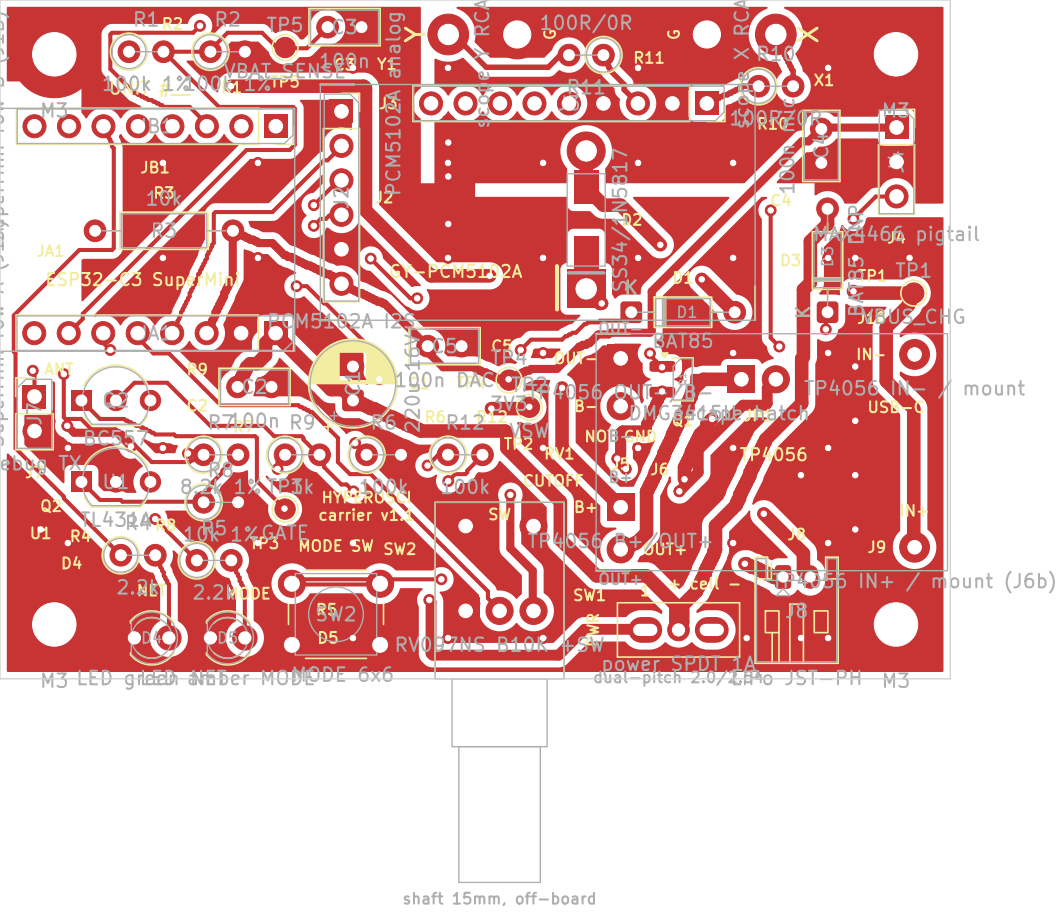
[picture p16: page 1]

C5 | OUT- | USB-C

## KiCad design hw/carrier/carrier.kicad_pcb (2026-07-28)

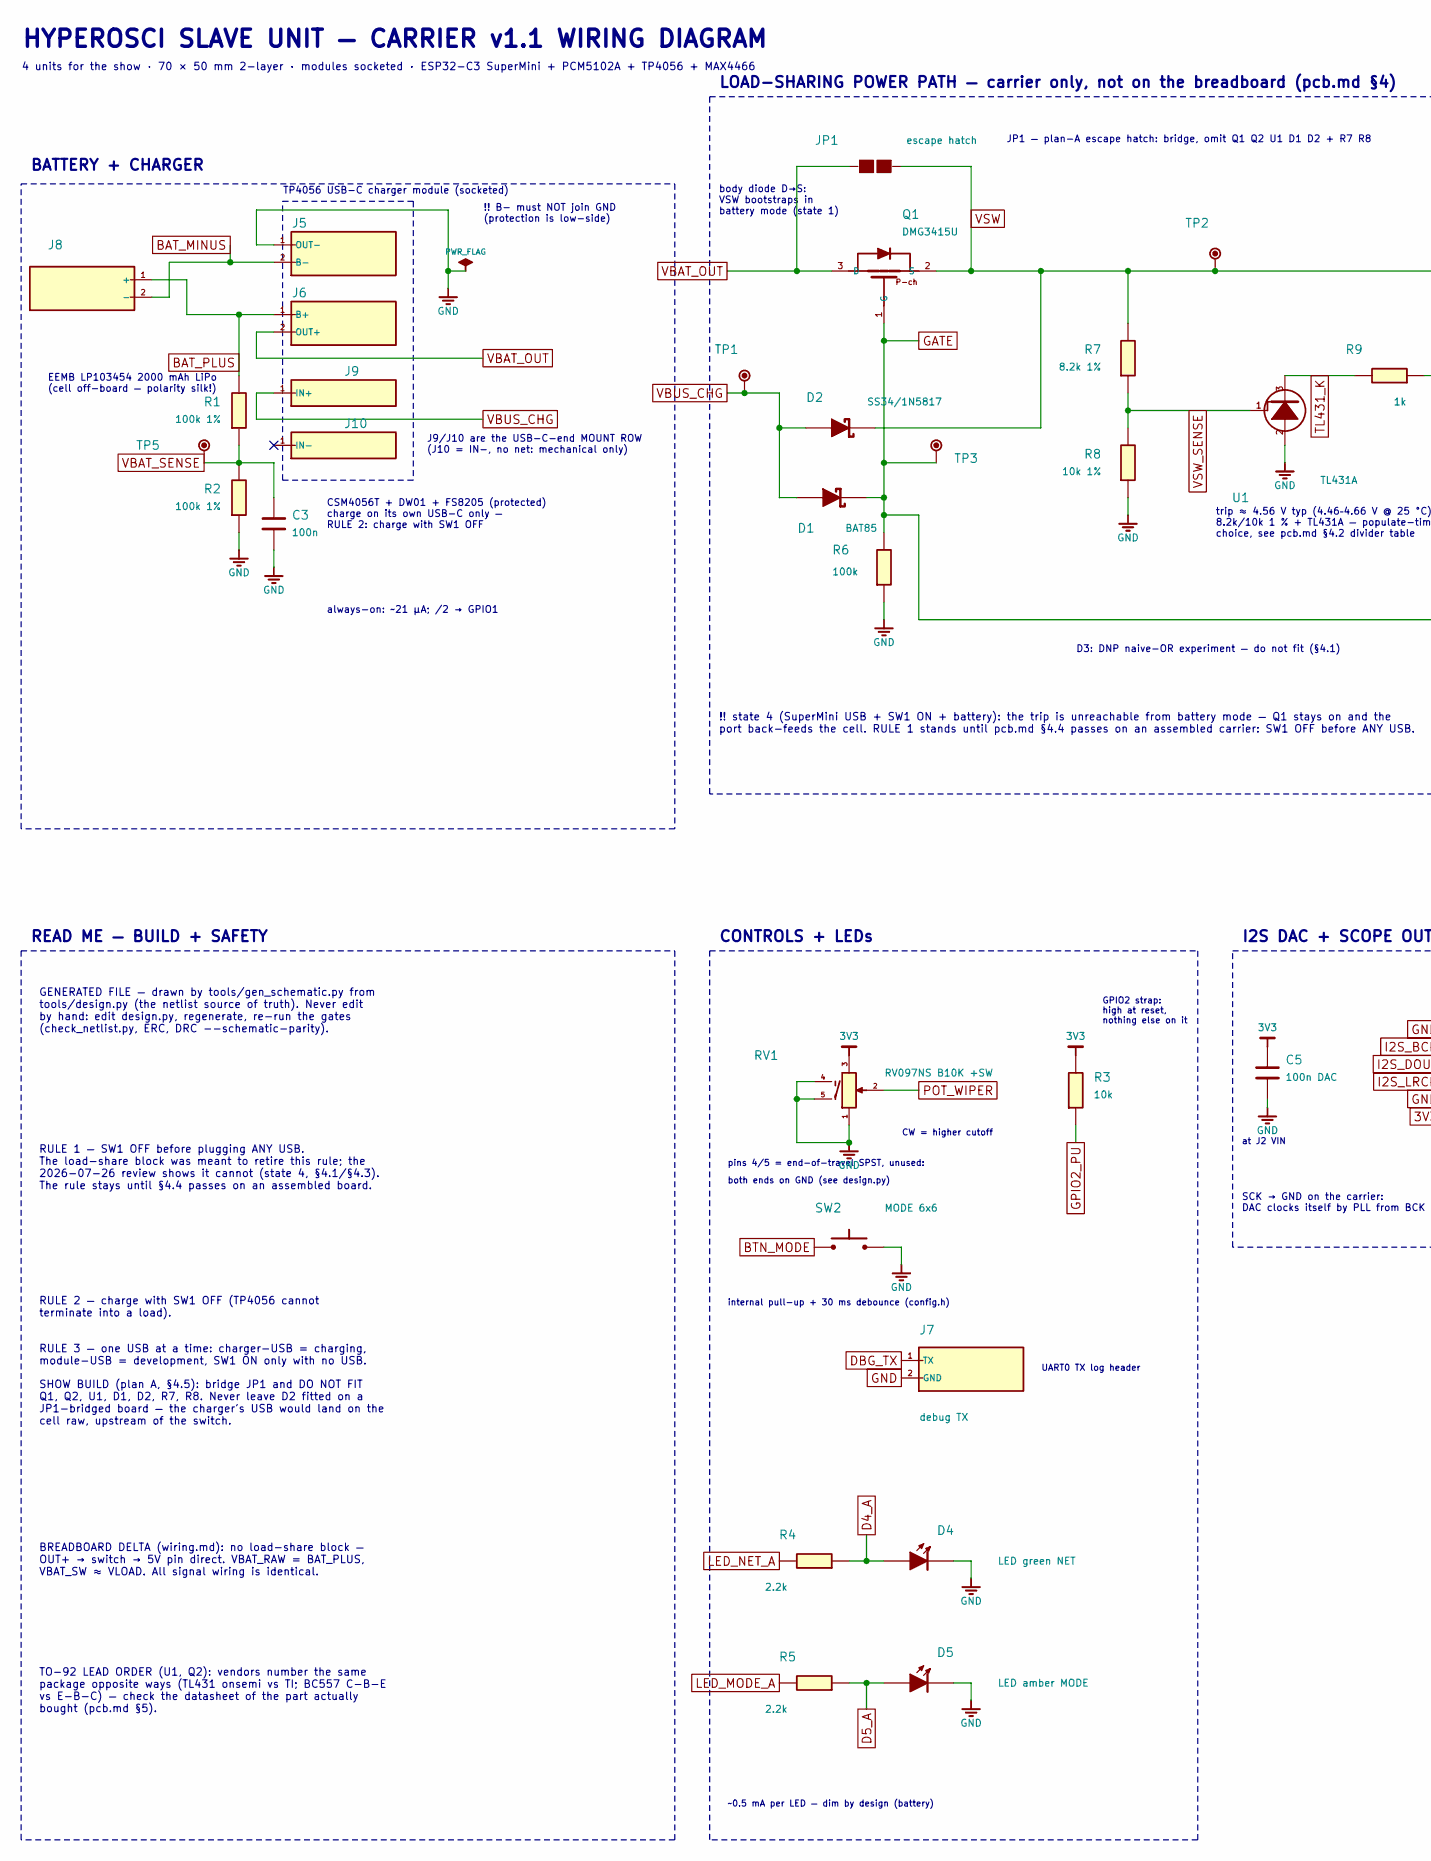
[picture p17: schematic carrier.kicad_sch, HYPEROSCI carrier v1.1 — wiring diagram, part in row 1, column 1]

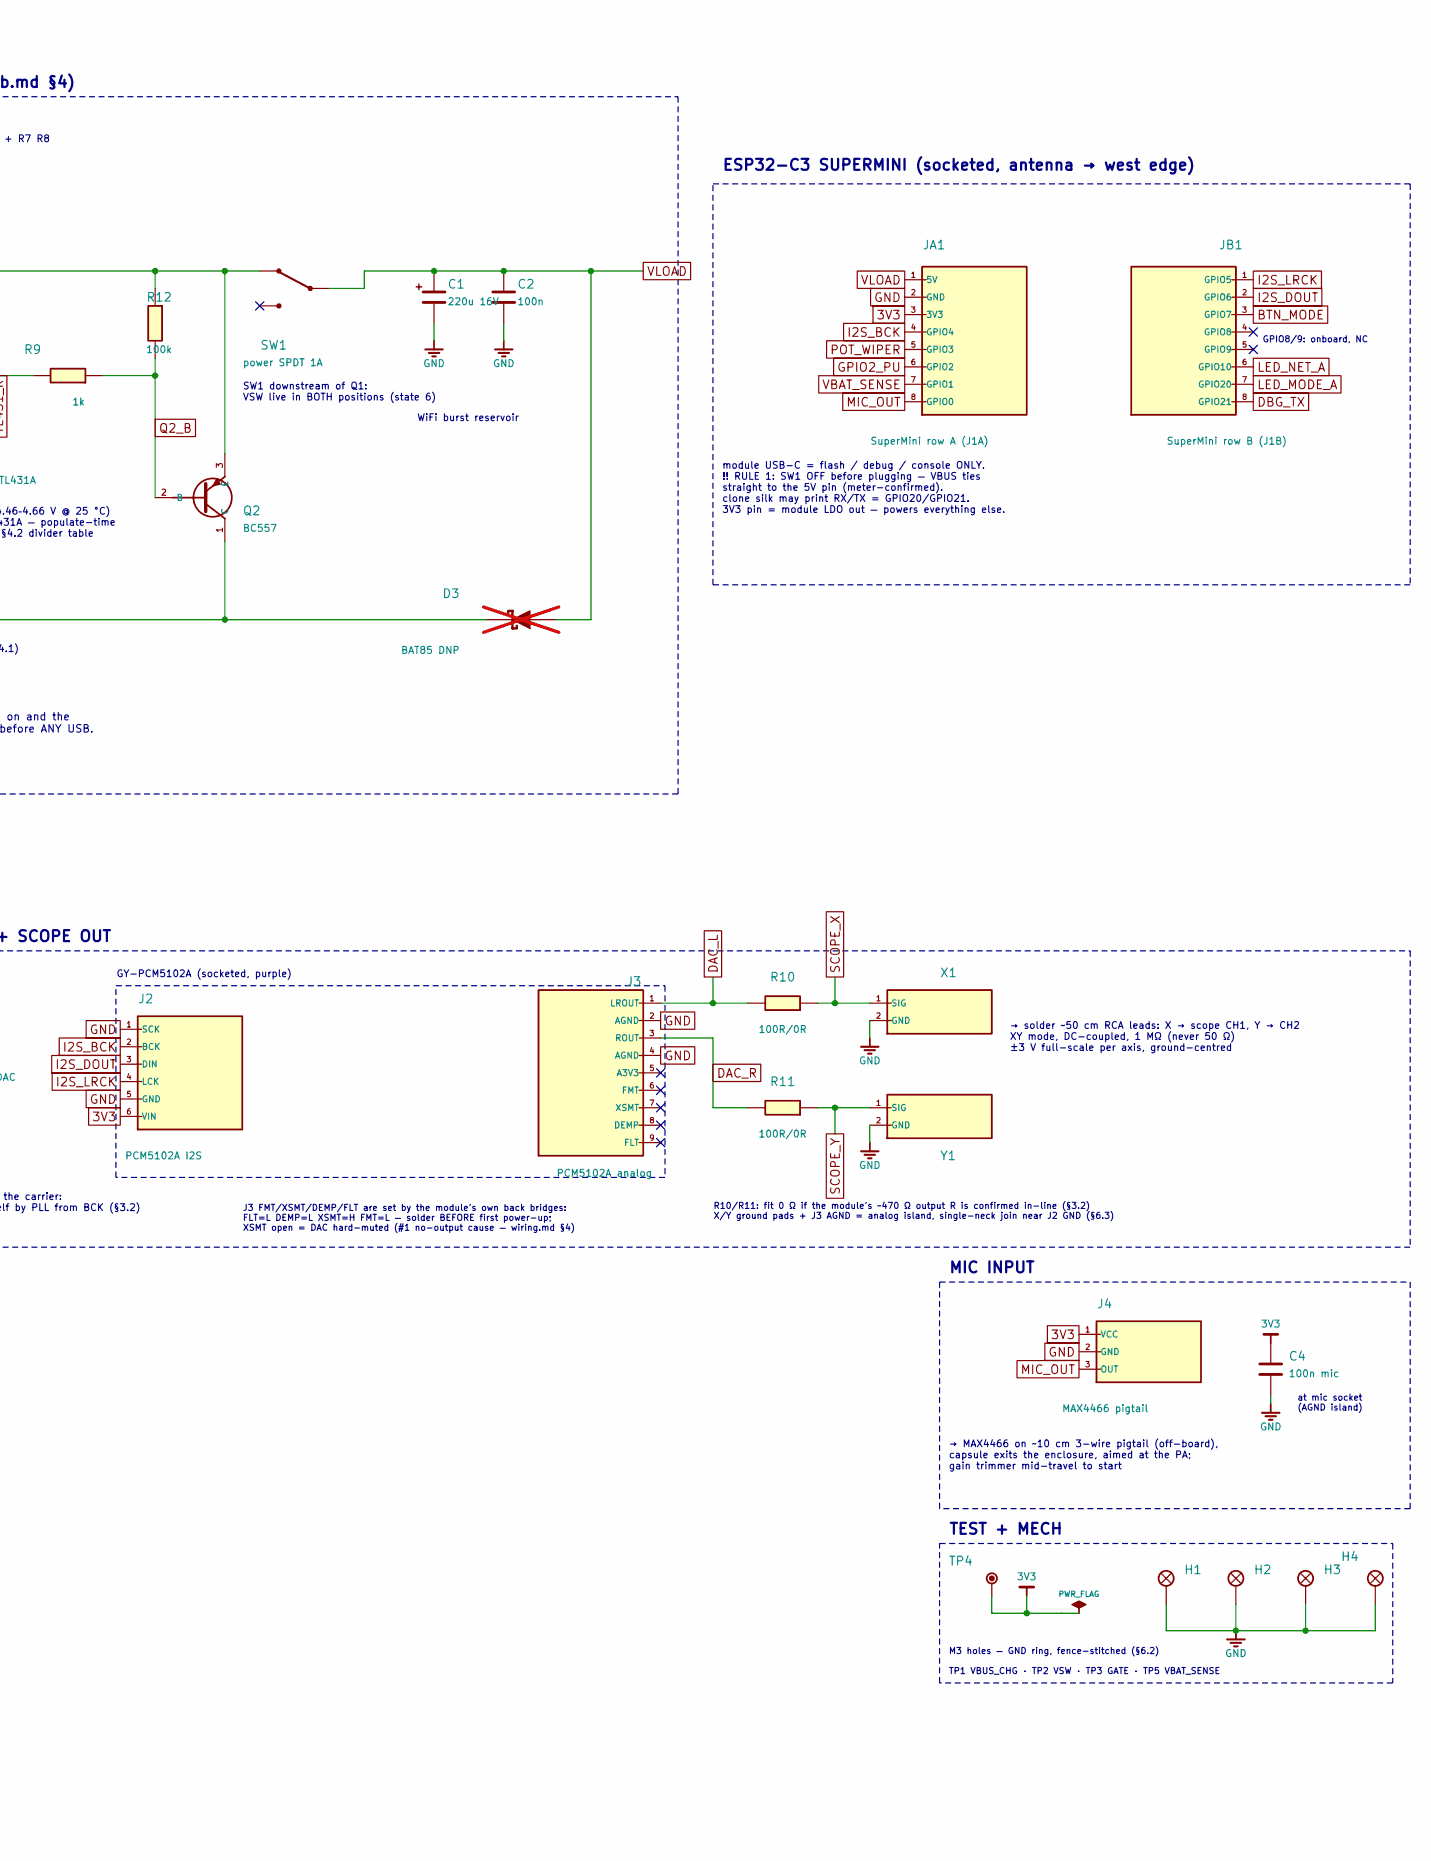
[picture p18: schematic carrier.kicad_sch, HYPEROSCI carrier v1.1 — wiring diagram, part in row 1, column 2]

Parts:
C1: 220u 16V; CP_Radial_D6.3mm_P2.50mm
C2, C3: 100n; C_Disc_D5.0mm_W2.5mm_P2.50mm
C4: 100n mic; C_Disc_D5.0mm_W2.5mm_P2.50mm
C5: 100n DAC; C_Disc_D5.0mm_W2.5mm_P2.50mm
D1: BAT85; D_DO-35_SOD27_P7.62mm_Horizontal
D2: SS34/1N5817; D_Dual_SMA_DO41
D3: BAT85 DNP; D_DO-35_SOD27_P7.62mm_Horizontal; not fitted
D4: LED green NET; LED_D3.0mm
D5: LED amber MODE; LED_D3.0mm
H1, H2, H3, H4: M3; MountingHole_3.2mm_M3_Pad
J2: PCM5102A I2S; PinSocket_1x06_P2.54mm_Vertical
J3: PCM5102A analog; PinSocket_1x09_P2.54mm_Vertical
J4: MAX4466 pigtail; PinSocket_1x03_P2.54mm_Vertical
J5: TP4056 OUT-/B-; TP4056_Pads_OUTminus_Bminus
J6: TP4056 B+/OUT+; TP4056_Pads_Bplus_OUTplus
J7: debug TX; PinHeader_1x02_P2.54mm_Vertical
J8: LiPo JST-PH; JST_PH_S2B-PH-K_1x02_P2.00mm_Horizontal
J9: TP4056 IN+ / mount (J6b); TP4056_MountPin
J10: TP4056 IN- / mount; TP4056_MountPin
JA1: SuperMini row A (J1A); PinSocket_1x08_P2.54mm_Vertical
JB1: SuperMini row B (J1B); PinSocket_1x08_P2.54mm_Vertical
JP1: escape hatch; SolderJumper_P2.54
Q1: DMG3415U; SOT-23_Handsoldering
Q2: BC557; TO-92_Inline_Wide
R1, R2: 100k 1%; R_Axial_DIN0207_L6.3mm_D2.5mm_P2.54mm_Vertical
R3: 10k; R_Axial_DIN0207_L6.3mm_D2.5mm_P10.16mm_Horizontal
R4, R5: 2.2k; R_Axial_DIN0207_L6.3mm_D2.5mm_P2.54mm_Vertical
R6, R12: 100k; R_Axial_DIN0207_L6.3mm_D2.5mm_P2.54mm_Vertical
R7: 8.2k 1%; R_Axial_DIN0207_L6.3mm_D2.5mm_P2.54mm_Vertical
R8: 10k 1%; R_Axial_DIN0207_L6.3mm_D2.5mm_P2.54mm_Vertical
R9: 1k; R_Axial_DIN0207_L6.3mm_D2.5mm_P2.54mm_Vertical
R10, R11: 100R/0R; R_Axial_DIN0207_L6.3mm_D2.5mm_P2.54mm_Vertical
RV1: RV097NS B10K +SW; RV097NS_Horizontal_Switch
SW1: power SPDT 1A; SW_Slide_SPDT_DualPitch
SW2: MODE 6x6; SW_PUSH_6mm_H5mm
TP1: VBUS_CHG; TestPoint_Pad_D1.5mm
TP2: VSW; TestPoint_Pad_D1.5mm
TP3: GATE; TestPoint_Pad_D1.5mm
TP4: 3V3; TestPoint_Pad_D1.5mm
TP5: VBAT_SENSE; TestPoint_Pad_D1.5mm
U1: TL431A; TO-92_Inline_Wide
X1: scope X RCA pads; RCA_FlyingLead_Pads
Y1: scope Y RCA pads; RCA_FlyingLead_Pads

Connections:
3V3: C4.1, C5.1, J2.6 (VIN), J4.1 (VCC), JA1.3 (3V3), R3.1, RV1.3 (CW), TP4.1
BAT_MINUS: J5.2 (B-), J8.2 (-)
BAT_PLUS: J6.1 (B+), J8.1 (+), R1.1
BTN_MODE: JB1.3 (GPIO7), SW2.1
D4_A: D4.2 (A), R4.2
D5_A: D5.2 (A), R5.2
DAC_L: J3.1 (LROUT), R10.1
DAC_R: J3.3 (ROUT), R11.1
DBG_TX: J7.1 (TX), JB1.8 (GPIO21)
GATE: D1.1 (K), D3.1 (K), Q1.1 (G), Q2.1 (C), R6.1, TP3.1
GND: C1.2 (-), C2.2, C3.2, C4.2, C5.2, D4.1 (K), D5.1 (K), H1.1, H2.1, H3.1, H4.1, J2.1 (SCK), J2.5 (GND), J3.2 (AGND), J3.4 (AGND), J4.2 (GND), J5.1 (OUT-), J7.2 (GND), JA1.2 (GND), R2.2, R6.2, R8.2, RV1.1 (CCW), RV1.4 (S1), RV1.5 (S2), SW2.2, U1.2 (A), X1.2 (GND), Y1.2 (GND)
GPIO2_PU: JA1.6 (GPIO2), R3.2
I2S_BCK: J2.2 (BCK), JA1.4 (GPIO4)
I2S_DOUT: J2.3 (DIN), JB1.2 (GPIO6)
I2S_LRCK: J2.4 (LCK), JB1.1 (GPIO5)
LED_MODE_A: JB1.7 (GPIO20), R5.1
LED_NET_A: JB1.6 (GPIO10), R4.1
MIC_OUT: J4.3 (OUT), JA1.8 (GPIO0)
POT_WIPER: JA1.5 (GPIO3), RV1.2 (W)
Q2_B: Q2.2 (B), R9.2, R12.1
SCOPE_X: R10.2, X1.1 (SIG)
SCOPE_Y: R11.2, Y1.1 (SIG)
TL431_K: R9.1, U1.3 (K)
VBAT_OUT: J6.2 (OUT+), JP1.1, Q1.3 (D)
VBAT_SENSE: C3.1, JA1.7 (GPIO1), R1.2, R2.1, TP5.1
VBUS_CHG: D1.2 (A), D2.2 (A), J9.1, TP1.1
VLOAD: C1.1 (+), C2.1, D3.2 (A), JA1.1 (5V), SW1.2 (COM)
VSW: D2.1 (K), JP1.2, Q1.2 (S), Q2.3 (E), R7.1, R12.2, SW1.1 (A), TP2.1
VSW_SENSE: R7.2, R8.1, U1.1 (REF)

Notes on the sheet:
BATTERY + CHARGER
TP4056 USB-C charger module (socketed)
J9/J10 are the USB-C-end MOUNT ROW (J10 = IN-, no net: mechanical only)
CSM4056T + DW01 + FS8205 (protected) charge on its own USB-C only — RULE 2: charge with SW1 OFF
EEMB LP103454 2000 mAh LiPo (cell off-board — polarity silk!)
!! B− must NOT join GND (protection is low-side)
always-on: ~21 µA; /2 → GPIO1
LOAD-SHARING POWER PATH — carrier only, not on the breadboard (pcb.md §4)
JP1 — plan-A escape hatch: bridge, omit Q1 Q2 U1 D1 D2 + R7 R8
body diode D→S: VSW bootstraps in battery mode (state 1)
trip ≈ 4.56 V typ (4.46–4.66 V @ 25 °C) 8.2k/10k 1 % + TL431A — populate-time choice, see pcb.md §4.2 divider table
SW1 downstream of Q1: VSW live in BOTH positions (state 6)
WiFi burst reservoir
D3: DNP naive-OR experiment — do not fit (§4.1)
!! state 4 (SuperMini USB + SW1 ON + battery): the trip is unreachable from battery mode — Q1 stays on and the port back-feeds the cell. RULE 1 stands until pcb.md §4.4 passes on an assembled carrier: SW1 OFF before ANY USB.
ESP32-C3 SUPERMINI (socketed, antenna → west edge)
GPIO8/9: onboard, NC
module USB-C = flash / debug / console ONLY. !! RULE 1: SW1 OFF before plugging — VBUS ties straight to the 5V pin (meter-confirmed). clone silk may print RX/TX = GPIO20/GPIO21. 3V3 pin = module LDO out — powers everything else.
I2S DAC + SCOPE OUT
GY-PCM5102A (socketed, purple)
SCK → GND on the carrier: DAC clocks itself by PLL from BCK (§3.2)
J3 FMT/XSMT/DEMP/FLT are set by the module's own back bridges: FLT=L DEMP=L XSMT=H FMT=L — solder BEFORE first power-up; XSMT open = DAC hard-muted (#1 no-output cause — wiring.md §4)
→ solder ~50 cm RCA leads: X → scope CH1, Y → CH2 XY mode, DC-coupled, 1 MΩ (never 50 Ω) ±3 V full-scale per axis, ground-centred
R10/R11: fit 0 Ω if the module's ~470 Ω output R is confirmed in-line (§3.2) X/Y ground pads + J3 AGND = analog island, single-neck join near J2 GND (§6.3)
at J2 VIN
MIC INPUT
→ MAX4466 on ~10 cm 3-wire pigtail (off-board), capsule exits the enclosure, aimed at the PA; gain trimmer mid-travel to start
at mic socket (AGND island)
CONTROLS + LEDs
CW = higher cutoff
pins 4/5 = end-of-travel SPST, unused:
both ends on GND (see design.py)
internal pull-up + 30 ms debounce (config.h)
GPIO2 strap: high at reset, nothing else on it
UART0 TX log header
~0.5 mA per LED — dim by design (battery)
TEST + MECH
M3 holes — GND ring, fence-stitched (§6.2)
TP1 VBUS_CHG · TP2 VSW · TP3 GATE · TP5 VBAT_SENSE
READ ME — BUILD + SAFETY

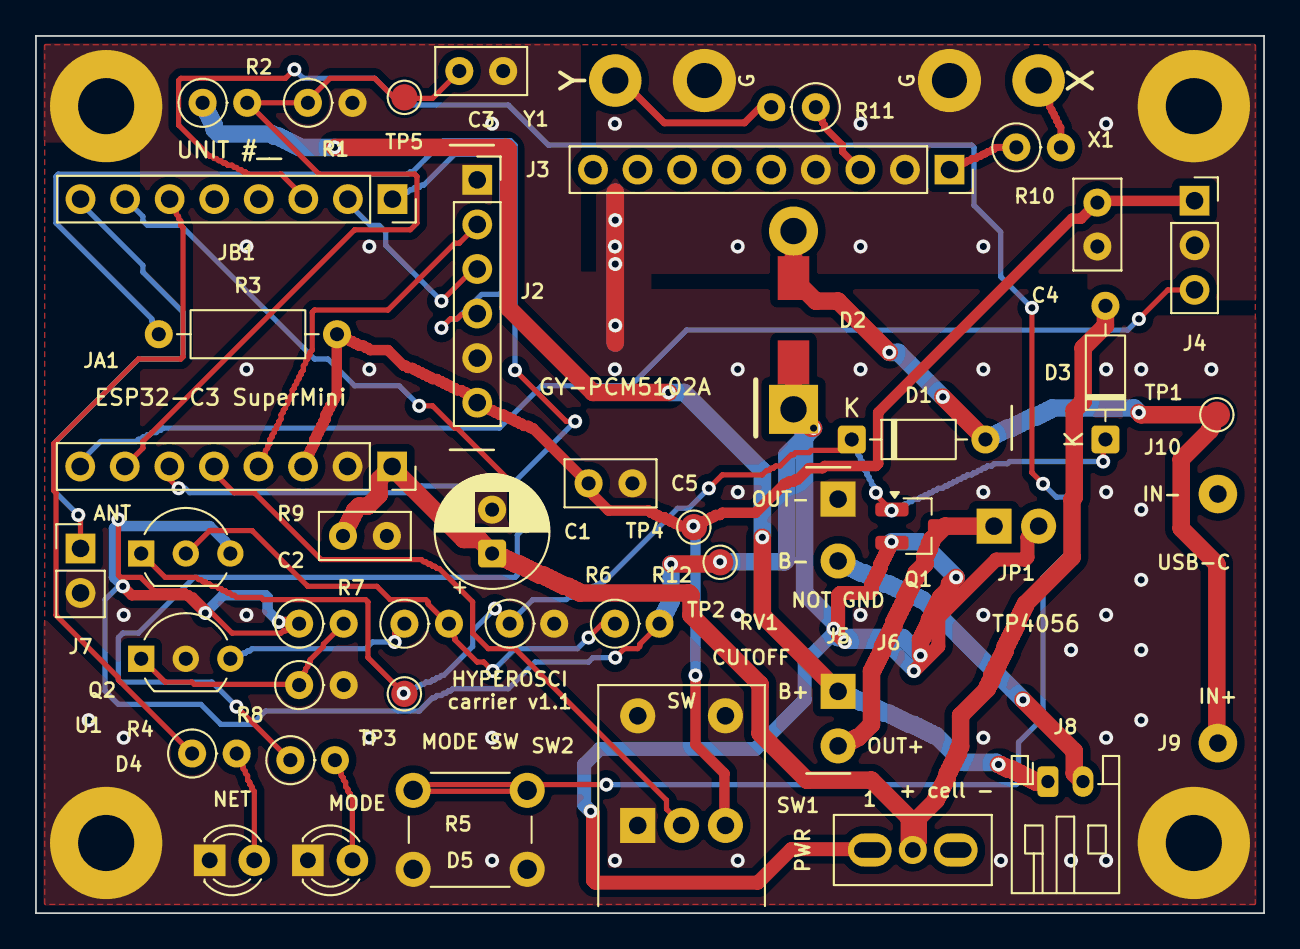
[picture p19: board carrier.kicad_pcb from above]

Board: 2 copper layers, 70.0 x 50.0 mm, 51 parts (0 on the bottom side), 29 nets.

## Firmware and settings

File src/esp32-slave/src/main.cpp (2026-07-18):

// HYPEROSCI slave firmware — ESP32-C3 SuperMini + PCM5102A + MAX4466.
// Architecture: docs/firmware/esp32-architecture.md. Pins: include/config.h.
#include <Arduino.h>

#include "audio_out.h"
#include "config.h"
#include "mic_in.h"
#include "mode_manager.h"
#include "net_rx.h"
#include "renderer_local.h"
#include "ui.h"

// Crash forensics (2026-07-18 LOCAL-pattern wedge): progress markers the
// debugger can read over JTAG when the console is dead. TEMPORARY.
extern "C" {
volatile uint32_t g_ckpt = 0;   // last checkpoint passed (see call sites)
volatile uint32_t g_iter = 0;   // audio loop iterations
}

namespace {

TaskHandle_t g_audio_task = nullptr;

// The audio task is the heartbeat of the unit: one 5 ms block per iteration,
// paced by the blocking I2S DMA write. It must never block on anything else.
void audio_task(void*) {
  static int16_t block[AUDIO_BLOCK_FRAMES * 2];
  for (;;) {
    g_iter++;
    g_ckpt = 1;
    mode_manager::fill_block(block, AUDIO_BLOCK_FRAMES);
    g_ckpt = 2;
    audio_out::write(block, AUDIO_BLOCK_FRAMES);
    g_ckpt = 3;
  }
}

}  // namespace

namespace app {
// Audio-task stack headroom (words), for `stat` — crash forensics 2026-07-18.
uint32_t audio_stack_hwm() {
  return g_audio_task ? uxTaskGetStackHighWaterMark(g_audio_task) : 0;
}
}  // namespace app

void setup() {
  Serial.begin(115200);

  ui::init();  // must be first: samples "MODE held at boot"

  const bool boot_local = ui::boot_local_requested();
  mode_manager::init(boot_local ? mode_manager::Mode::LOCAL
                                : mode_manager::Mode::NETWORK);

  // I2S before ADC: both allocate GDMA/interrupt resources; probing which one
  // loses the race when they contend (bring-up).
  if (!audio_out::init()) Serial.println("[init] i2s FAILED");
  if (!mic_in::init()) Serial.println("[init] adc_continuous FAILED");
  renderer_local::init();

  net_rx::set_cmd_handler(mode_manager::handle_command);
  net_rx::init(!boot_local);  // radio off when booted into forced-local

  // Audio gets the highest priority in the system after WiFi internals.
  // (4096 is plenty: stack HWM measured ~90% free during the 2026-07-18
  // wedge forensics — the 8192 experiment ruled out stack overflow.)
  xTaskCreate(audio_task, "audio", 4096, nullptr, 10, &g_audio_task);

  Serial.printf("HYPEROSCI slave id=%u mode=%s — 'help' for console\n",
                mode_manager::slave_id(), mode_manager::mode_name());
}

void loop() {
  ui::poll();
  delay(10);  // ~100 Hz UI/console; audio + network run in their own tasks
}

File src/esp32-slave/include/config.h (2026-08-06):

// HYPEROSCI slave — canonical hardware configuration.
// This file mirrors docs/DESIGN.md §4/§6/§7. Change both together or not at all.
#pragma once

#include <stdint.h>

// ---------------------------------------------------------------------------
// Pin map — ESP32-C3 SuperMini. No signals on strapping pins (2, 8, 9).
// ---------------------------------------------------------------------------
#define PIN_MIC_ADC 0     // ADC1_CH0 — MAX4466 OUT (biased ~VCC/2)
#define PIN_VBAT_ADC 1    // ADC1_CH1 — battery via 100k/100k divider + 100nF
// GPIO2: strapping pin, unused, 10k pull-up on carrier board
#define PIN_POT_ADC 3     // ADC1_CH3 — 10k pot wiper (filter cutoff control)
#define PIN_I2S_BCK 4     // PCM5102A BCK
#define PIN_I2S_LRCK 5    // PCM5102A LCK
#define PIN_I2S_DOUT 6    // PCM5102A DIN
#define PIN_BTN_MODE 7    // momentary to GND, internal pull-up
#define PIN_LED_ONBOARD 8 // SuperMini blue LED, ACTIVE LOW, heartbeat only
#define PIN_BTN_BOOT 9    // onboard BOOT button (secondary user button)
#define PIN_LED_NET 10    // green status LED (active high, ~2.2k series)
#define PIN_LED_MODE 20   // amber mode LED (active high, ~2.2k series)
// GPIO21: UART0 TX, reserved for debug header (primary console = USB-C CDC)

// ---------------------------------------------------------------------------
// Audio
// ---------------------------------------------------------------------------
#define SAMPLE_RATE 48000           // I2S output rate, fixed for v1
#define AUDIO_BLOCK_FRAMES 240      // 5 ms blocks, matches network packet size
#define ADC_SAMPLE_RATE_TOTAL 72000 // adc_continuous total (3 ch => 24k each)
#define ADC_NUM_CHANNELS 3          // mic, vbat, pot
#define MIC_SAMPLE_RATE 24000       // per-channel rate
#define MIC_UPSAMPLE 2              // 24 kHz mic -> 48 kHz out (linear interp)

// Local-mode Y filter: 2-pole Butterworth LPF, cutoff set by pot.
// Values carried over from the proven esp32c3SIGMADELTA unit.
#define LOCAL_LPF_FC_MIN_HZ 20.0f
#define LOCAL_LPF_FC_MAX_HZ 300.0f
#define HYBRID_MIC_GAIN 0.5f // mic contribution in HYBRID mode

// ---------------------------------------------------------------------------
// Jitter buffer / sync
// ---------------------------------------------------------------------------
// Sized to ride through WiFi radio stalls at the controller's 300 ms deadline
// lead. The UNO-Q's ath10k AP goes deaf 3x ~103 ms back-to-back (~310 ms of
// every ~1.31 s cycle = 24% airtime; measured 2026-08-04, STATUS.md — firmware
// scan-like cycle: not BT-coex, not power save, not P2P, not host scans —
// unfixable from userspace); the buffer must absorb lead + post-stall burst.
#define JB_CAPACITY_FRAMES 24576 // ~512 ms at 48 kHz (96 KiB)
#define JB_TARGET_DEPTH_MS 60   // startup buffering target
#define STREAM_TIMEOUT_MS 1000  // no audio packets -> fallback (v3.1 req)
#define SYNC_STALE_MS 5000      // no SYNC beacon -> clock considered stale
#define DEADLINE_SLACK_US 5000  // +-5 ms playback tolerance (v3.1 req)

// ---------------------------------------------------------------------------
// Network (docs/protocol.md is normative)
// ---------------------------------------------------------------------------
#define WIFI_SSID_DEFAULT "HYPEROSCI_AP"
#define WIFI_PASS_DEFAULT "hyperosci2026"
#define WIFI_CONNECT_TIMEOUT_MS 5000
#define MCAST_GROUP 239, 0, 0, 1
#define PORT_AUDIO 5000
#define PORT_CTRL 5001
#define PORT_STATUS 5002
#define STATUS_INTERVAL_MS 1000

// ---------------------------------------------------------------------------
// Power management (see docs/hardware/power-budget.md)
// ---------------------------------------------------------------------------
#define VBAT_DIVIDER 2.0f     // 100k/100k
#define VBAT_WARN_MV 3450     // low-battery LED pattern
#define VBAT_WIFI_OFF_MV 3300 // drop to LOCAL, radio off
#define VBAT_SLEEP_MV 3050    // deep sleep to protect the cell
#define VBAT_HYSTERESIS_MV 50

// ---------------------------------------------------------------------------
// UI timing
// ---------------------------------------------------------------------------
#define BTN_DEBOUNCE_MS 30
#define BTN_LONGPRESS_MS 2000
#define HEARTBEAT_PERIOD_MS 1000

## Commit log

2026-07-17 Initial commit: HYPEROSCI slave firmware + hardware/protocol docs
    Restructure into docs/ + src/ and build out the ESP32-C3 slave.
    Firmware (src/esp32-slave/, PlatformIO + pioarduino, Arduino 3.x/IDF5):
    - I2S master TX to PCM5102A (48 kHz/16-bit stereo, no MCLK)
    - adc_continuous DMA front end (mic 24 kHz + vbat + pot)
    - local renderer: mic->X, pot-controlled Butterworth LPF->Y
    (ported from the proven esp32c3SIGMADELTA unit) + test patterns
    - deadline-continuity jitter buffer with loss concealment
    - SYNC-beacon time offset tracking
    - LOCAL/NETWORK/HYBRID mode machine with <1 s mic auto-fallback
    - buttons/LEDs/battery policy + USB-CDC console
    Compiles clean (RAM 26%, Flash 32%).
    Docs (docs/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
    [audio_out.cpp, config.h, main.cpp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]
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2026-07-18 docs: bench measurements + resolve Q3/Q9/Q10; PCM5102A is 1×9/32mm
    Caliper+meter session (2026-07-18, ANENG A9002 + photos in docs/hardware/images/):
    - measurements.md: filled from real modules, front/back photos embedded, findings box
    - Q3/Q9 pot RESOLVED: RV097NS-B10K, 5-pin, 27.3×9.5×11.3mm, metal shaft turned
    directly (no knob) -> footprint finalized, no PCB-blocker remains
    - Q10 RESOLVED: SuperMini VBUS<->5V confirmed tied (meter) -> 'no USB while switch ON'
    rule stands, D3 stays DNP
    - PCM5102A analog end is a 1x9 header (LROUT/AGND/ROUT/AGND/A3V3/FMT/XSMT/DEMP/FLT),
    NOT a 3-pin L G R: J3 -> 1x9, footprint GY-PCM5102A_6+9, taps X=LROUT/Y=ROUT/gnd=AGND
    - PCM5102A measures ~31.8m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
2026-07-18 fw+tools: fix C3 I2S/ADC GDMA interrupt conflict; first end-to-end UDP stream
    Bench bring-up (2026-07-18) found the ESP32-C3 GDMA drivers fighting over
    pair 0's single interrupt source (DMA_CH0): whichever of i2s_std /
    adc_continuous initialized second either failed init (ESP_ERR_NOT_FOUND) or
    silently delivered no DMA data. Fix: init I2S first, then occupy pair 0's
    free RX slot with a decoy GDMA channel (no ISR) so the ADC lands on pair 1
    with its own DMA_CH1 interrupt. Both drivers now run simultaneously.
    Also:
    - audio_out: guard write() when init failed (a write to a never-enabled
    channel blocks forever and starved the mic pump / froze all ADC telemetry);
    expose init step/err + write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
    [audio_out.cpp, main.cpp, mic_in.cpp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]
2026-07-18 unoq: web control panel + controller daemon (hype_controller.py)
    Supersedes hype_sender.py for day-to-day use: same streaming engine plus an
    embedded stdlib web UI (:8080) — pattern/freq/amp control, stream on/off,
    per-slave and all-slave mode toggles (network/mic/hybrid), identify, gain,
    reboot — all riding the HYPE_CMD JSON packets the firmware already handles.
    Installed on the UNO-Q as systemd service hyperosci-controller (unit mirrored
    in deploy/). Verified end-to-end against slave 121: unicast CMD to the
    multicast-bound ctrl socket is received; mode round-trip, pattern switch and
    stream pause/resume (clean single re-anchor) all confirmed via STATUS.
2026-07-18 fw+unoq: ride through ath10k AP radio stalls; dashboard v2 (tooltips, health rates, local patterns)
    Root cause of the dot-every-second on scope: the UNO-Q's ath10k_snoc AP goes
    deaf ~100-300 ms every ~1.44 s (firmware quirk; isolated with a second STA —
    not BT-coex, not runtime PM, not P2P, not client power save). An 80 ms lead
    against a 170 ms jitter buffer could never ride that out.
    Firmware: JB capacity 170->512 ms (RAM 46%, ~47 KB heap free with WiFi up);
    force esp_wifi_set_ps(WIFI_PS_NONE) in on_wifi_up (setSleep(false) before
    begin() doesn't stick on core 3.x) and expose ps= in stat; new set_pattern
    CMD selects the local render (mic/circle/lissajous/ramp/square).
    Controller: LEAD_US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
    [config.h, ui.cpp]
2026-07-18 fw+unoq: one-question dashboard (draw row), per-slave stream gating, STATUS local_pattern; hunt LOCAL-pattern wedge
    - controller: stop streaming to LOCAL slaves (fixes drop-counter inflation,
    answers 'why stream at a mic slave'); parse 35-byte STATUS (local_pattern);
    dashboard v3: merged draw row (STREAM/HYBRID/local patterns), plain-language
    playing line with buffering grace, dimmed pattern panel when stream off,
    rewritten help legend, 350 ms buf tooltips
    - fw: STATUS +local_pattern byte (protocol.md updated); source smoothed over
    <150 ms conceal gaps; jb flush on entering LOCAL; ADC drain during non-mic
    local patterns; pattern oscillators rewritten as phasor rotators (2 libm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
    [main.cpp, ui.cpp]
2026-07-18 STATUS: LOCAL-pattern wedge resolved — phasor-rotator renderers verified on hardware
    LOCAL+circle 3.75 min soak clean (previously hard-wedged <10 s), lissajous/
    ramp/square 40 s each clean, clean rejoin to the stream. Root trigger: 480
    soft-float sinf/cosf ROM calls per 5 ms block starving/browning the chip.
    Power margin note added for the PCB rev.
2026-07-18 controller: 450 ms send lead + non-blocking audio socket (perf Tier 1)
    - LEAD_US 350 -> 450 ms: ~150 ms of buffer left through a worst-case
    ~300 ms ath10k AP stall (was ~50 ms), still under the slave's 512 ms
    jitter buffer. Verified on hardware: slave settles at depth=21600
    frames = 450 ms exactly.
    - audio.setblocking(False) per protocol.md §10: a blocked sendto to
    one slave must never stall the 4-slave fan-out past the 20 ms
    re-anchor threshold. The existing except-OSError already swallows
    EWOULDBLOCK.
    - protocol.md: sync stale constants (JB 8192/170ms -> 24576/512ms,
    60 ms lead -> LEAD_US=450ms) with the code they describe.
2026-07-18 slave: kill soft-float in hot paths — Q15 gain, light ADC drain (perf Tier 2)
    - audio_out: per-sample gain scale is now a Q15 integer multiply
    (<=1 LSB vs float, only active when an operator trims gain below
    100%). No float left in the prio-10 output path.
    - mic_in: pump(mic_math) — drain() still fully empties the ADC DMA
    pool (the documented anti-wedge) but skips the per-sample soft-float
    DC-blocker/ring work when the mic output is discarded (NETWORK
    streaming, non-mic local patterns), and decimates the vbat/pot/bias
    IIRs 1-in-256 (~1 s freshness, matches power-budget.md). Frees
    ~8-10% of the FPU-less core. MIC/HYBRID keep the full path via
    read().
    - renderer_local: upda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
    [audio_out.cpp, mic_in.cpp]
2026-07-18 slave: AsyncUDP audio RX + wire-visible lost-packet counter
    The audio socket moves from WiFiUDP polling to AsyncUDP: a raw lwIP
    udp_recv callback feeds a 32-deep queue drained by the async_udp task
    (bumped to prio 8, between net_rx and audio). This bypasses the 6-slot
    per-socket mailbox (CONFIG_LWIP_UDP_RECVMBOX_SIZE, prebuilt libs) that
    silently dropped post-stall AP bursts below the socket layer - the
    measured rx of 155-175/200 pkt/s with drop=0 - and removes WiFiUDP's
    per-packet malloc + copies. Ctrl (2 Hz SYNC + rare CMD) and TX-only
    status stay on WiFiUDP in net_task, which now ticks at 5 ms.
    New STATUS field lost_packets (55->59 B, trailing-bytes-compatible per
    protocol.md §2.2): cum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
    [ui.cpp]
2026-07-18 controller: parse + display slave lost_packets
    STATUS payloads >= 59 B carry the new lost_packets uint32 (appended
    after local_pattern); shorter payloads from not-yet-reflashed slaves
    parse as before and show 'lost -' on the dashboard. Cards gain a
    lifetime lost chip and a lost/s health rate so silent WiFi loss is
    finally visible next to drop/s and under/s. Also refresh the stale
    350 ms buffer-depth copy to the current 450 ms lead.
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2026-07-19 docs: bring all docs in line with the code (repo-wide staleness sweep)
    - unoq-controller/README.md rewritten: controller is deployed, not a stub;
    documents the real single-file app, API, presets, and the deliberate
    deviations (NetworkManager AP at 192.168.50.1, no FastAPI/WebSocket,
    laptop stand-in skipped, osci-render evaluated and rejected).
    - 192.168.4.1 -> 192.168.50.1 everywhere current (README, protocol.md,
    DESIGN.md, PLAN.md, wiring.md).
    - Jitter-buffer numbers: 8192/170ms/60ms -> 24576/512ms cap, 60ms start
    gate, 450ms controller lead (README, DESIGN §6, esp32-architecture, PLAN).
    - protocol.md §7.3: real /api/cmd + 1Hz /api/state polling, no WebSocket.
    - esp32-architectu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
2026-07-22 controller: persist the live pattern, surface AP state, undo for presets
    A restart used to come back drawing a circle whatever was on the scopes,
    and --pattern could not even name "text". The pattern now persists to
    ~/hype_state.json and is restored in State.__init__ BEFORE the text table
    is built, so the first 5 ms block out is already correct -- no flash of a
    default on stage. --pattern only decides the first ever boot.
    - persist_loop is a 3 s debounced writer on its own thread: os.replace on
    the eMMC can block for tens of ms, which on the stream thread is several
    missed blocks. Measured 4 disk writes per 120 POSTs, so dragging a
    slider does not chew the flash.
    - The file goes throu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
2026-07-22 deploy: hyperosci-netwatch, unattended AP recovery
    Two faults take the rig off the air and neither can be cleared from the
    phone, because both of them break the phone's own path to the box:
    1. hyperosci-ap is not up, so nothing holds 192.168.50.1 and no slave
    can associate. NM autoconnect (now enabled, with unlimited retries)
    handles the ordinary case; this catches the rest.
    2. The ath10k per-station rate-control wedge documented in STATUS.md.
    The manual fix was nmcli c down/up plus a controller restart; the
    restart is no longer needed since bind_egress re-applies
    IP_MULTICAST_IF every 500 ms beacon.
    A separate root-owned oneshot + 30 s timer, NOT a thread in t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
2026-07-22 tests: board-side regression suites for the controller
    Four suites, ~39 checks. Run them ON THE BOARD: the dev box has no Hershey
    fonts and a different Python, so it is a valid reference for neither
    behaviour nor timing.
    test_fixes.py the six bugs + the eight show names, incl. accents
    test_persist.py ~/hype_state.json round-trip, corrupt-file resilience
    test_netwatch.py every watchdog trigger and, more importantly, every
    case that must NOT trigger one
    live_test.py against the running daemon over HTTP
    test_fixes.py and test_persist.py point HYPE_STATE/HYPE_PRESETS at a temp
    dir BEFORE importing the controller. That is load-bearing now that State()
    res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
2026-07-22 docs: boot/network fixes, persistence, watchdog; heat analysis into docs/
    The "no slaves discovered yet..." that survived every code fix was not a
    code fault at all: hyperosci-ap shipped with connection.autoconnect=no, so
    after any reboot NetworkManager left wlan0 disconnected, nothing held
    192.168.50.1, and no slave could associate. Fixed with autoconnect yes,
    priority 10, retries 0 (retry forever, so the AP self-heals after a radio
    wedge instead of giving up after NM's default four tries). Verified across
    a real reboot: 18 s from service start to a streaming slave, no manual
    steps.
    Also recorded:
    - The USB tether address wandered (.128 -> .127) because it was pure DHCP
    off the laptop's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
2026-07-22 controller: raise the preset cap to 20, keep the page's "max N" in step
    The eight show names plus the four already saved is 12, over the old cap of
    10 -- and the alternative was deleting presets to make room, which is the
    one thing the undo backup exists to prevent. 20 costs nothing: the list is
    read once at startup and the preset row already wraps.
    The page's button title hardcoded "max 10" and would have drifted silently.
    It now carries a __PRESETS_MAX__ placeholder substituted from the constant
    after PAGE is defined -- a targeted .replace(), not .format(), because the
    page is full of JS braces.
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2026-07-26 hw+docs: apply the 2026-07-26 power-path design review
    Multi-agent adversarial review of the carrier's §4 load-sharing power path
    (docs/hardware/pcb-review-findings.md, added here) found the TL431 trip
    point mis-derived and several safety-critical instructions wrong. This
    applies the fixes and reconciles every document that repeated them.
    BOM / netlist (design.py is the source of truth; board + schematic regenerated):
    - R7 75k -> 8.2k, R8 10k, R9 2.2k -> 1k. The old derivation dropped the
    TL431 REF bias term (I_ref*R7); with 75k it dominated and the divider
    could not reach the trip window at all. Trip is now ~4.56 V.
    - D1 1N4148 -> BAT85 (Schottky, keeps the gate pulled low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
    [carrier.kicad_pcb, carrier.kicad_sch]
2026-07-26 hw/carrier: RV1 was the wrong part's footprint — corrected, re-routed
    The RV097NS 5-pin is "mono WITH SWITCH", right-angle. RV097NS_Vertical
    drew it as a vertical pot with two mechanical bracket lugs: row 2 as oval
    slots 9.5 mm apart and 7.0 mm behind the pot row, taken "from the common
    RV09 drawing" and flagged unverified since the first commit. The real
    part has no bracket lugs at all. Row 2 is a plain SPST on 1.0 mm holes
    5.0 mm apart and 6.25 mm behind, and the mounting surface sits 5.0 mm in
    FRONT of the pot row, not 1.2 mm. Every row-2 pad was 2.25 mm out in X
    and 0.75 mm in Y. The part would not have gone into the board.
    Settled by the seller's mechanical drawing, which agrees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
    [carrier.kicad_pcb, carrier.kicad_sch]
2026-07-27 hw/carrier: the TP4056 was a 21.65 mm cantilever — second mount row added
    J5/J6 put all four pins in ONE column at one end of the module, and the
    USB-C jack is at the other. A row of pins resists rotation about its own
    axis only by bending, so the charge port sat on a diving board:
    0.64 mm square pin, ~5 mm free length -> EI/L = 0.061 N*m/rad each
    four of them, all on the axis -> ~0.25 N*m/rad total
    5 N off-axis nudge on the plug -> 0.11 N*m -> ~25 deg
    Crude (a machined socket grips several mm of barrel, so reality is
    stiffer), but the order of magnitude is the point: grams of side load,
    tens of degrees, on the one connector handled every charge cycle at
    10-20 N of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
    [carrier.kicad_pcb, carrier.kicad_sch]
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2026-07-28 hw/carrier: WIP pre-fab DFM pass — board is UNROUTED, do not plot gerbers
    Implements the v1.1 pre-fab fix list. Everything that does not depend on
    routing is done and passes; the router seed re-sweep is not, so the board is
    committed straight out of gen_board.py with 58 unconnected items.
    A1 — silk stroke 0.12 -> 0.15 mm (JLC minimum; all 70 items were under spec).
    One constant, SILK_W, replaces seven literals. Height stays 0.8 mm: raising it
    would grow every bounding box on a board whose placement search cannot absorb
    that. 282 stock-footprint outlines are still at 0.12 and are left alone —
    they are graphic lines, not text, and JLC's floor is about legibility.
    A2 — SW1's plated sl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
    [carrier.kicad_pcb]
2026-07-28 hw/carrier: routed on seed 33 — the board is fabbable again
    Completes the WIP pre-fab pass. c48cff9 left carrier.kicad_pcb straight out of
    gen_board.py with 58 unconnected items because the DFM fixes moved copper and
    invalidated the router seed. They are now routed, every gate passes, and the
    width tables are regenerated from the routed copper instead of from memory.
    Seed 11 is dead. Three sub-millimetre moves killed it — SW1's slot pads out to
    +/-2.45, SW1 itself 0.4 mm south, C3 0.79 mm north — and it came back 1
    unconnected / 1 unrouted on BAT_PLUS. Worth stating plainly: 11 had held through
    two previous re-routes and was not a fragile choice. A 16-variant sweep (4 seeds
    x 4 halo s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
    [carrier.kicad_pcb]
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2026-07-28 hw/carrier: re-plot the fab package — the gerbers predated the artwork
    The fab set was plotted at ddcbc13, one commit before the back-silk artwork
    landed, so carrier-B_Silkscreen.gbo held zero region fills: the 48 mark and the
    ponkiePCBv1 wordmark were not in the package at all. Uploading it would have
    produced boards with a blank back silk and nothing would have said so.
    This is the failure mode pcb.md 9 warns about arriving by a second route. That
    warning is about forgetting B.Silkscreen in the layer list; here the layer was
    plotted correctly and the *board* moved underneath it. Nothing catches either
    one: the board file is correct, DRC is clean, and plot_fab.py's assertions are
    copper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
    [carrier-B_Cu.gbl, carrier-B_Mask.gbs, carrier-B_Silkscreen.gbo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]
2026-07-28 hw/carrier: SW1 closes on the drawing — 2.5 mm, and the slot earns its keep
    The last gate on the fab order. It closed from the SS12D00 mechanical drawing,
    without the part in hand and without the paper doll, and nothing in the layout
    moved — so the gerbers committed in 212fcd2 are unaffected and remain valid.
    Docs only; carrier.kicad_pcb, HYPEROSCI.pretty/ and fab/gerbers/ are untouched.
    The pitch is 2.5 mm. That is NEITHER of the two values the footprint was drawn
    around, and it is the whole argument for the slot: a hole drilled for 2.0 or for
    2.54 would have been wrong, and the guess that looked safe (2.54, the SS12D00
    being the named example in the 2.54 case) was wrong by 0.04 mm mor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
    [gen_footprints.py]
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2026-07-31 controller: a refused timer fire must not cost the rule its turn
    Three defects found reviewing the interval timers against the board, each
    reproduced before it was fixed.
    timer_loop wrote the next fire time before calling fire_timer and ignored
    the result. A rule that came due behind another rule's hold was therefore
    refused by the post-release cooldown 250 ms later with its turn already
    spent, and waited a whole period -- exactly the case the loop's docstring
    promised to handle ("fires the moment that one releases"). Probed on the
    board with a 3 s hold and a rule due 1.5 s into it: the second rule never
    went on air and its next fire was pushed 54.5 s out. The turn is now spent
    only on a fi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
2026-07-31 docs: record the timer review fixes in STATUS.md
    The interval-timer section described the pre-fix behaviour: it promised a
    queued rule fires the moment another releases (it lost a whole period), said
    nothing about a hold refusing a muted stream or about a deleted preset
    pausing the rules that showed it, and still counted 24 checks.
2026-07-31 docs: the AP bounce needs no controller restart, and needs patience
    Re-verified tonight against the live rig. Two corrections to the remedy
    ladder, both measured:
    The controller restart the ladder pairs with the bounce is obsolete --
    bind_egress() already recovers on its own (sync send fails, socket is
    recreated, egress re-bound 4 s later, slave rediscovered 2 s after that,
    daemon never touched). Restarting costs a rebuffer on every scope to fix
    something that fixes itself.
    And the bounce looks like it failed if you measure it too early. At 60 s the
    rig read WORSE than before -- 72% ENOBUFS against 43%, slave rx 15/s against
    56, buffer at 0 -- which is just reassociation plus rate-control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
2026-07-31 controller: count the packets that never reach the air
    stream_loop dropped a failed sendto on the floor with a bare `except OSError:
    pass`. On a bad night that discarded 43% of every packet generated, invisibly,
    and the loss then looked identical to WiFi loss from every angle we had --
    which is how an evening went to blaming the air for something happening
    inside this box.
    Now counted per slave (with four scopes the question is always *which* link
    is under pressure), published to /api/state once a second, and shown on the
    dashboard right next to lost/s so the two can finally be told apart:
    lost/s high with tx-drop 0 is the air; tx-drop high is us, and no amount of
    antenna will help. A throt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
2026-07-31 controller: measure multicast audio, reject it on the numbers
    The four-slave airtime worry is real -- 800 pkt/s offered loses ~14% to
    EAGAIN before it reaches the air, and EAGAIN already appears at 400 pkt/s.
    Sending one multicast packet instead of N unicasts is not the fix: it is
    12.8x worse per packet.
    Group-addressed frames go out at the lowest basic rate (~1 Mbit/s here),
    not the negotiated per-station rate. Saturating both paths from the board:
    unicast 1282 pkt/s 780 us/pkt 10.13 Mbit/s
    multicast 100 pkt/s 9980 us/pkt 0.79 Mbit/s
    The stream needs 200 pkt/s, so multicast cannot carry one slave, never mind
    four; it would not break even until ~13. Not DTIM buffering e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
2026-07-31 controller: two slaves does not fit, and SO_SNDBUF does not rescue it
    Follow-on to the multicast measurement. Six rounds alternating 200 and 400
    pkt/s so both loads see the same phase of an unstable link:
    200 pkt/s (1 slave) 5/6 rounds clean, median 0.0% local loss
    400 pkt/s (2 slaves) 0/6 rounds clean, median 21.0% local loss
    One slave is the honest maximum today.
    The tempting rebuttal is that these drops are EAGAIN -- a local queue
    overflow, not air loss -- so a deeper send buffer should ride through the
    documented ath10k deaf-stall, since at LEAD_US=450 ms a packet delayed
    300 ms still beats its deadline. That contradicted the earlier decision to
    leave SO_SNDBUF alone, so it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
2026-08-21 slave: the MODE long press kills the radio, and the next boot brings it back
    The gesture was already in DESIGN §7 and already wired -- long press flipped
    net_rx::set_radio() -- but it only stopped the radio and left everything else
    telling a different story. Mode stayed NETWORK, so both LEDs went dark, which
    §7 reads as "radio off / not configured" on a unit that is in fact rendering
    its mic; and the controller kept unicasting 200 pkt/s at a station that had
    just deauthed, until its 30 s roster eviction ran out.
    Now one function moves the three things that have to agree. set_wifi_enabled()
    stops the radio, forces LOCAL, and resets the local pattern to MIC, so the
    amber LED means what §7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
2026-08-21 unoq: per-node switches and pair cycles; drop hybrid and blackout
    Slave draw modes had four writers -- the slave sheet, "set all", a timer
    hold and the slave's own button -- so the only way to know what a scope
    would draw was to walk the rig. Now every node carries three switches
    (stream / logos / artists, ~/hype_nodes.json, keyed by slave id so they
    can be set with the rig in its flight case) and policy_loop is the only
    thing that sends set_mode: a node is on the stream when what is on air is
    switched on for it, and on its own mic otherwise. It compares against the
    1 Hz STATUS beacon and re-sends no sooner than 3 s, so a node that
    reboots or has its button pressed is pulled back without any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
2026-08-21 unoq: drop the dead nav variable, correct the README's timer section
    curPresetIdx outlived the preset-stepping goPrev/goNext it belonged to.
    README section 6 still described the pre-policy hold: "the targeted
    slaves are switched to STREAM ... each target's previous draw setting is
    put back". Neither happens now -- fire_timer sends no set_mode and
    end_hold re-derives modes from the switches -- so the numbered list
    contradicted the block further down that documents the change. The two
    bullets under it were wrong in the same direction: a targeted hold DOES
    now put non-targets on their own mic, and the cooldown exists because two
    stings back to back read as a fault, not because a mode snapshot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
